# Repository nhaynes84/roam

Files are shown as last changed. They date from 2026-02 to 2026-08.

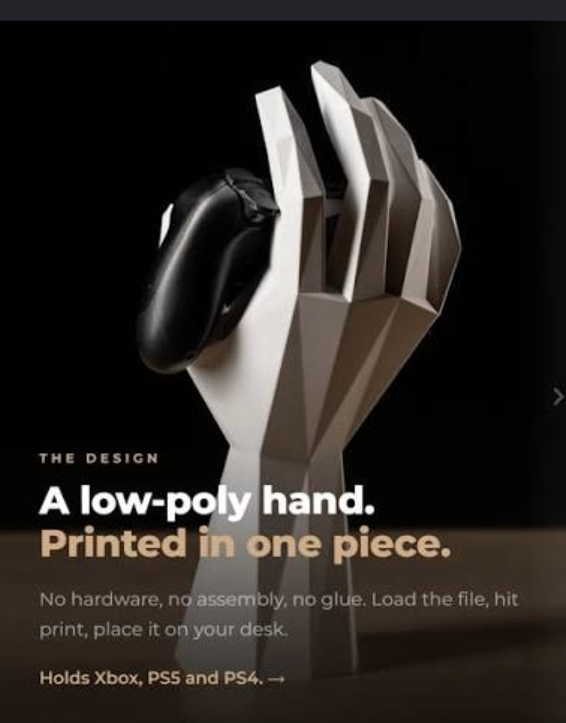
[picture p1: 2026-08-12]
roam-touch/cad/ref/lowpoly-3-printed-hand.png

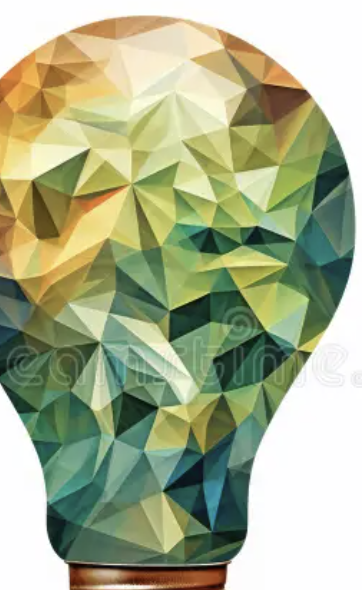
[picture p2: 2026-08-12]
roam-touch/cad/ref/lowpoly-1-bulb.png

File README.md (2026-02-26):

# Roam

Wrist-mounted tactile controller for hands-free AI interaction. Four buttons, OLED display, haptic feedback — strapped to your forearm, operated by the opposite hand.

**Hardware**: Raspberry Pi Pico 2 W, 1.3" OLED (SH1106), 4x tactile buttons, vibration motor, LED, 502535 LiPo battery.

**Firmware**: MicroPython running on the Pico 2 W.

**Housing**: 3D-printed case designed in OpenSCAD — ergonomic half-moon dome shape.

## Project Structure

```
roam/
├── firmware/          # MicroPython source (flashed to Pico)
│   ├── main.py        # Entry point
│   ├── buttons.py     # Button input + debounce
│   ├── display.py     # OLED rendering
│   ├── haptics.py     # Vibration motor control
│   └── config.py      # Pin assignments, settings
├── housing/           # OpenSCAD parametric case design
│   ├── common.scad    # Shared dimensions
│   ├── roam_case.scad # Top shell (dome)
│   ├── roam_lid.scad  # Bottom lid
│   └── render.sh      # STL render script
├── hardware/          # Wiring docs
│   ├── schematic.md   # Full wiring diagram
│   └── pinout.md      # GPIO allocation table
├── tests/             # Test scripts
├── Makefile           # Flash/reset/repl shortcuts
└── CLAUDE.md          # Claude Code project instructions
```

## Prerequisites

- **MicroPython**: Install the Pico 2 W MicroPython UF2 firmware
  - Download from [micropython.org](https://micropython.org/download/RPI_PICO2_W/)
  - Hold BOOTSEL, plug USB, drag UF2 to the mounted drive
- **mpremote**: `pip install mpremote`
- **OpenSCAD** (optional, for housing edits): `brew install openscad`

## Flash Firmware

```bash
# Copy all firmware files to Pico
make flash

# Or manually:
mpremote cp -r firmware/ :

# Reset the board
make reset
```

## Development

```bash
# Open REPL
make repl

# Flash + reset in one step
make deploy

# Render housing STLs
make render
```

## Wiring

See [hardware/schematic.md](hardware/schematic.md) for full wiring diagram and [hardware/pinout.md](hardware/pinout.md) for GPIO allocation.

Key connections:
- **I2C0** (GP4/GP5) → OLED display
- **GP10-13** → 4 tactile buttons (active low, internal pull-ups)
- **GP15** → Vibration motor via NPN transistor
- **GP16** → Status LED via 100Ω resistor
- **VSYS** ← TP4056 battery charger output

## 3D Printing

The housing is designed for FDM printing:
- **Case (dome)**: Print upside-down, 0.2mm layers, 3-wall, 20% infill
- **Lid**: Print flat-side down, 0.2mm layers
- **TPU pads**: Print the pad zones from roam_lid in TPU for forearm comfort

Render STLs:
```bash
cd housing
chmod +x render.sh
./render.sh          # full quality
./render.sh --fast   # quick preview
```

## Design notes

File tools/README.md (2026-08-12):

# Roam Tools — pushing a message to the wrist

The user wears ROAM Touch so he does not have to sit at the computer. These are
the tools that put something on it.

⚠️ **BLE is retired (2026-08-11).** `roam-send` (Swift/CoreBluetooth) and the
127-byte chunking are history — see git log if you ever need them. ROAM Touch is
a phone on the tailnet, reached over the network from anywhere.

## The one rule

```
agent / hook / script          the hub                     the bridge          the phone
   roam-msg  ──POST /notify──▶  decides: push or not  ──WS──▶  roam-push  ──adb──▶  📱
```

**`roam-msg` is the only thing you call. It never touches the device.**

The hub owns the notification policy — *reply where the last message came from*:
a prompt typed in tmux means he is at the keyboard, so its outcome (and every
status line about it) stays quiet; a message sent from ROAM means the answer
belongs on ROAM. That rule lives in exactly one place, `hub/hub.py`
(`_coverage_for`), and everything that wants the wrist obeys it by going through
the hub.

It was not always so. `roam-msg` used to shell straight to `adb`, so the policy
governed outcomes and nothing else and the phone rang all day while he sat two
feet from the screen it was about. Owner: *"what's the point of a 'hub' if all
traffic doesn't go through it..."*

## `roam-msg` — the client

```bash
~/Projects/roam/tools/roam-msg "Build complete. 0 errors."
~/Projects/roam/tools/roam-msg --pane 3 "needs your input"
```

* Attributes the message to `$TMUX_PANE` automatically, which is what lets the
  hub apply "he is typing in that pane". `--pane N` overrides it. With no pane
  at all (launchd, cron, ssh) it claims nothing and the hub files it on the
  `@host` channel, where nothing covers it, so it pushes.
* Prints what the hub decided — `%3 — no push (covered by tmux-input)` — so a
  silent send is never indistinguishable from a broken one.
* Lands in the ledger either way. `memsearch "…" --source ledger` finds it later.
* **If the hub process is not running the message goes into the ledger**, not to
  the device and not to a file. Everything here is one box, so an unreachable
  hub is a stopped process — and a stopped hub is a deaf bridge, so nothing
  could deliver anyway; an adb push at that moment would be the only thing
  still arriving on his wrist, reading as a healthy pipeline while every real
  outcome is stalled. The row lands in `hub.sqlite` flagged `pending`
  (`meta.offline: true`), and the hub adopts and pushes it on its next poll. So
  the message arrives late rather than never, from one store of record.
  Bounded: past `MAX_PENDING` (200) waiting messages it is dropped and says so.
* Env: `ROAM_HUB`, `ROAM_HUB_TOKEN_FILE`, `ROAM_HUB_TIMEOUT`.

## `roam-notify` — fire and forget

`roam-msg` backgrounded with output discarded. For hooks that must not block or
print.

## `roam-push` — ⚠️ the device transport, not for you

The only program that speaks to the phone (`adb ... cmd notification post`). It
holds no policy: told to post, it posts. **Only the bridge
(`com.talos.roam-bridge`) runs it.** Calling it by hand bypasses every rule
above and rings his phone while he is reading the pane it is about — which is
the exact bug the split exists to fix.

It makes a **sound**, and cannot be silenced from here: `cmd notification post`
hardcodes channel `shellcmd` at `IMPORTANCE_DEFAULT`, and Android 10 (SDK 29, on
the device) has no `cmd notification` subcommand for importance. The fix is for
Nexus to post these itself on an `IMPORTANCE_LOW` channel — it already runs a
foreground service with one and already holds the hub socket — after which the
adb path retires entirely. Failing that, one long-press → *Silent* on a ROAM
notification locks the channel down for good.

## Tests

`roam-msg` is a hub client, so its tests live with the hub:

```bash
cd ~/Projects/roam/roam-touch/hub && .venv/bin/python -m pytest -q
```

`tests/test_roam_msg.py` asserts the architecture, not just the behaviour: the
client cannot reach the device, does not second-guess the hub, and the bridge
does not shell out to the client (which would notify itself in a loop).

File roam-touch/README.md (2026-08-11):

# ROAM Touch — a forearm terminal for the AI stack

Spec locked 2026-08-11. **Nothing built.**

> ⚠️ **This supersedes the 2026-08-10 revision of this file**, which specified an
> ESP32-3248S035C ("CYD") desk console. None of that survives — not the board, the form factor,
> the power model, or the audio plan. See [Why the CYD died](#why-the-cyd-died).

★ **This absorbs the wrist Roam.** They are no longer complementary devices. One arm-mounted unit
does target selection, push-to-talk, and display.

## THE THESIS

> **"A functional arm-strapped computer, voice-controlled predominantly, that frees me from
> sitting at a computer. NOT a phone strapped to my arm."** — owner, 2026-08-11

Voice is the input. The screen reads output and confirms input — you never *drive* from it. This is
not an aesthetic project; function first. Read this before proposing any UI.

## WHAT IT IS

A forearm bracer with a flip-up AMOLED panel, running Linux, that acts as a control
surface for every Claude session on every box you own — at home over WiFi, or anywhere over
Tailscale.

Think Slack, for AI tools, on your arm. **N devices × N targets; each target is one channel with
one call/response thread.** For V1, a channel is a tmux pane running Claude.

The interaction loop:

1. Pick the target channel on the touchscreen.
2. Push to talk. Whisper (already running on talos) transcribes it.
3. Panel shows **"send «transcript» to «channel»?"** → Send / Redo / Cancel.
   One confirmation covers both the words *and* the routing, so a good command can't land in the
   wrong session.
4. **Receipt** comes back immediately — it got there.
5. **Outcome** arrives whenever it's done, into that channel's thread, to read or hear.

## WHY LINUX, NOT AN MCU

★ **An ESP32 cannot run Tailscale.** That single fact drove the entire redesign.

Every earlier version of this document contorted itself around that limitation — BLE tethering to
a phone that *could* reach the tailnet, two transport paths, a protocol written twice. Moving to
Linux deletes all of it: the device is just a tailnet node, and "local" and "remote" become the
same code path with no phone in the loop.

It also hands back, for free: a native UI instead of LVGL partial buffers on 520 KB of SRAM,
working audio through ALSA, and a real application platform.

## LAYOUT

| where | contains |
|---|---|
| **Panel** (moves) | CM4 + 3.92" AMOLED 1080×1240, **married** so DSI never crosses the hinge · aluminium backplate · memory-LCD status strip on the outer face |
| **Base** (fixed) | BBQ20KBD keyboard, 5000 mAh cell stacked beneath it |
| **Band** | ESP32-C6 companion. The strap is a partial cuff, not a full wrap. |
| **Across the hinge** | power + keyboard I2C/USB **only** — nothing fast, nothing fragile |

Lid position is sensed by a **magnet in the panel and a hall sensor in the base**, so *zero*
conductors cross the hinge for sensing, and there's no switch to wear out.

## COMPUTE — Raspberry Pi CM4 (2 GB, eMMC, external antenna)

- ⚠️ **Pi Zero 2 W has no DSI at all** (CSI only). It cannot take this panel natively.
- **Radxa Zero 3W** is tempting — 65×30 mm, WiFi 6 — but RK3566 mainline support lags Raspberry
  Pi's by a wide margin, which means writing the panel driver inside a vendor BSP kernel.
- **CM4 wins on display stack**, which is the scarce resource here. Not CPU.
- **eMMC, not SD** — boot speed is load-bearing (see power states) and SD cards corrupt under the
  abrupt power cuts the companion performs.
- **External antenna** — a body absorbs 2.4 GHz. Mount it on the outer face, away from the arm.

## ⚠️⚠️ HARD GATE: NO PANEL WITHOUT A DATASHEET

The AMOLED is not a Pi-supported display. Its timings and init sequence get written by hand from
the manufacturer's documentation.

**No datasheet → DSI is impossible.** The fallback is an HDMI→MIPI driver board, which works
precisely because it contains a controller that already knows the panel. Plenty of sellers ship
these modules with nothing but a wiring photo. **Never buy on specs alone.**

## POWER — three states

| state | on | draw | wake |
|---|---|---|---|
| open / active | Linux + AMOLED | 1–2 W | — |
| closed, **warm** (recent use) | Linux idling, screen off | ~300 mA | instant |
| closed, **cold** (>30 min idle) | companion only, Linux **power-gated** | ~110 µA | boot |

At 5000 mAh: hours active, 2–3 days of instant-on standby, months truly stowed. The warm→cold timer
means you never eat a boot mid-use, only when returning hours later.

### ⚠️ Do not chase suspend-to-RAM

ARM Linux suspend is a swamp. PinePhone Pro draws **1250 mW in s2idle**; most postmarketOS mainline
devices lack runtime power management entirely; where it exists it fails intermittently (suspend
breaking on certain kernels, or when the charger is connected).

The one platform that does it well — PinePhone, ~100 h idle — gets there via **crust**, firmware
running on a *separate co-processor* whose only job is babysitting power. The mobile-Linux world
independently invented our companion architecture.

**So: power-gate instead.** Boot time is tractable engineering; suspend is an open-ended bug hunt.

## COMPANION — ESP32-C6

Owns the WebSocket to the hub, the hall sensor, the haptic motor, the status strip, and the CM4's
power rail.

- **C6 specifically, for WiFi 6 TWT**: ~110 µA while associated, versus 2–5 mA on legacy DTIM.
  ⚠️ TWT requires a WiFi 6 AP *and* is optional in 802.11ax — verify per router. "WiFi 6" on the
  box is not sufficient.
- ⚠️ **nRF52840 / XIAO is disqualified: no WiFi.** It could only reach the hub via the phone,
  reinstating the dependency Linux just removed. Its excellent idle draw is real and irrelevant.
- ★ **Don't poll while closed.** An idle WebSocket with DTIM-aligned keepalives costs less than
  repeated wake/handshake/teardown, *and* delivers instantly.
- Message lands while stowed → status strip shows it, haptic buzzes → flip open and it's already
  there. Boot latency hides behind reading you'd be doing anyway.

## HUB AND CHANNELS

The hub is **talos** — always-on, on the tailnet. Channels have history: an outcome may land
minutes after the command while you're looking at something else. **The hub holds state; the panel
is only a view.** The ESP32 could never hold this itself, and doesn't have to.

Per device: discover with `tmux list-panes -a -F`, route with `send-keys -t %3`, read back with
`capture-pane`. Every box runs the same small agent and advertises its panes.

- ⚠️ **Key channels on tmux pane IDs (`%3`), never `session:window.pane` indices.** Indices
  renumber when panes close, so channels would silently re-point at the wrong pane — the worst
  possible failure for a device whose entire job is "send this to exactly that."
- ★ **The receipt and outcome signals already exist.** The "Sent" and "Ready" hooks described in
  `../CLAUDE.md` fire on prompt-submit and response-finish. They need to POST to the hub tagged
  with `$TMUX_PANE` instead of pushing straight to BLE.

## SOFTWARE SPLIT

STT and the hub link are **system services**, so one global PTT gives every application voice input.

★ **The channel client is app #1, and V1 ships only it.** "Run network diag", "ssh to argus" are
things you *say to a channel*, not separate apps you open — a launcher would be phone thinking.
More apps when they earn it: **Home Assistant is the obvious second**, and it closes the loop on
the original "00s smart-home controller" idea. It also reuses the same Whisper/Piper services the
HA satellites already share. **Lean, not closed** — it's Linux, so don't design against other uses;
just don't build for needs that don't exist yet.

Useful test for anything proposed later: if it fits *pick target → speak → confirm → read result*,
it belongs. If it needs you poking at the screen, it's the phone-on-your-arm thing.

- **Native toolkit, not Chromium.** A browser at 1080×1240 is exactly what would force CM5-class
  compute and a thermal problem. A native UI runs comfortably on far less.
- ⚠️ Keep a minimal text-entry path. **You cannot voice-type a password** — you'd say it out loud
  and Whisper would mangle it anyway. That is what the keyboard is for, not general typing.

Voice services already live on talos under launchd:

| leg | service | endpoint |
|---|---|---|
| speech → text | Wyoming faster-whisper `small-int8` | `talos.local:10300` |
| text → speech | Wyoming Piper `en_US-lessac-medium` | `talos.local:10200` |

## THERMAL — the plastic does not conduct, the metal does

PLA/PETG is ~0.13–0.25 W/m·K. Aluminium is ~167. Through-thickness conduction through a 2 mm wall is
fine; ★ **lateral spreading is what dies.** Heat from a ~15 mm chip punches straight through in a
hot spot and 95% of the panel contributes nothing. A metal spreader on the hot path is not optional.

- ★ **Thermals match the duty cycle.** Panel **open** = CM4 working = both faces in free air, the
  best-ventilated surface on the device. Panel **closed** = CM4 power-gated = no heat to dump.
  Compute belongs in the panel; the battery — the heavy part — stays in the base.
- ⚠️ Don't sit the CM4 behind the emissive area. OLEDs age faster hot. Offset it toward the hinge.
- Fans are unnecessary for a bursty 1–2 W load. If one is ever added, **seal it inside** and trigger
  on temperature — on a body-worn device **sweat ingress is the real killer, not heat.** Never open
  a vent to the outside.

## MATERIALS — per function, not one choice

| part | material | why |
|---|---|---|
| hinge, structure | **PA-CF** | stiff, HDT >100 °C. ⚠️ hygroscopic — keep off skin and sweat |
| skin contact, cosmetic shell | **PETG / PCTG** | no moisture uptake, adequate UV. PCTG buys *toughness*, **not** heat — same ~85 °C Tg |
| panel backplate, hot path | **aluminium** ★ LOCKED | ~167 W/m·K at 2.7 g/cm³ — better conductor *and* 1/3 the weight of brass |

⚠️ **Never PLA.** Glass transition 55–60 °C; it will deform behind the board and in a hot car.

### Backplate sourcing — aluminium, 1 mm

**SendCutSend** takes DXF/DWG/EPS/AI/STEP with instant pricing and no minimums, and offers laser
engraving as an add-on. 2–4 day lead, free US shipping.

A 100×70×1 mm plate is **~19 g in aluminium**. The plate hangs off the hinge, so its mass is
cantilevered, not carried.

⚠️ **Brass was considered and rejected (2026-08-11).** It was an *aesthetic* pick presented as a
thermal one — thermally fine at ~120 W/m·K, but 3× the density (~60 g for the same plate) for zero
functional gain, on a device with no aesthetic brief. Noted so it doesn't get re-proposed.

Reference, if a copper alloy is ever revisited: **CO2 lasers cannot cut brass or copper** — too
reflective at 10.6 µm, and the reflection can damage the tube. Those need a fiber laser (1.06 µm)
or waterjet. Aluminium is unaffected.

## WHY THE CYD DIED

The 2026-08-10 concept was an ESP32-3248S035C desk console. Every constraint that shaped it turned
out to be soft, except one:

- **"The board is what I own."** It's a wall/desk board: no PMU, no charger, no fuel gauge, no
  battery connector, 5 V input, 101×55 mm of rigid bare-backed PCB. Wrong for worn-and-battery.
- **"480×320 is the screen size available."** That was a catalog limit, not a physical one. Phone
  AMOLED panels and HDMI→MIPI driver boards exist; the ESP32 dev-board ceiling was irrelevant.
- **"307 KB framebuffer against 520 KB SRAM."** An artifact of using an MCU at all.
- **"Echo is the hard problem."** It was the hard problem *for an always-listening single-mic
  panel*. Push-to-talk plus a hinged, stowable device makes it mostly moot.
- **⚠️ "An ESP32 cannot run Tailscale."** This one was real, and it is the reason for every change
  above.

## OPEN

- Bracer internal volume (drives final battery and board fit)
- Exact ESP32 placement on the band
- Where the status strip sits, which determines whether SPI crosses the hinge
- Which SSID talos lives on — TWT needs the WiFi 6 network, and moving talos there also unthrottles
  its 6E radio (it currently negotiates 11ac). Note it would need a fresh DHCP reservation.

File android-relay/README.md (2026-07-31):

# Roam Android Relay

Native Android relay for the Roam phone-owned mode.

Flow:

```
Roam/XIAO BLE -> Android foreground service -> TCP over Wi-Fi -> Mac receiver
```

The app scans for `Roam`/`Roam2`, connects to service `FF00`, subscribes to:

- `FF02` action/status notifications
- `FF03` audio notifications

It writes `FF04` control commands back to Roam. For the first vertical slice, pressing the Roam Android dictation action toggles mic streaming by sending `start audio` / `stop audio`.

The Mac receiver listens on TCP port `8765` by default:

```bash
node scripts/roam-relay-receiver.mjs
```

For the current tmux assistant workflow, run the durable receiver from the repo:

```bash
scripts/start-roam-relay-tmux.sh 8765
```

This starts a `roam-relay` tmux session, transcribes Roam PTT audio with local
`mlx_whisper`, and injects transcripts into the configured tmux target with
`ROAM_RELAY_INJECT_MODE=tmux-submit`. The default `ROAM_TMUX_TARGET` is `0:0`;
set it explicitly when the assistant lives in another tmux window.

Status feedback goes back to Roam through the same socket. The receiver sends
frame type `3` text to Android; Android chunks it into `FF01` writes for the
wrist display. In `tmux-submit` mode the message is already submitted when Roam
shows `Sent`. In draft mode (`ROAM_RELAY_INJECT_MODE=tmux`) Roam shows `Ready`;
press Middle short/action `10` to submit after that.

Long receiver feedback is split into numbered one-screen pages before it is
broadcast. The receiver sends the final page first and page `1/N` last, so
Roam's newest-message view starts at the beginning and the older/down scroll
button moves through the rest of the reply.

The relay service source also waits 300 ms after each `FF01` text write before
draining the next GATT operation. This protects the current firmware path where
text writes are consumed by the main loop instead of acknowledged at the
application layer.

Manual updates can be pushed through the relay without taking over BLE:

```bash
scripts/roam-relay-notify.mjs "Build complete"
```

For today's work Mac, set the Android app host to this Mac's LAN IP. On the
2026-07-30 workbench that was `192.168.86.63`.

When the Mac mini becomes the always-on business proxy, install the receiver
there and point the Android app at the Mac mini's reserved LAN IP:

```bash
scripts/install-roam-relay-launchd.sh
```

That installs `~/Library/LaunchAgents/com.roam.relay-receiver.plist`, keeps the
receiver alive, and writes logs to `~/Library/Logs/Roam/relay.out.log` and
`~/Library/Logs/Roam/relay.err.log`. The rolling WAV capture is
`~/Library/Logs/Roam/roam-relay-latest.wav`.

Per-session WAVs are under `~/Library/Logs/Roam/sessions/`. Transcript and
injection audit records are appended to `~/Library/Logs/Roam/transcripts.jsonl`.

To capture decoded relay audio for inspection:

```bash
node scripts/roam-relay-receiver.mjs --wav /tmp/roam-relay.wav
```

The receiver frame format is `[type:1][length:2 big-endian][payload]`; type `1`
is event JSON and type `2` is the binary `FF03` audio packet.

The current debug APK is built at:

```bash
android-relay/app/build/outputs/apk/debug/app-debug.apk
```

For bench testing over ADB on current Android builds, start through the visible
Activity path. This avoids foreground-service launch denial while the phone is
locked or dreaming:

```bash
adb shell input keyevent KEYCODE_WAKEUP
adb shell wm dismiss-keyguard
adb shell am start -S -W --user 0 -n io.roam.relay/.MainActivity --es host 192.168.86.63 --ei port 8765 --ez autoStart true
```

The protected broadcast receiver exists for controlled starts when Android
allows them:

```bash
adb shell am broadcast -n io.roam.relay/.RelayControlReceiver -a io.roam.relay.START --es host 192.168.86.63 --ei port 8765
```

Stop it with:

```bash
adb shell am broadcast -n io.roam.relay/.RelayControlReceiver -a io.roam.relay.STOP
```

Build notes:

- Open `android-relay/` in Android Studio.
- The local machine currently has Android SDK/ADB but no `gradle` CLI in PATH.
- Android 12+ requires Bluetooth runtime permissions.
- Android 13+ requires notification permission for the foreground-service notification.
- Android 14+ requires `foregroundServiceType="connectedDevice"` plus the matching permission.

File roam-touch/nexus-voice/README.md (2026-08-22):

# Nexus Voice

Speak to the ROAM Touch channels through Home Assistant. Wake word, then
*"Nexus, add the OPV result to the espresso notes"* — it finds the right
channel, sends it, and speaks the answer back on the device you asked from.

## Why HA is in the middle

The hub binds to the **tailnet address only** (`100.67.237.109:8787`); the LAN
gets connection refused. An ESP32 cannot run Tailscale — the fact that killed
the MCU version of ROAM Touch. So a satellite can never reach the hub directly.

`argus` is the only box on both networks. HA is therefore not a convenience
here, it is the bridge, and the integration lives *inside* it — which also
means it calls `tts.speak` through the service registry and needs no
long-lived access token.

## The loop

```
ESP32-S3 / Sonos ──wake word──▶ HA (argus)
                                  │  Whisper @ talos:10300
                                  ▼
                          local intents first  ──▶ lights, scenes  (<1s)
                                  │ "Nexus, …"
                                  ▼
                          nexus_voice agent ──▶ hub /send ──▶ tmux pane
                                  │
                          "Sent to Gaggia Build."   ◀── spoken immediately
                                  ⋮
                          outcome event ──▶ tts.speak ──▶ same device
```

**Nothing here waits for Claude.** Assist is synchronous and wants an answer in
about a second; a Claude turn takes minutes. The agent acknowledges, and the
answer arrives later as an announcement. That is the hub's own shape — receipt
now, outcome later.

## How a channel is chosen

Three layers, cheapest and most certain first:

1. **String** — exact label, then subset of content words. Free and certain.
2. **Embedding** — `nomic-embed-text` on talos, over the channel's *label plus
   recent history*.
3. **Neither** — spawn a new channel.

Two candidates within `AMBIGUITY_DELTA` produce a question rather than a guess.
Misfiling a note corrupts two threads; one extra second of conversation is
cheaper.

### ⚠️ What the measurements actually said (2026-08-21)

Embedding the **label alone does not work**. "the espresso notes" scored 0.365
against "Gaggia Build", while an unrelated "jeep brake booster" scored 0.504
against the same channel. Short proper nouns carry almost no signal.

Embedding **label + history** fixed the ranking but not the scale — the useful
signal is the **margin between #1 and #2**, not the absolute score:

| utterance | #1 | #2 | margin | correct |
|---|---|---|---|---|
| the espresso notes | 0.508 | 0.435 | 0.073 | ✓ Gaggia Build |
| wrist display font | 0.431 | 0.367 | 0.064 | ✓ Roam Touch |
| the augment board | 0.425 | 0.375 | 0.050 | ✓ Augment |
| jeep brake booster | 0.422 | 0.418 | **0.004** | ✓ spawn |

When nothing fits, the scores go **flat**. That is the only reliable "none of
these" signal available. ⚠️ **n=5** — the threshold fits the measurements, it
is not validated by them. Re-run `tools/probe_routing.py` against real traffic
before trusting it further.

`cwd` is kept but is **not load-bearing**: every live channel on the hub reports
`/Users/talos`, because panes spawn in `$HOME` unless someone passes `cwd`. It
breaks ties and decides nothing.

## Laws this obeys

* **Nothing ever speaks on its own.** Audio fires only for an answer he asked
  for by voice, on the device he asked from. Auto-speak was built into the
  Channels app once and killed within the hour.
* **Speak the `summary`, never the `body`.** Capped at 280 chars, markdown
  stripped — and short enough for a satellite with no echo cancellation, which
  cannot hear you interrupt it.
* **Reply where the last message came from.** A satellite is one more place
  that rule applies to; HA hands us `satellite_id` so it needs no identity
  scheme of its own.

## Layout

| file | what |
|---|---|
| `matcher.py` | which channel — pure, no HA, no network |
| `phrasing.py` | trigger stripping, channel naming — pure |
| `runtime.py` | channel index, embedding cache, hub WS, delivery map |
| `hub.py` · `embeddings.py` | clients |
| `conversation.py` · `__init__.py` · `config_flow.py` | HA glue, decides nothing |

Tests: `.venv/bin/python -m pytest tests/ -q` (53). The HA-facing modules are
verified by importing them against real HA on argus, since HA is not installed
on talos.

## Deployed

`/home/homeassistant/.homeassistant/custom_components/nexus_voice` on **argus**.
Restart HA after changing it: `sudo systemctl restart home-assistant@homeassistant`.

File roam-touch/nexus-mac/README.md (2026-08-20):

# Nexus for macOS

Native SwiftUI client for the ROAM Touch hub (`../hub`, contract in `../hub/API.md`).
Same hub, same channels, same rules as the Android Nexus — this is the desk view.

- Build: `swift build` (Command Line Tools are enough; no Xcode required)
- Test: `swift test`
- Run (dev): `swift run`
- App bundle: `tools/bundle.sh` → `dist/Nexus.app` (ad-hoc signed)

Config resolution order:
1. `ROAM_HUB_URL` / `ROAM_HUB_TOKEN` environment variables
2. `~/.config/roam-nexus/config.json` — `{"base_url": "http://talos:8787", "token": "…"}`
3. On talos itself: `../hub/hub-token.txt` with the default base URL

House rules carried over from the Android client (see `hub/API.md` and the
roam-touch-channels memory before changing behaviour):
- Summary first, body on demand. Never re-derive summaries client-side.
- Nothing speaks or notifies on its own. Coverage/push is the hub+bridge's job.
- Presence covers ONLY the channel on screen. `covers_all` from a client with a
  screen once silenced the wearer's arm for a day.
- Interrupts go through `POST /channels/{pane}/interrupt`, never control bytes
  through `/send`.

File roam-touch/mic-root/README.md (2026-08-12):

# mic-root — temporary-root test for the ROAM Touch built-in microphone

The built-in mic returns pure digital silence and the HAL logs
`start_input_stream: pcm_prepare returned -1` on every configuration. A Bluetooth headset mic
works, which proves AudioFlinger, the HAL framework, tinyalsa and the app are fine — and proves
**nothing** about the codec driver, the ADSP audio firmware or the ACDB calibration, because SCO
bypasses all three. Those three live in the vendor partition that the 8.0 → 10 flash replaced, so
"we broke it in software" and "the hardware is dead" are both still live.

`tinycap` is on the device but `shell` is not in group `audio` (1005), so there is no root-free way
to reach ALSA. This directory is the root-free-of-consequences way to get there.

## Files

| file | what it is |
|---|---|
| `PROCEDURE.md` | the numbered checklist for the owner, plus the recovery path |
| `prepare-boot-image.sh` | host-side: builds the Magisk-patched boot image (already run) |
| `TESTmicroot.sh` | on-device, as root: the capture ladder |
| `TESTmicroot-hal.sh` | on-device, as root: the kernel log under a HAL capture attempt |

The patched image is **not** in git (34 MB binary). It is staged at
`~/pixel/TESTmagisk-boot-sailfish-QP1A.191005.007.A3.img` on both `nicks-macbook-pro` and talos,
sha256 `234c1186c2e05a3c0bbe75b35e5361593b0a340d84d4ec5d0f115f4ed4105c43`.
It is for `fastboot boot` only. Rebuild it with `prepare-boot-image.sh`.

## Verified before anyone touched the phone

- Stock `boot.img` taken from the staged factory image for the exact running build
  (`QP1A.191005.007.A3`), sha256 `b020dba9…b445`.
- Patched on-device with Magisk v30.7's own `boot_patch.sh`, with the flags the Magisk app would
  have computed for this device: `KEEPVERITY=true KEEPFORCEENCRYPT=true PATCHVBMETAFLAG=true
  RECOVERYMODE=false LEGACYSAR=true`.
- `LEGACYSAR=true` is load-bearing. sailfish is a legacy system-as-root A/B device: the boot image
  carries the *recovery* ramdisk and the bootloader passes `skip_initramfs` on a normal boot, so
  the ramdisk is skipped. magiskboot hex-patches the kernel `skip_initramfs` → `want_initramfs`
  so the flag no longer matches and magiskinit (now `/init` in that ramdisk) runs and performs the
  system-as-root mount itself. Confirmed in the patch log:
  `Patch @ 0x017853F6 [736B69705F696E697472616D667300] -> [77616E745F696E697472616D667300]`.
- Re-verified on the finished image: ramdisk `cpio test` → 1 (Magisk-patched), `init` is 200 KB
  (magiskinit), kernel contains `want_initramfs` ×1 and `skip_initramfs` ×0.

## The route the test drives

sailfish's mics are **digital MEMS mics on the WCD9335 (Tasha) DMIC ports**, not analog inputs.
From `/vendor/etc/mixer_paths.xml`, `handset-mic` = `dmic1` + `DEC7 Volume 88`, i.e.

```
MultiMedia1 Mixer SLIM_0_TX = 1      front-end -> SLIMBUS_0_TX backend
AIF1_CAP Mixer SLIM TX7     = 1      codec TX port 7 into the SLIMbus capture stream
SLIM_0_TX Channels          = One
SLIM TX7 MUX                = DEC7
ADC MUX7                    = DMIC
DMIC MUX7                   = DMIC0  bottom mic
IIR0 INP0 MUX               = DEC7
DEC7 Volume                 = 88
```

The other two physical mics ride different decimators and different TX ports: back mic =
`dmic3` (DMIC2 / DEC6 / TX6), top mic = `dmic6` (DMIC5 / DEC5 / TX5). Testing all three separates
"one dead mic" from "the whole capture chain is down".

## Reading the result — what it does and does not prove

| observed | supports | still does NOT prove |
|---|---|---|
| Rung A already fails (front-end alone, no backend) | the ADSP audio session cannot start at all — a firmware/DSP-level fault, not a microphone | which side put the ADSP in that state |
| A/B pass, C onward fail | the fault is on the SLIMbus link to the WCD9335 or in the codec's own bring-up | codec silicon vs codec firmware/driver — both sit behind that boundary |
| A–C pass, D/E/F all fail to **prepare** | the codec is reachable but the DMIC capture chain will not start | that the mics themselves are dead. A cracked mic joint cannot make `pcm_prepare` fail |
| D/E/F **prepare and deliver samples** | the kernel driver, the codec and the ADSP can all bring the capture path up — the failure is above them, in the HAL / ACDB / vendor config, i.e. plausibly ours | that a specific config file is the culprit; that has to be found separately |
| samples arrive but are all-zero on all three mics | the digital chain runs and no acoustic energy reaches it | dead elements vs a DMIC clock that is never driven vs calibration zeroing the decimator |
| samples arrive at a real noise floor (≈ −60 dBFS) and rise on speech | that mic works below the HAL, full stop | nothing further is needed for that mic |

**The honest framing:** a `pcm_prepare` failure is a *session-start* failure. A cracked solder
joint on a mic, or a dead MEMS element, does not make a session fail to start — it makes a session
start cleanly and deliver silence. So this test is a strong discriminator between
"session cannot start" (driver / ADSP firmware / codec bring-up) and "session starts, no sound"
(the mic itself, its clock, or calibration). It is **not** a silicon test. If every rung fails
identically, that points hard away from a single cracked joint and toward the vendor stack, but
the only thing that would settle "we broke it" outright is reflashing the original 8.0 image and
testing the mic first — which costs the whole current setup.

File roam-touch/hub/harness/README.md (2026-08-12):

# Harness tools (copies)

`~/.local/bin/` is not a git repository, so these are **copies** of the owner's live
harness tools as extended for the ledger/session sources. The live files are the ones
that run; these exist so the change is reviewable and recoverable.

* `memindex` — added the `ledger` and `sessions` record sources (chunked by
  `../ledger_index.py`), FTS5 (`chunks_fts_v2`) population and backfill, and a
  `record_files` mtime/size guard so unchanged transcripts are never reparsed.
* `memsearch` — added `--exact` (FTS5 literal match) and the two new sources.

Originals before the change: `~/.local/bin/backups/*.2026-08-11.bak`.

If you edit the live tools, re-copy them here.

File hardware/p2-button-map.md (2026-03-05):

# Roam P2 — Button Command Map

## Button Layout

```
            ┌──────────────── elbow side ────────────────┐
            │                                            │
            │   [Index]  [Middle]  [Ring]  [Pinky]       │  ◄── top face
            │     D0       D1       D2      D3           │
            │                                            │
  USB-C ◄───│                              [Scroll Fwd]  │
  Switch ◄──│                               D8           │  ◄── right side
            │                              [Scroll Back] │
            │                               D9           │
            │                                            │
            └──────────────── wrist side ────────────────┘
```

## Command Map

| Button | Pin | Short Press | Long Press | Double Tap |
|---|-----|---|---|---|
| Index  | D0  | Dictation (macOS 0x00CF) | Tmux pane (Ctrl+B, o) | Scroll Fwd* |
| Middle | D1  | Cycle Mode (Shift+Tab) | BLE Switch (disconnect + re-advertise) | Scroll Back* |
| Ring | D2  | Approve (y + Enter) | Always (Tab + Enter) | Enter |
| Pinky  | D3  | Escape | Kill (Ctrl+C) | — |
| Scroll Fwd | D8 | Next message | Next message | — |
| Scroll Back | D9 | Prev message | Prev message | — |

*Index/Middle double-tap scroll is a fallback for P1 testing (no dedicated scroll buttons).
On P2, use the dedicated D8/D9 thumb buttons instead.

## Action Details

### Index — D0
| Gesture | Action | HID Output | Use Case |
|---|---|---|---|
| Short | Dictation | Consumer key 0x00CF | Start/stop macOS dictation |
| Long | Tmux Pane | Ctrl+B then 'o' | Switch tmux pane |

### Middle — D1
| Gesture | Action | HID Output | Use Case |
|---|---|---|---|
| Short | Cycle Mode | Shift+Tab | Cycle through UI modes |
| Long | BLE Switch | (internal) | Disconnect current host, re-advertise for next |

### Ring — D2
| Gesture | Action | HID Output | Use Case |
|---|---|---|---|
| Short | Approve | 'y' then Enter | Accept Claude Code prompt |
| Long | Always | Tab then Enter | Select "Always allow" option |
| Double | Enter | Enter | Confirm without 'y' prefix |

### Pinky — D3
| Gesture | Action | HID Output | Use Case |
|---|---|---|---|
| Short | Escape | Escape | Cancel / dismiss |
| Long | Kill | Ctrl+C | Kill running process |

### Scroll — D8 / D9
| Button | Action | HID Output | Use Case |
|---|---|---|---|
| D8 (Fwd) | Scroll Fwd | (local) | View newer BLE text message |
| D9 (Back) | Scroll Back | (local) | View older BLE text message |

Scroll buttons are local-only — they navigate the on-screen message ring buffer,
no BLE HID output. Short haptic buzz (40ms) on scroll.

## Timing

| Parameter | Value | Notes |
|---|---|---|
| Debounce | 50ms | Ignore presses shorter than this |
| Long press | 600ms | Fires while still held |
| Double tap window | 300ms | Max gap between taps |
| Action fade | 3000ms | Action name on screen duration |
| Screen dim | 10s | Dim after inactivity |
| Screen off | 30s | Power off after inactivity |

## Haptic Feedback

| Event | Motor pulse | Pattern |
|---|---|---|
| Button action (HID) | 80ms | Single buzz |
| Scroll | 40ms | Short buzz |
| BLE text received | 60-80-60ms | Double buzz |

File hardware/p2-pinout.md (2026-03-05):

# Roam P2 — XIAO nRF52840 Sense GPIO Allocation

## Pin Assignment Table

| Pin  | nRF GPIO | Function | Direction | Notes |
|---|---|---|---|---|
| D0 | P0.02 | Button 1 | Input | Index (Dictation) — internal pull-up |
| D1 | P0.03 | Button 2 | Input | Middle (Mode) — internal pull-up |
| D2 | P0.28 | Button 3 | Input | Ring (Yes) — internal pull-up |
| D3 | P0.29 | Button 4 | Input | Pinky (No) — internal pull-up |
| D4 | P0.04 | I2C SDA | Bidir | OLED display (TWIM1) |
| D5 | P0.05 | I2C SCL | Bidir | OLED display (TWIM1) |
| D6 | P1.11 | Motor PWM | Output | NPN base via 1kΩ |
| D7 | P1.12 | Status LED | Output | Via 100Ω resistor |
| D8 | P1.13 | Scroll Fwd | Input | Thumb button — internal pull-up|
| D9 | P1.14 | Scroll Back | Input | Thumb button — internal pull-up|
| D10  | P1.15 | (Available) | — | Reserved for future use |
| VBAT | — | Battery ADC | Input | Built-in, nRF52 internal ADC |

## Board Layout

```
              ┌───USB-C───┐
        D0  ──┤  [RST]    ├── 5V (VUSB)
        D1  ──┤           ├── GND
        D2  ──┤           ├── 3V3
        D3  ──┤           ├── D10
        D4  ──┤  (SDA)    ├── D9
        D5  ──┤  (SCL)    ├── D8
        D6  ──┤           ├── D7
              ├───────────┤
              │  BAT(JST) │
              └───────────┘

  [RST] = tiny tactile switch next to USB-C (top side)
  Double-click RST to enter UF2 bootloader
```

## I2C Configuration

| Bus | Peripheral | Pins | Speed  | Devices |
|---|---|---|---|---|
| TWIM1 | NRF_TWIM1 | D4, D5 | 100kHz | OLED display |

**CRITICAL: Must use TWIM1, not TWIM0.** The Bluefruit softdevice claims TWIM0
and its shared IRQ (`SPIM0_SPIS0_TWIM0_TWIS0_SPI0_TWI0`). Using TWIM0 with
Bluefruit causes I2C data writes to timeout. The firmware uses direct TWIM1
register access (not the Wire library) with proper timeouts.

**Do NOT use the Seeed BSP Wire library** — it has infinite spin loops
(`while(!EVENTS_STOPPED)`) with no timeout. A stuck I2C bus will lock the MCU.

## Display Options

### Option A: SH1106 1.3" 128×64 (Build 2A — current)

The same small screen used on P1. Proven reliable on I2C.

- **VCC from battery through switch** — charge pump works at LiPo voltages (3.7–4.2V)
- **No reset pin** on the 4-pin module (`PIN_DISPLAY_RST = U8X8_PIN_NONE`)
- **Column offset of 2** — SH1106 has 132-column RAM for a 128-column display

**Wiring (4-pin module):**

| OLED Pin | Connect to | Notes |
|---|---|---|
| GND | GND | |
| VCC | Switched BAT+ | Through power switch |
| SCL | D5 | |
| SDA | D4 | |

**U8g2 constructor:**
```cpp
#define DISPLAY_TYPE U8G2_SH1106_128X64_NONAME_F_HW_I2C
```

### Option B: SSD1309 2.42" 128×64 (Build 2B — pending)

Larger screen, 3.3V native (works on battery). Ships in SPI mode — needs
resistor mod for I2C. **Not yet proven working on I2C.**

- **3.3V compatible** — works on battery power
- **Requires resistor modification** for I2C mode (see below)
- **Reset pin**: connect RES to a GPIO or tie to 3V3
- **No column offset** (unlike SH1106)

**I2C resistor mod (back of module, under ribbon cable):**
Locate pads R9, R10, R11, R12 (may be hidden under the flex cable):
- Bridge R9 (3-pad selector — bridge middle pad to R9 side, not R8 side)
- Bridge R10, R11, R12
- Remove any existing bridges on R1–R4 (visible side)

The BS[2:1:0] pins set the interface: `010` = I2C mode.

**Wiring (7-pin header, I2C mode):**

| OLED Pin | Connect to | Notes |
|---|---|---|
| GND | GND | |
| VCC | 3V3 | 3.3V native |
| SCL | D5 | |
| SDA | D4 | |
| RES | D10 (or 3V3)  | Reset — tie high or use GPIO |
| DC | GND | I2C address select: GND = 0x3C |
| CS | GND | Not used in I2C, tie low |

**U8g2 constructor:**
```cpp
#define DISPLAY_TYPE U8G2_SSD1309_128X64_NONAME0_F_HW_I2C
```

**Status**: Commands (control byte 0x00) work but data writes (control byte 0x40)
timeout — the resistor mod may not have fully switched from SPI to I2C mode.
Needs a pre-configured I2C module or verified mod procedure.

## Battery

- Built-in JST SH 1.0mm connector — plug in LiPo, no external charger needed
- Charging via USB-C (onboard charging circuit)
- Battery voltage readable via `PIN_VBAT` (nRF52 internal ADC)
- No GP25 / CYW43 complications like P1

## Built-in Sensors (XIAO nRF52840 Sense)

- **IMU**: LSM6DS3 (6-axis accel + gyro) — future: wake on wrist supination
- **Mic**: PDM microphone — available if needed

## Hardware Gotchas

- **TWIM0 conflicts with Bluefruit**: The BLE softdevice uses the same peripheral
  group. I2C display MUST use TWIM1 with direct register access. See `display.cpp`.
- **Wire library has no timeouts**: Seeed BSP's `Wire_nRF52.cpp` spins forever
  waiting for TWIM events. A stuck bus = bricked firmware. Use raw TWIM registers.
- **SH1106 works on LiPo voltage**: Charge pump runs fine at 3.7–4.2V through switch.
- **LED_BUILTIN is active LOW**: `LOW` = on, `HIGH` = off. Red LED on P0.26.
- **Reset button**: Tiny switch next to USB-C. Double-click for UF2 bootloader
  (shows as "XIAO-SENSE" USB drive on Mac).
- **No USB serial without firmware**: If firmware doesn't call `Bluefruit.begin()`
  or `Serial.begin()`, USB CDC won't enumerate. Double-click reset to recover.
- **Port flapping**: Serial port alternates between `/dev/cu.usbmodem101` and
  `/dev/cu.usbmodem1101` between flashes. Always check `arduino-cli board list`.

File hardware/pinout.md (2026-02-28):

# Roam — Pico 2 W GPIO Allocation

## Pin Assignment Table

| GPIO | Pin # | Function | Direction | Notes |
|---|---|---|---|---|
| GP4  | 6 | I2C0 SDA | Bidir | OLED display, 4.7kΩ pull-up |
| GP5  | 7 | I2C0 SCL | Bidir | OLED display, 4.7kΩ pull-up |
| GP10 | 14 | Button 1 | Input | Dictation — internal pull-up |
| GP11 | 15 | Button 2 | Input | Mode — internal pull-up |
| GP12 | 16 | Button 3 | Input | Yes — internal pull-up |
| GP13 | 17 | Button 4 | Input | No — internal pull-up |
| GP15 | 20 | Vibration PWM  | Output | NPN base via 1kΩ resistor |
| GP16 | 21 | Status LED | Output | Via 220Ω resistor |
| VSYS | 39 | Power input | Power | From TP4056 via slide switch |
| GND  | 38 | Ground | Power | Common ground |
| 3V3  | 36 | 3.3V output | Power | From onboard regulator |

## Board Silkscreen Labels (Pimoroni Pico Plus 2 W)

USB port at top. Labels printed on PCB next to castellated pads.

```
  Left edge (top to bottom):       Right edge (top to bottom):
   0                                VB
   1                                VS
   -  (GND)                         -  (GND)
   2                                3E
   3                                +  (3V3)
   4  ◄ SDA                         VA
   5  ◄ SCL                         28
   -  (GND)                         -  (GND)
   6                                27
   7                                26
   8                                RU
   9                                22
   -  (GND)                         -  (GND)
  10  ◄ Btn Index (Dictation)       21
  11  ◄ Btn Middle (Mode)           20
  12  ◄ Btn Ring (Yes)              19
  13  ◄ Btn Pinky (No)              18
   -  (GND) ◄ shared button GND     -  (GND)
  14                                17
  15  ◄ Motor PWM                   16 ◄ LED PWM
```

**Button wiring: 5 solder joints on the left edge, bottom cluster.**
Pads 10, 11, 12, 13 each get a wire to one side of a switch.
The `-` (GND) pad between 13 and 14 is shared ground for all four switches.

## Available GPIOs (Reserved / Unused)

| GPIO | Status | Notes |
|---|---|---|
| GP0 | Available  | UART0 TX — future expansion |
| GP1 | Available  | UART0 RX — future expansion |
| GP2 | Available  | SPI0 SCK — future expansion |
| GP3 | Available  | SPI0 TX — future expansion |
| GP6-9  | Available  | General purpose |
| GP14 | Available  | Adjacent to motor pin |
| GP17-22| Available  | General purpose |
| GP23 | Reserved | Wireless SPI CS (internal) |
| GP24 | Reserved | Wireless SPI IRQ (internal) |
| GP25 | Reserved | Wireless SPI CS (internal) |
| GP26-28| Available  | ADC capable — battery monitoring?  |
| GP29 | Reserved | ADC for VSYS/3 voltage divider |

## Bus Configuration

| Bus | Pins | Speed | Devices |
|---|---|---|---|
| I2C0  | GP4, GP5 | 400kHz  | SH1106 1.3" OLED |

## ADC Notes

- **GP26 (ADC0)**: Could be used for battery voltage monitoring via voltage divider
- **GP29 (ADC3)**: Connected internally to VSYS/3 — reads system voltage

## Hardware Gotchas

- **GP25**: Do NOT use as GPIO — shared with CYW43 wireless SPI. Setting it as OUTPUT and toggling it kills BLE completely. Battery ADC reads work without GP25 coordination.
- **BLE re-pairing**: After every firmware flash, must "Forget This Device" on macOS Bluetooth and re-pair fresh. Stale bonding keys cause silent connection failure (shows "paired" but won't connect).
- **Motor voltage**: Coin motors rated 3V don't spin at 3.3V through a 2N2222 — need VBUS (5V) from the + pad. Flyback diode essential.
- **LED type**: Use plain single-color LEDs only. "Fast flashing RGB" LEDs have a built-in IC that cycles colors regardless of GPIO state — they can't be controlled.
- **OLED VCC must be 5V**: The SH1106 OLED needs 5V on VCC (+ pad / VBUS). At 3.3V the I2C bus works (device detected at 0x3C, commands ACK) but the OLED panel won't light up — the internal charge pump needs higher voltage. I2C data lines (SDA/SCL) stay at 3.3V logic which is fine.
- **OLED + BLE I2C**: U8g2 HW_I2C works alongside btstack BLE when the screen is on 5V. U8g2 SW_I2C (bit-bang) is broken on RP2350 — don't use it. At 3.3V, HW_I2C hangs because the unresponsive screen causes Wire to block indefinitely.
- **I2C bus recovery after flash**: Entering BOOTSEL mode can leave the OLED's I2C state machine stuck (MCU resets but screen stays powered). If I2C scan fails after flashing, power-cycle the screen (unplug/replug the harness).

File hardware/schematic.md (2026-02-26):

# Roam — Wiring Schematic

## Power Circuit

```
                  ┌──────────┐
  LiPo 3.7V ──── │ TP4056   │ ──── Slide Switch ──── VSYS (Pico)
  (502535)   ──── │ Charger  │                         GND  (Pico)
                  └────┬─────┘
                       │
                   USB-C IN
                 (charge only)
```

- **Battery**: 502535 LiPo, 3.7V 400mAh
- **TP4056**: Micro/USB-C charging module with DW01 protection
- **Slide switch**: MSK-12C02 style, between TP4056 OUT+ and Pico VSYS. Side-mounted in housing with red/green indicator recesses visible through the shell
- **Pico VSYS**: Accepts 1.8–5.5V, has onboard 3.3V regulator

## I2C Bus — OLED Display

```
  Pico GP4 (SDA) ────┬──── OLED SDA
                      ├──── 4.7kΩ ──── 3V3
  Pico GP5 (SCL) ────┬──── OLED SCL
                      ├──── 4.7kΩ ──── 3V3
  3V3 ─────────────────── OLED VCC
  GND ─────────────────── OLED GND
```

- I2C0 on GP4/GP5 (default I2C0 pins)
- 4.7kΩ pull-ups to 3V3 (some OLED modules include onboard pull-ups — check before adding)
- Bus speed: 400kHz

## Buttons (Active Low)

```
  GP10 ──── Button 1 (Dictation) ──── GND
  GP11 ──── Button 2 (Mode)      ──── GND
  GP12 ──── Button 3 (Yes)       ──── GND
  GP13 ──── Button 4 (No)        ──── GND
```

- Internal pull-ups enabled in firmware (`Pin.PULL_UP`)
- Active LOW: pressed = GND, released = 3V3
- Software debounce: 50ms
- Layout (left hand reaching to right forearm):
  - Top row (elbow end): Dictation (index), Mode (middle)
  - Bottom row (wrist end): Yes (ring), No (pinky)

## Vibration Motor (PWM via NPN)

```
  3V3 ──── Vibration Motor (+) ──┬── Motor (-) ──── NPN Collector
                                 │
                           1N4148 Diode
                           (flyback, cathode to 3V3)
                                 │
                                 └── NPN Collector
                                     NPN Base ──── 1kΩ ──── GP15
                                     NPN Emitter ──── GND
```

- **NPN transistor**: 2N2222 or equivalent
- **1kΩ base resistor**: limits current from GPIO
- **1N4148 flyback diode**: across motor terminals, cathode to 3V3 side
- PWM on GP15 for variable intensity

## Status LED

```
  GP16 ──── 100Ω ──── LED (+) ──── LED (-) ──── GND
```

- Standard 3mm LED (green or white)
- 100Ω resistor for ~10mA at 3.3V
- PWM capable for breathing/pulsing effects

## Full Connection Summary

```
                    ┌─────────────────────────┐
                    │      Pico 2 W            │
                    │                          │
          USB-C ◄───│ USB                      │
                    │                          │
     OLED SDA  ◄───│ GP4  (I2C0 SDA)         │
     OLED SCL  ◄───│ GP5  (I2C0 SCL)         │
                    │                          │
     Button 1  ◄───│ GP10                     │
     Button 2  ◄───│ GP11                     │
     Button 3  ◄───│ GP12                     │
     Button 4  ◄───│ GP13                     │
                    │                          │
     Motor NPN ◄───│ GP15 (PWM)              │
     LED       ◄───│ GP16 (PWM)              │
                    │                          │
     TP4056 OUT ───│ VSYS                     │
     GND ──────────│ GND                      │
     3V3 OUT ◄─────│ 3V3                      │
                    └─────────────────────────┘
```

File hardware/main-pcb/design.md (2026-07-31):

# Roam Main Board — Design Spec

Custom PCB replacing the XIAO nRF52840 Sense and all hand-wired connections.
Integrates BLE+Wi-Fi module, charger, regulator, IMU, and motor driver on one board.
JST plug-in connectors for every peripheral — zero solder assembly.

## Why

P2 prototype uses 12+ hand-soldered wires between XIAO and peripherals. Fragile,
tedious, unreproducible. This board consolidates everything into a single PCB with
keyed connectors. Plug in battery, buttons, motor, LED, display, switch — done.
Path to a sellable product.

**ESP32-C6 upgrade** (from nRF52840): Adds Wi-Fi 6 as an opt-in fallback alongside
BLE 5.0. Wi-Fi disabled by default for power savings — enable via BLE command or
button combo for OTA updates, HTTP push notifications, or future features.

## Board Dimensions

- **Width**: 45mm (X)
- **Height**: 35mm (Y)
- **Thickness**: 1.6mm (standard 2-layer)
- **Mounting**: 4× M2 holes at corners (39mm × 29mm spacing, 3mm inset from edges)
- **Target fit**: alongside 502535 LiPo battery in Roam housing

## Connectors

| Ref | Type | Pins | Pitch | Connects To |
|-----|---|---|---|---|
| J1 | USB-C receptacle | 16 | — | Host (charge + program) |
| J2 | JST-SH 1.0mm | 5 | 1.0mm | Finger buttons (4 sig + GND) |
| J3 | JST-SH 1.0mm | 3 | 1.0mm | Scroll buttons (2 sig + GND) |
| J4 | JST-SH 1.0mm | 2 | 1.0mm | Motor (leads only, driver on-board) |
| J6 | JST-SH 1.0mm | 4 | 1.0mm | Display (VCC, GND, SDA, SCL) |
| J7 | JST-SH 1.0mm | 3 | 1.0mm | Power switch (off-board MSK-12C02) |
| J8 | JST-PH 2.0mm | 2 | 2.0mm | LiPo battery (industry standard) |
| J9 | 1×4 pin header | 4 | 2.54mm | UART debug (hand-solder) |

All JST-SH connectors are horizontal/right-angle SMD (SM0xB-SRSS-TB series).
J8 uses JST-PH (S2B-PH-K-S) — the standard LiPo battery connector.
J9 is a through-hole 2.54mm header for UART debug during firmware bring-up.

**Status LED (D3)** is mounted directly on the PCB (0603 SMD). Housing needs a
light pipe, window, or edge-positioned LED to be visible from outside.

### Connector Pin Assignments

**J1 — USB-C** (USB 2.0, ESP32-C6 full-speed via built-in USB Serial/JTAG):
```
A1/B1/A12/B12: GND (shield)
A4/B4/A9/B9:   VBUS (5V)
A5:             CC1 → R8 (5.1K) → GND
B5:             CC2 → R9 (5.1K) → GND
A6:             D+ → U4 (ESD) → ESP32-C6 GPIO13
A7:             D- → U4 (ESD) → ESP32-C6 GPIO12
```

**J2 — Finger Buttons** (active low, internal pull-ups):
```
Pin 1: Index   → GPIO0
Pin 2: Middle  → GPIO1
Pin 3: Ring    → GPIO2
Pin 4: Pinky   → GPIO4
Pin 5: GND
```

**J3 — Scroll Buttons** (active low, internal pull-ups):
```
Pin 1: Scroll Fwd  → GPIO5
Pin 2: Scroll Back  → GPIO14
Pin 3: GND
```

**J4 — Motor**:
```
Pin 1: Motor+  → 3V3_SYS (from on-board MOSFET drain)
Pin 2: Motor-  → GND (switched by MOSFET)
```
Note: Connector carries switched current. Motor+ goes to Q1 drain via
on-board trace, Motor- is direct GND. Max ~120mA for coin motor.

**J6 — Display** (I2C, compatible with SH1106/SSD1309 modules):
```
Pin 1: VCC  → 3V3_SYS
Pin 2: GND
Pin 3: SDA  → I2C bus (GPIO6)
Pin 4: SCL  → I2C bus (GPIO7)
```

**J7 — Power Switch** (off-board MSK-12C02 SPDT):
```
Pin 1: VBAT      → from battery/charger node
Pin 2: VBAT_SW   → switched battery, returns to LDO input
Pin 3: NC        → switch OFF position (not connected on PCB)
```
Wire: Pin 1 → switch common (center), Pin 2 → switch ON throw,
Pin 3 → switch OFF throw. Switch breaks the power path between
battery and LDO — device fully off when switch is in OFF position.

**J8 — LiPo Battery** (JST-PH 2.0mm, standard polarity):
```
Pin 1: BAT+  → VBAT node
Pin 2: BAT-  → GND
```

**J9 — UART Debug** (2.54mm, hand-solder):
```
Pin 1: 3V3   → 3V3_SYS (logic analyzer reference)
Pin 2: TX    → GPIO16 (UART0 TX)
Pin 3: RX    → GPIO17 (UART0 RX)
Pin 4: GND
```

## Schematic — Signal Path

### Power — Charging (USB → Battery)

```
USB VBUS (5V) ──┬── C9 (10uF) ── GND          ← VBUS bulk cap
                │
                ├── U4 pin 5 (VBUS)             ← ESD reference
                │
                └── U2 (MCP73831T) VDD (pin 4)
                    │
                    ├── C1 (4.7uF) ── GND       ← input bypass
                    │
                    ├── STAT (pin 1) ── D2 (LED cathode)
                    │                   D2 anode ── R2 (1K) ── VBUS
                    │
                    ├── PROG (pin 5) ── R1 (2K) ── GND
                    │                   ↑ sets charge current: 1000V/2K = 500mA
                    │
                    ├── VSS (pin 2) ── GND
                    │
                    └── VBAT (pin 3) ──┬── C2 (4.7uF) ── GND    ← output bypass
                                       │
                                       └── VBAT node ──┬── J8 pin 1 (battery+)
                                                       └── J7 pin 1 (to switch)
```

MCP73831T-2ACI/OT: 4.20V regulation, ±0.75% accuracy.
STAT is open-drain: LOW = charging, HIGH-Z = done. D2 lights during charge.
R1 = 2kΩ programs 500mA charge current (IREG = 1000/RPROG).

**Charge path is independent of the power switch** — battery charges via USB
whether the device is on or off. Normal usage: plug in USB, device runs from
battery while simultaneously charging (same as any phone or Adafruit Feather).
Switch OFF + USB plugged in: battery charges, MCU stays off.

### Power — System Rail (Battery → 3.3V)

```
VBAT node ── J7 pin 1 ──→ [off-board switch] ──→ J7 pin 2 ── VBAT_SW
                                                                 │
                                                    U3 (AP2112K-3.3) VIN (pin 1)
                                                                 │
                                                    ├── C3 (1uF) ── GND      ← input bypass
                                                    ├── EN (pin 3) ── VIN     ← always enabled
                                                    ├── GND (pin 2) ── GND
                                                    ├── BP (pin 4) ── NC
                                                    │
                                                    └── VOUT (pin 5) ── 3V3_SYS
                                                                          │
                                                         C4 (1uF) ──┤── GND    ← output bypass
                                                                     │
                                                         ┌───────────┼──────────────────────┐
                                                         │           │                      │
                                                    U1 3V3      U5 VDD/VDDIO          System loads
                                                  (ESP32-C6)  (LSM6DS3TR-C)     (I2C pull-ups,
                                                                                  display via J6,
                                                                                  motor via Q1,
                                                                                  LED via R3)
```

AP2112K-3.3: 600mA max output, 250mV dropout at full load.
LiPo range 3.0–4.2V → 3.3V out (dropout OK above ~3.55V).
EN tied to VIN — regulator active whenever switch is ON.

### Full Power Tree

```
USB 5V ──→ MCP73831T ──→ LiPo battery (charging path, always connected)

LiPo VBAT ──→ Power switch (off-board, J7) ──→ AP2112K LDO ──→ 3V3_SYS
                                                                   │
                                     ┌─────────────────────────────┤
                                     │           │           │     │
                                  ESP32-C6   LSM6DS3TR-C   R4/R5  J6 VCC
                                (BLE+WiFi+    (IMU)       (I2C)  (Display)
                                  USB)
                                     │
                              ┌──────┼──────┐
                              │      │      │
                           Motor   LED    R6/R7
                          (via Q1) (via R3) (VBAT divider)
```

Battery voltage divider on VBAT_SW (after switch):

```
VBAT_SW ── R6 (1M) ──┬── R7 (1M) ── GND
                      │
                      └── GPIO3 (ADC1_CH3, ESP32-C6)
```

Divider ratio: 0.5 → 4.2V battery reads as 2.1V (within ESP32-C6 ADC range).
Software: `voltage = adc_reading * 2 * 3.3 / 4096` (12-bit ADC, ~3.3V ref with attenuation).

### USB (Data Path)

```
J1 (USB-C) ──── D+ (A6) ──── U4 pin 3 (I/O2) ── U4 pin 4 (I/O2) ──── ESP32-C6 GPIO13
             ── D- (A7) ──── U4 pin 1 (I/O1) ── U4 pin 6 (I/O1) ──── ESP32-C6 GPIO12
             ── VBUS ─────── U4 pin 5 (VBUS)

CC1 (A5) ── R8 (5.1K) ── GND      ← identifies as USB sink/UFP
CC2 (B5) ── R9 (5.1K) ── GND
```

USBLC6-2SC6 pinout (SOT-23-6):
```
Pin 1: I/O1    ← USB D- from connector
Pin 2: GND
Pin 3: I/O2    ← USB D+ from connector
Pin 4: I/O2    → USB D+ to ESP32-C6 GPIO13
Pin 5: VBUS    ← reference voltage
Pin 6: I/O1    → USB D- to ESP32-C6 GPIO12
```

ESP32-C6 has built-in USB Serial/JTAG controller on GPIO12/13. No external
USB-to-serial chip needed. Provides serial console + JTAG debug over one cable.
No VBUS sense trace to module needed — ESP32-C6 detects USB internally.

### Wireless Module (ESP32-C6-MINI-1-N4)

Pre-certified ESP32-C6 module (FCC/CE). RISC-V single-core @ 160MHz.
BLE 5.0 + Wi-Fi 6 (802.11ax, 2.4GHz). 4MB flash, 320KB SRAM.
Internal: 40MHz crystal, antenna, RF matching, flash.
External requirements: 3V3 bypass, EN circuit, GPIO8 strapping pull-up.

```
3V3_SYS ──┬── ESP32-C6-MINI-1 3V3 pin ──┬── C5 (100nF) ── GND    ← close bypass
           │                              └── C6 (10uF) ── GND     ← bulk bypass
           │
           ├── R10 (10K) ──┬── EN pin ──── SW1 ── GND
           │                └── C10 (1uF) ── GND           ← RC delay (τ=10ms)
           │
           └── R11 (10K) ── GPIO8                          ← strapping pull-up

ESP32-C6 GPIO12 ── U4 pin 6 (protected USB D-)
ESP32-C6 GPIO13 ── U4 pin 4 (protected USB D+)
ESP32-C6 GPIO9  ────────────── SW2 ── GND                 (BOOT button)
ESP32-C6 GPIO16 ── J9 pin 2 (UART TX)
ESP32-C6 GPIO17 ── J9 pin 3 (UART RX)
```

**EN pin**: Chip enable, active HIGH. R10 (10K) pull-up + C10 (1uF) RC delay
provides clean power-on reset sequencing and noise rejection. SW1 pulls EN LOW
to reset the chip.

**GPIO8 strapping**: Must be HIGH when GPIO9 is LOW (download mode). R11 (10K)
pull-up ensures valid boot mode entry. After boot, GPIO8 is used for LED output —
the pull-up is negligible against the LED load current. At boot (before firmware
configures GPIO8 as output), the pin is floating input — 10K pull-up drives only
~0.13mA through LED, essentially invisible.

**GPIO9 (BOOT)**: Internal pull-up. HIGH = normal SPI flash boot. Hold SW2
(GPIO9 LOW) + press SW1 (EN LOW → HIGH) = enter download mode for flashing.
Same user gesture as the old DFU entry (hold BOOT + press RESET).

GPIO connections:

| ESP32-C6 GPIO | Function | Route To |
|---|---|---|
| GPIO0 | Button Index | J2 pin 1 |
| GPIO1 | Button Middle | J2 pin 2 |
| GPIO2 | Button Ring | J2 pin 3 |
| GPIO3 | Battery ADC | R6/R7 divider midpoint |
| GPIO4 | Button Pinky | J2 pin 4 |
| GPIO5 | Scroll Forward | J3 pin 1 |
| GPIO6 | I2C SDA | R5 pull-up + J6 pin 3 + U5 SDA |
| GPIO7 | I2C SCL | R4 pull-up + J6 pin 4 + U5 SCL |
| GPIO8 | LED drive | R3 (100Ω) → J5 pin 1 |
| GPIO9 | BOOT button | SW2 → GND |
| GPIO12 | USB D- | U4 → J1 (USB-C) |
| GPIO13 | USB D+ | U4 → J1 (USB-C) |
| GPIO14 | Scroll Back | J3 pin 2 |
| GPIO15 | Motor gate | Q1 gate |
| GPIO16 | UART TX | J9 pin 2 |
| GPIO17 | UART RX | J9 pin 3 |

**Strapping pin notes**: GPIO4 (MTMS) and GPIO5 (MTDI) are SDIO strapping pins —
irrelevant since we have no SDIO. Internal pull-ups ensure safe boot state.
GPIO8 has external 10K pull-up (R11). GPIO15 is JTAG source select — irrelevant
since we use USB JTAG.

**Pad assignments**: Reference the Espressif ESP32-C6-MINI-1 datasheet v1.4 or
later for physical pad positions. Verify GPIO numbers match module pin numbers
before PCB layout.

### IMU (LSM6DS3TR-C, LGA-14)

Same chip as XIAO nRF52840 Sense. On ESP32-C6, uses standard Wire library
(no TWIM1 workaround needed — no softdevice conflict).

```
3V3_SYS ──┬── U5 VDD (pin 9) ──── C7 (100nF) ── GND
           └── U5 VDDIO (pin 5) ── C8 (100nF) ── GND

U5 pin connections:
  1:  SDO/SA0 ── GND               ← I2C address = 0x6A
  2:  SDX     ── NC                 ← aux SPI (unused)
  3:  SCX     ── NC                 ← aux SPI (unused)
  4:  INT1    ── NC (or route to spare GPIO for wake-on-motion later)
  5:  VDDIO   ── 3V3_SYS + C8
  6:  GND     ── GND
  7:  GND     ── GND
  8:  GND     ── GND (also center pad)
  9:  VDD     ── 3V3_SYS + C7
  10: NC      ── GND
  11: CS      ── 3V3_SYS           ← forces I2C mode (disable SPI)
  12: SCL     ── I2C SCL bus (GPIO7)
  13: SDA     ── I2C SDA bus (GPIO6)
  14: INT2    ── NC
```

I2C address 0x6A (SA0 = GND). Same as XIAO Sense default.
CS tied to VDD to disable SPI and enable I2C.

### I2C Bus

Shared bus: ESP32-C6 (GPIO6/GPIO7) ↔ LSM6DS3TR-C (U5) ↔ Display (J6).

```
3V3_SYS ── R4 (4.7K) ──┬── SCL ── ESP32-C6 GPIO7
                        ├── U5 pin 12 (SCL)
                        └── J6 pin 4 (display SCL)

3V3_SYS ── R5 (4.7K) ──┬── SDA ── ESP32-C6 GPIO6
                        ├── U5 pin 13 (SDA)
                        └── J6 pin 3 (display SDA)
```

ESP32-C6 uses standard Wire library — no TWIM1 workaround needed. The nRF52840's
softdevice I2C conflict does not exist on ESP32-C6. GPIO6/GPIO7 map to the
LP_I2C (low-power I2C) peripheral for optimal power efficiency.

If the display module has its own I2C pull-ups, the parallel resistance
(4.7K ∥ 4.7K = 2.35K) is still safe for 100kHz I2C at 3.3V.

### Motor Driver

```
3V3_SYS ──┬──────────────── J4 pin 1 (Motor +)
           │                      │
      ┌──┤◄├──┐            J4 pin 2 (Motor -)
      │  SS14  │                  │
      │  (D1)  │                  │  Drain
      └────────┘            ┌─────┘
                            │
GPIO15 ───────────── Gate ──┤ Q1 (2N7002)
                            │
                            └── Source ── GND
```

2N7002 N-MOSFET: VGS(th) typ 1.5V, fully enhanced at 3.3V.
No gate resistor needed — gate capacitance ~50pF, slow switching OK.
SS14 flyback diode: cathode toward 3V3_SYS, protects MOSFET from
inductive kick when motor turns off.

Motor current: ~80–100mA typical, ~120mA stall.
2N7002 rated 300mA continuous — comfortable margin.

### Status LED (On-Board, Addressable RGB)

```
GPIO8 ── D3 DIN (SK6812-MINI-E)
3V3_SYS ── D3 VDD
GND ── D3 GND
D3 DOUT ── NC
```

D3 is an SK6812-MINI-E (3.2×2.8mm) addressable RGB LED mounted directly on
the PCB. Single data pin — any color selectable in firmware via NeoPixel or
FastLED library. Eliminates the external LED cable and J5 connector.

Position D3 near the board edge so light is visible through a housing window
or light pipe. Add C11 (100nF) bypass cap close to D3 VDD pin.

Current draw: ~1mA idle (data line quiescent), up to ~20mA at full white.
Run at low brightness for status indicator — typically 3–5mA.

R3 (100Ω series resistor) is no longer needed — SK6812 has built-in constant
current drivers. GPIO8 connects directly to D3 DIN.

Note: GPIO8 has R11 (10K) pull-up for boot strapping. At boot (pin floating),
pull-up provides a weak HIGH on DIN — SK6812 ignores invalid data and stays
off until firmware sends a valid NeoPixel frame.

### Buttons (External, via J2 and J3)

All buttons are simple switches to GND. ESP32-C6 internal pull-ups
enabled in firmware (INPUT_PULLUP) — no external pull-up resistors needed.

```
J2 pin 1 (Index)   ── GPIO0     ┐
J2 pin 2 (Middle)  ── GPIO1     │  Buttons switch
J2 pin 3 (Ring)    ── GPIO2     │  signal to GND
J2 pin 4 (Pinky)   ── GPIO4     │  via J2/J3 GND pin
J2 pin 5           ── GND       ┘

J3 pin 1 (Scroll Fwd)  ── GPIO5   ┐
J3 pin 2 (Scroll Back)  ── GPIO14  │
J3 pin 3                ── GND     ┘
```

### BOOT and Reset Buttons (On-Board)

```
              R10 (10K)
3V3_SYS ────────┬──── EN (ESP32-C6) ──── SW1 ── GND
                │
                └── C10 (1uF) ── GND    ← RC delay (τ=10ms)

              R11 (10K)
3V3_SYS ────────── GPIO8               ← strapping pull-up

GPIO9 (internal pull-up) ────────────── SW2 ── GND
```

SW1 = Reset. Press to reset MCU (pulls EN LOW). RC delay (R10+C10) prevents
noise from causing spurious resets.

SW2 = BOOT. Hold SW2 (GPIO9 LOW) + press SW1 to enter download mode.
GPIO8 must be HIGH during download — guaranteed by R11 pull-up.

Both switches are SMD tactile (3×6×2.5mm), low-profile for housing fit.

## GPIO Mapping (Complete)

| ESP32-C6 GPIO | Function | Direction | Connector | Notes |
|---|---|---|---|---|
| GPIO0 | Button Index | Input | J2 pin 1 | Internal pull-up |
| GPIO1 | Button Middle | Input | J2 pin 2 | Internal pull-up |
| GPIO2 | Button Ring | Input | J2 pin 3 | Internal pull-up |
| GPIO3 | Battery ADC | Input | On-board divider | ADC1_CH3, 1M+1M divider |
| GPIO4 | Button Pinky | Input | J2 pin 4 | Internal pull-up, MTMS strapping (safe) |
| GPIO5 | Scroll Forward | Input | J3 pin 1 | Internal pull-up, MTDI strapping (safe) |
| GPIO6 | I2C SDA | Bidir | J6 + U5 | 4.7K ext. pull-up, LP_I2C_SDA |
| GPIO7 | I2C SCL | Bidir | J6 + U5 | 4.7K ext. pull-up, LP_I2C_SCL |
| GPIO8 | LED data | Output | On-board D3 (SK6812) | Strapping pin — R11 (10K) pull-up required |
| GPIO9 | BOOT button | Input | On-board SW2 | Internal pull-up, LOW = download mode |
| GPIO12 | USB D- | Bidir | J1 via U4 | Dedicated USB Serial/JTAG |
| GPIO13 | USB D+ | Bidir | J1 via U4 | Dedicated USB Serial/JTAG |
| GPIO14 | Scroll Back | Input | J3 pin 2 | Internal pull-up |
| GPIO15 | Motor gate | Output | On-board Q1 | JTAG strapping (irrelevant) |
| GPIO16 | UART TX | Output | J9 pin 2 | Debug console |
| GPIO17 | UART RX | Input | J9 pin 3 | Debug console |
| EN | Chip Enable | Input | SW1 + R10 + C10 | Active HIGH, RC reset |

**Firmware impact**: Requires new Arduino core (`arduino-esp32` v3.x) and BLE
stack (NimBLE instead of Bluefruit). I2C uses standard Wire library — no TWIM1
workaround needed. Pin definitions in a new `config.h` using ESP32-C6 GPIO
numbers. FQBN: `esp32:esp32:esp32c6`.

## Power Budget

| Load | Typical | Peak | Notes |
|---|---|---|---|
| ESP32-C6 (BLE active) | 20mA | 130mA | Advertising + connected |
| ESP32-C6 (CPU active) | 12mA | 15mA | RISC-V @ 160MHz |
| ESP32-C6 (Wi-Fi TX) | 60mA | 350mA | OFF by default, opt-in only |
| LSM6DS3TR-C | 0.9mA | 0.9mA | Normal mode, accel+gyro |
| Display (SH1106) | 15mA | 20mA | Typical OLED draw |
| I2C pull-ups | 0.7mA | 0.7mA | 3.3V / 4.7K × 2 |
| Motor (coin vibration) | 80mA | 120mA | Intermittent, <500ms bursts |
| LED (status) | 0mA | 13mA | Intermittent |
| Battery divider | 0.002mA | 0.002mA | 3.3V / 2M |
| **BLE mode (no motor/LED)** | **~49mA** | **~167mA** | |
| **BLE mode (all active)** | **~129mA** | **~300mA** | |
| **Wi-Fi mode (all active)** | **~189mA** | **~520mA** | Unlikely simultaneous peak |

**AP2112K headroom**: 600mA max — BLE peak 300mA (50% of capacity), Wi-Fi peak
520mA (87%) is tight but within spec. Wi-Fi TX + motor stall simultaneously is
extremely brief and unlikely. Internal current limiting and thermal shutdown
protect the LDO gracefully.

**Battery life estimate** (1250mAh LiPo, BLE mode):
- Idle BLE + display: ~49mA → ~25 hours
- Active use (BLE + display + occasional motor): ~65mA → ~19 hours
- Wi-Fi active: ~130mA → ~9 hours (opt-in scenarios only)

**Tradeoff vs nRF52840**: ~2x higher idle current in BLE mode. The 1250mAh
battery provides adequate multi-day runtime. Wi-Fi capability is the payoff.

## PCB Layout Notes

- **2-layer board**, components on top, GND pour on both layers
- **Antenna keep-out zone**: ESP32-C6-MINI-1 antenna is at the **top edge** of
  the module (opposite the GPIO pads). NO copper (traces, pours, planes) within
  15mm of the antenna area per Espressif guidelines. Position module so antenna
  protrudes past the baseboard edge for maximum range.
- **USB-C connector** at one board edge (short side), accessible through housing
- **JST connectors** along remaining edges — J8 (battery) near charger IC,
  J6 (display) and J2/J3 (buttons) on the edge facing the housing exterior
- **MCP73831 + bypass caps** close to USB-C and J8 (short thermal/current loops)
- **AP2112K + bypass caps** close to power switch return (J7)
- **ESP32-C6-MINI-1** near center, antenna end at board edge
- **LSM6DS3TR-C** near ESP32-C6 (short I2C traces), away from motor vibration
  if possible (doesn't affect accel readings significantly)
- **Q1 (MOSFET) + D1 (Schottky)** close together, near J4
- **Bypass caps** within 3mm of their IC power pins
- **GND pour** on bottom layer — continuous, unbroken under ICs
- **Via stitching** around ESP32-C6 ground pads for solid RF ground reference
- **Trace widths**: 0.25mm (10mil) for signals, 0.5mm (20mil) for power,
  0.3mm for USB differential pair (90Ω impedance not critical at full-speed
  12Mbps, but match lengths within 2mm)

## Key Design Decisions

| # | Decision | Choice | Rationale |
|---|---|---|---|
| 1 | Wireless module | ESP32-C6-MINI-1-N4 | FCC/CE pre-certified, BLE 5.0 + Wi-Fi 6, $2.83 on LCSC |
| 2 | Charger | MCP73831T-2ACI/OT | Proven (Adafruit Feather), single-cell, programmable current, SOT-23-5 |
| 3 | LDO | AP2112K-3.3 | 600mA (vs XC6206's 200mA), handles motor + radio peaks, low dropout |
| 4 | Motor driver | 2N7002 MOSFET | Voltage-driven (no base resistor), fully enhanced at 3.3V, SMT SOT-23 |
| 5 | IMU on-board | LSM6DS3TR-C | Same as XIAO Sense — proven I2C device, no extra cable needed |
| 6 | Switch off-board | JST-SH 3-pin (J7) | Must mount in housing wall for user access, cable allows flexible placement |
| 7 | Display connector | I2C JST-SH 4-pin (J6) | Works with SH1106 module now, custom OLED carrier PCB later |
| 8 | Battery connector | JST-PH 2.0mm (J8) | Industry standard — compatible with all hobby LiPo packs |
| 9 | USB ESD | USBLC6-2SC6 | Industry standard USB2.0 protection, low capacitance (3.5pF) |
| 10 | 2-layer PCB | Yes | Sufficient complexity for ~40 components, $2/board at JLCPCB |
| 11 | Charge path bypasses switch | Yes | MCP73831 wired directly to VBUS/VBAT — charges while off |
| 12 | Wi-Fi opt-in | Software-gated | Wi-Fi disabled by default for power savings. Enable via BLE command or button combo. |

## Manufacturing

- **Fab + assembly**: JLCPCB (jlcpcb.com)
- **Layers**: 2
- **Min trace/space**: 6mil/6mil (0.15mm)
- **Min via**: 0.3mm drill, 0.6mm pad
- **Surface finish**: HASL (cheapest) or ENIG (if fine-pitch pads needed)
- **BOM**: see `bom.csv` — all parts from LCSC except J9 (hand-solder)
- **Assembly**: top-side SMT only
- **Hand-solder**: J9 (UART header, 2.54mm through-hole)
- **ESP32-C6-MINI-1-N4**: LCSC C5736265 (check availability — may be extended
  library with one-time setup fee). Alternatively source from DigiKey/Mouser
  and provide as consignment.
- **Stencil**: order with boards for paste application

## Verification Checklist

Before ordering:

- [ ] Cross-check ESP32-C6-MINI-1-N4 pad assignments against Espressif datasheet v1.4
- [ ] Verify GPIO8 has 10K pull-up (R11) to 3V3
- [ ] Verify EN pin has 10K pull-up (R10) + 1uF cap (C10) + SW1 to GND
- [ ] Verify GPIO9 connects to SW2 (BOOT button) to GND
- [ ] Verify all LCSC part numbers are in stock on JLCPCB parts library
- [ ] Confirm antenna keep-out zone matches module datasheet antenna position
- [ ] Run DRC in EasyEDA (6mil min, 0.3mm via)
- [ ] Check USB-C footprint matches C165948 (TYPE-C-31-M-12) datasheet
- [ ] Verify power budget: BLE peak 300mA < 600mA AP2112K max
- [ ] Verify Wi-Fi peak 520mA < 600mA (marginal but within spec)
- [ ] Confirm I2C address: LSM6DS3TR-C at 0x6A (SA0=GND)
- [ ] Measure board outline fits housing (45×35mm target)
- [ ] Verify UART header (J9) pin order: 3V3/TX/RX/GND
- [ ] Export BOM + CPL files from EasyEDA for JLCPCB assembly

## Design Tool

Use **EasyEDA** (easyeda.com) — free, web-based, integrates directly with
JLCPCB parts library. Import BOM part numbers, place components, route traces,
export Gerber + BOM + CPL in one click.

Workflow:
1. Create new project, set board outline to 45×35mm
2. Import each LCSC part number → auto-loads footprint + 3D model
3. Place components per layout notes above
4. Route power traces first (0.5mm), then signals (0.25mm)
5. Add GND pour on both layers
6. Run DRC, fix violations
7. Generate Gerber + BOM + CPL → upload to JLCPCB

## Firmware Migration Notes

Moving from nRF52840 (Adafruit Bluefruit) to ESP32-C6 requires a firmware rewrite:

- **BLE stack**: Bluefruit → NimBLE. Use `ESP32-NimBLE-Keyboard` library for HID.
  Consumer control reports (dictation, recents) require manual HID descriptor setup.
- **I2C**: Standard `Wire.begin(GPIO6, GPIO7)` — no TWIM1 workaround needed.
  The nRF52840 softdevice I2C conflict does not exist on ESP32-C6.
- **IMU**: Same LSM6DS3TR-C at 0x6A. Use Wire library directly instead of raw
  TWIM1 register access. Bus conditioning errata workaround not needed on ESP32.
- **Display**: Same U8g2 library, standard HW_I2C constructor. No custom byte callback.
- **Wi-Fi**: Available via `WiFi.h` in arduino-esp32 v3.x. Disabled by default.
  Potential uses: OTA firmware updates, HTTP push notifications, MQTT.
- **ADC**: 12-bit (vs nRF52840's 10-bit). Update battery voltage formula.
- **USB**: Built-in USB Serial/JTAG. Serial.begin() works over USB automatically.
- **Arduino FQBN**: `esp32:esp32:esp32c6`
- **Bond management**: NimBLE stores bonds in NVS (flash). Survives power cycles
  (unlike P2 RAM-only MAC learning). Bond removal via NVS API.

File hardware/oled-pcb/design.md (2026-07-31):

# Roam OLED Carrier PCB — Design Spec

Custom carrier board for 2.42" 128x64 SSD1309 OLED panel.
I2C interface, 4-pin plug-and-play connection to XIAO nRF52840.

## Why

Every cheap 2.42" I2C OLED module (HiLetgo, YELUFT, etc.) uses the same broken
PCB design: missing reset pull-up, questionable BS pin configuration, mystery
D1/D2 pads. Two modules tested — neither responds to I2C. Custom PCB controls
the full signal chain from FPC connector to header pin.

## Board Dimensions

- **Width**: 70mm (X)
- **Height**: 48mm (Y)
- **Thickness**: 1.6mm (standard 2-layer)
- **Mounting holes**: 4x M2, 64mm x 42mm spacing (3mm inset from edges)
- **OLED visible area**: 55mm x 29mm, centered, 7mm inset from edges

## Interface

4-pin 2.54mm header (P1): GND, VCC (3.3-5V), SCL, SDA

- **VCC input range**: 3.3V - 5.5V (XC6206 LDO regulates to 3.3V)
- **I2C address**: 0x3C (SA0 tied LOW) — change R_SA0 for 0x3D
- **I2C pull-ups**: 4.7K to VCC3.3 (on-board)

## Schematic — Signal Path

### Power

```
VCC (header) ──┬── XC6206 (U1) ──── VCC3.3 (logic, 3.3V)
               │
               └── SX1308 (U2) ──── VPP (OLED drive, ~12V)
```

### OLED Panel (24-pin FPC, J1)

```
Pin  Signal    Connection
───  ────────  ──────────────────────────────
1    NC(GND)   GND
2    VLSS      GND
3    VSS       GND
4    NC        GND
5    VDD       VCC3.3
6    BS1       VCC3.3          ← FORCES I2C MODE
7    BS2       GND             ← FORCES I2C MODE
8    CS#       GND             (always selected)
9    RES#      RESET net       (R4 pull-up + C8/D2 RC reset)
10   D/C#      GND             (SA0=0 → addr 0x3C)
11   R/W#      GND             (I2C mode: tie low)
12   E/RD#     GND             (I2C mode: tie low)
13   D0        SCL             (I2C clock)
14   D1        SDA             (I2C data)
15   D2        GND             (unused in I2C)
16   D3        GND
17   D4        GND
18   D5        GND
19   D6        GND
20   D7        GND
21   IREF      R1 (910K) → GND
22   VCOMH     C6 (100nF) → GND
23   VCC       VPP (from boost)
24   NC(GND)   GND
```

### Reset Circuit

```
VCC3.3 ── R4 (10K) ──┬── RES# (pin 9)
                      │
              C8 ─────┤
              (100nF)  │
              │        D2 (1N4148WT, cathode toward C8)
              GND      │
                       C8 node
```

Power-on sequence:
1. VCC applied → C8 discharged → RES# pulled LOW through D2/C8
2. C8 charges through R4 (τ = 10K × 100nF = 1ms)
3. RES# rises to VCC3.3 → chip exits reset
4. Power off → D2 discharges C8 rapidly → ready for next boot

### Boost Converter (SX1308)

```
VCC ── L1 (4.7uH) ── SW (U2 pin 1)
                      │
                      D1 (SS14) ── VPP
                                    │
                                    C2 (4.7uF/25V)
                                    │
                                    GND

U2 pin connections:
  1: SW    ← L1/D1 junction
  2: GND
  3: FB    ← R6/R1 divider (200K/910K → ~12V out)
  4: EN    ← R5 (10K) to VCC (always on)
  5: IN    ← VCC
  6: NC
```

### I2C

```
VCC3.3 ── R2 (4.7K) ── SCL ── P1 pin 3
VCC3.3 ── R3 (4.7K) ── SDA ── P1 pin 4
```

## PCB Layout Notes

- **2-layer board**, components on top, GND pour on bottom
- FPC connector at top edge (OLED panel folds over or extends upward)
- 4-pin header at bottom edge
- Keep boost converter (U2, L1, D1, C7) away from I2C traces
- GND pour under SSD1309 FPC area for noise shielding
- All bypass caps close to their IC pins
- Mounting holes match housing: 64mm x 42mm, M2

## Key Design Decisions

1. **BS1=VCC3.3, BS2=GND**: Forces I2C mode regardless of panel default
2. **D/C#=GND**: Sets I2C address to 0x3C (most common)
3. **CS#=GND**: Always selected (required for I2C)
4. **External boost**: SSD1309 needs external VCC unlike SSD1306
5. **Reset circuit WITH D2**: Ensures clean POR on every power cycle

## OLED Panel Sourcing

The bare 2.42" OLED panel uses a 24-pin 0.5mm FPC ribbon cable.
You can either:
- **Desolder** the panel from existing HiLetgo modules (FPC + glass)
- **Buy bare panels** from AliExpress: search "2.42 inch OLED panel 24pin"

Verify the FPC is bottom-contact (contacts face the PCB) before ordering
the connector. If top-contact, use LCSC C262292 instead.

## Manufacturing

- **Fab + assembly**: JLCPCB (jlcpcb.com)
- **Layers**: 2
- **Min trace/space**: 6mil/6mil
- **BOM**: see bom.csv (all parts from LCSC basic/preferred library)
- **Assembly**: top-side SMT only
- **Header P1**: hand-solder (through-hole)

## Design Tool

Use **EasyEDA** (easyeda.com) — free, web-based, integrates directly with
JLCPCB parts library. Import BOM part numbers, place components, route traces,
export Gerber + BOM + CPL in one click.

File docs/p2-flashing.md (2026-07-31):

# Roam P2 Flashing

Roam P2 uses a Seeed XIAO nRF52840 Sense inside a sealed case. Do not ask Nick to double-tap reset; the reset button is not accessible in the current enclosure.

## Preferred Sealed-Case Flow

Use:

```bash
make p2-flash-sealed
```

This target:

1. Compiles the firmware with build intermediates in `/tmp/roam-p2-build`.
2. Exports the DFU package into `/tmp/roam-p2-out`.
3. Uses `adafruit-nrfutil --touch 1200` against the app serial port.
4. Ignores the expected failure after the app port disappears.
5. Waits for the Seeed bootloader PID `0x0045`.
6. Uploads the generated DFU zip to the bootloader port without touching again.

The normal app PID is `0x8045`. During the successful 2026-07-30 flash, the port name stayed `/dev/cu.usbmodem2101`, but the USB product ID changed from `0x8045` to `0x0045` while in bootloader mode.

## Manual Recovery

If `make p2-flash-sealed` fails after the touch step, check the current USB state:

```bash
arduino-cli board list --format json
ioreg -p IOUSB -l -w0 | awk '/XIAO|idProduct|idVendor|USB Product Name|USB Vendor Name/ {print}' | tail -n 20
```

If the board is already at PID `0x0045`, upload directly without another touch:

```bash
~/Library/Arduino15/packages/Seeeduino/hardware/nrf52/1.1.12/tools/adafruit-nrfutil/macos/adafruit-nrfutil --verbose dfu serial \
  -pkg /tmp/roam-p2-out/p2.ino.zip \
  -p /dev/cu.usbmodem2101 \
  -b 115200 \
  --singlebank
```

If the board is at PID `0x8045`, it is running the app firmware, not the bootloader.

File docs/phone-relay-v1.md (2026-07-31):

# Roam Phone Relay v1

Goal: keep Roam on the tiny XIAO nRF52840 Sense and make the phone the long-range relay. Roam connects to Android over BLE; Android relays control events and audio to the Mac over Wi-Fi.

## Topology

```
Roam/XIAO -> BLE GATT -> Android relay -> Wi-Fi/TCP -> Mac receiver -> assistant input
```

Roam should not dual-connect to Mac and Android for this mode. Android owns the BLE connection. Mac receives everything from Android over the LAN.

Current deployment shape:

- Now: Android relay points at the work Mac receiver.
- Later: Android relay points at the Mac mini, which becomes the always-on business proxy.
- BOX-3/Warble-style hardware remains a possible room/base-station client, but it should speak to the same Mac mini receiver instead of replacing the wrist path.

## BLE Service

Use the existing custom service so old Mac text push remains compatible.

| UUID | Direction | Purpose |
|---|---|---|
| `FF00` | service | Roam text/control/audio relay service |
| `FF01` | central -> Roam | Display text push, existing behavior |
| `FF02` | Roam -> central notify | Button/action/status event packets |
| `FF03` | Roam -> central notify | Audio packets |
| `FF04` | central -> Roam | Relay control packets |

Mac-to-Roam display updates in phone-relay mode must go through Android. Do not
use direct Mac BLE while Android owns Roam. The Mac receiver sends socket frame
type `3` text payloads to Android; Android chunks those into `FF01` writes.
`FF01` is limited to 128 bytes on the firmware side, so Android uses 120-byte
UTF-8 chunks.

The useful OLED display budget is smaller than the BLE budget. Receiver
feedback splits longer responses into numbered one-screen pages and sends them
last-page-first so Roam's newest-message view lands on page `1/N`. The
scroll-back/older button then walks through `2/N`, `3/N`, etc. If a response is
too long for the configured page cap, the final page says `Ask continue for
more.` instead of pointing Nick back to the laptop.

Do not blast page frames. The 2026-07-30 live test showed skipped pages
because Roam firmware had a single incoming text slot and message haptics can
hold the main loop for about 200 ms. The Mac receiver now spaces feedback
frames by 350 ms, Android settles 300 ms after `FF01` writes, and P2 firmware
queues 16 incoming text writes.

Mac socket broadcast is not the same thing as wrist display delivery. A
closeout notification was missed during a reconnect/status window after the P2
flash. The receiver now caches recent manual notices from
`scripts/roam-relay-notify.mjs` and replays them once after a non-local Android
client reconnects or Roam sends a ready/status event within the replay window.

## Event Packets (`FF02`)

Fixed 8-byte little-endian packet:

| Byte | Field |
|---:|---|
| 0 | version, currently `1` |
| 1 | event type |
| 2 | action id, or `0` |
| 3 | profile id |
| 4-7 | `millis()` timestamp, uint32 little-endian |

Event types:

| Value | Meaning |
|---:|---|
| `1` | action fired |
| `2` | push-to-talk start |
| `3` | push-to-talk stop |
| `4` | relay status |

## Control Packets (`FF04`)

Minimum 2-byte packet:

| Byte | Field |
|---:|---|
| 0 | version, currently `1` |
| 1 | command |

Commands:

| Value | Meaning |
|---:|---|
| `1` | start audio stream |
| `2` | stop audio stream |
| `3` | ping/status request |

## Audio Packets (`FF03`)

Packet format is stream-friendly, sequence-numbered, and carries enough ADPCM state for the receiver to recover after a dropped packet:

| Byte | Field |
|---:|---|
| 0 | version, currently `1` |
| 1 | codec id |
| 2-3 | sequence, uint16 little-endian |
| 4-7 | `millis()` timestamp, uint32 little-endian |
| 8-9 | ADPCM predictor, int16 little-endian; `0` for stateless codecs |
| 10 | ADPCM step index; `0` for stateless codecs |
| 11 | flags, currently `0` |
| 12..N | audio payload |

Codec ids:

| Value | Codec |
|---:|---|
| `0` | reserved |
| `1` | PCM16 mono, 16 kHz, little-endian |
| `2` | IMA ADPCM mono, 16 kHz |

The current firmware uses IMA ADPCM at 16 kHz mono to keep BLE throughput practical. PCM remains defined for bench diagnostics.

## Android Relay

Android app requirements:

- Use `CompanionDeviceManager` association for Roam.
- Maintain the BLE connection from a foreground service with `connectedDevice` type.
- Subscribe to `FF02` and `FF03`; write display/status/control to `FF01`/`FF04`.
- Relay to Mac with a persistent TCP socket.
- Show a persistent notification while active so Android does not silently stop the relay.
- Bench ADB starts need a visible activity on current Android builds; a background broadcast can be denied from starting the foreground service while the phone is locked/dreaming.
- If Android discovers `FF00` but audio is absent, check for `FF03` in the discovered GATT table. A stale 2026-07-30 firmware exposed `FF01`, `FF02`, and `FF04`, but not `FF03`; reflashing with current P2 firmware fixed that live.
- Live 2026-07-30 verification: Android subscribed `FF02` and `FF03`, relayed multiple PTT sessions over Wi-Fi to the Mac receiver, and the WAV capture grew from real Roam audio frames.

## Mac Receiver

Mac receiver requirements:

- Listen on a LAN TCP socket.
- Accept JSON event frames and binary audio frames from Android.
- Log packet loss from audio sequence numbers. Sequence tracking resets on each PTT start event because firmware starts each audio session at sequence `0`.
- Optionally write decoded 16 kHz mono PCM as a WAV capture.
- Keep the WAV header current while running so `roam-relay-latest.wav` remains inspectable without stopping the daemon.
- Transcribe PTT sessions with local `mlx_whisper` and inject the transcript into the active assistant workflow.
- For interactive/tmux use, start the receiver in a durable tmux session with `scripts/start-roam-relay-tmux.sh 8765`. It defaults to `ROAM_RELAY_INJECT_MODE=tmux-submit` and `ROAM_TMUX_TARGET=0:0`; override `ROAM_TMUX_TARGET` when the assistant lives in another tmux session/window.
- `tmux-submit` mode auto-submits after STT injection. The wrist status sequence is `Listening` -> `Transcribing` -> `Sent`. When `Sent` appears, the message has already been submitted.
- `tmux` mode drafts but does not submit. The wrist status sequence is `Listening` -> `Transcribing` -> `Ready`; after `Ready`, press Middle short/action `10` to submit.
- Manual agent/process updates can be pushed without taking BLE away from Android using `scripts/roam-relay-notify.mjs "message"`.
- Long manual updates are paged by the Mac receiver before broadcast. The
  receiver currently uses about 58 display characters per page and up to 8
  pages, with a 350 ms gap between downstream frames.
- For always-on launchd use on a Mac, install with `scripts/install-roam-relay-launchd.sh`. GUI paste/submit modes use AppleScript and may need macOS Accessibility approval; tmux modes do not need AppleScript.
- LaunchAgent logs are `~/Library/Logs/Roam/relay.out.log` and `~/Library/Logs/Roam/relay.err.log`; its rolling WAV capture is `~/Library/Logs/Roam/roam-relay-latest.wav`.
- Per-session WAVs are written to `~/Library/Logs/Roam/sessions/`; transcripts and injection audit are in `~/Library/Logs/Roam/transcripts.jsonl`.

Current phone-relay button command mapping:

| Roam action | Button gesture | Mac receiver behavior |
|---:|---|---|
| `2` | Index short | Toggle PTT audio; receiver transcribes on stop and injects with the configured mode |
| `3` | Index long | tmux next pane, using native `tmux select-pane` when available |
| `4` | Pinky short | Shift+Tab / cycle mode |
| `6` | Middle long | `y` then Enter |
| `7` | Middle double | Tab then Enter |
| `8` | Ring short | Escape |
| `9` | Ring long | Ctrl+C |
| `10` | Middle short | Enter |

Receiver behavior for local-only display actions:

- Actions `13`-`17` are local to Roam display/control and are ignored by the Mac command dispatcher.
- This matters for scroll buttons: if the receiver pushes feedback for action `15`/`16`, the new feedback message resets the OLED to newest and makes scrolling appear broken.

Live 2026-07-30 verification:

- Roam -> Android -> Mac PTT produced correct transcription and `tmux-submit` injection for "Are you down with OPP?"
- Roam action `10` arrived over Android -> Wi-Fi and dispatched as tmux Enter.
- Roam action `3` arrived over Android -> Wi-Fi and dispatched through the tmux backend; Nick confirmed the pane switch worked visibly.
- Paged reply broadcast was verified with a live receiver capture: a long test
  message emitted pages `6/6` through `1/6` in socket order, leaving `1/6` as
  the current OLED page and older/down scroll available for the rest.
- Follow-up skipped-page test reproduced missing pages on the wrist when frames
  were sent too quickly. After adding receiver pacing, a seven-page capture
  emitted every page `7/7` through `1/7` at about 350 ms intervals. Nick then
  confirmed the paced multi-page wrist message was coherent and readable, with
  every page visible page-by-page. A longer follow-up dictated from Roam also
  relayed and submitted cleanly, confirming longer inbound voice messages work
  through the current audio/STT/tmux path.
- Android GATT pacing APK was installed with `adb install -r`, relaunched
  against `192.168.86.63:8765`, and reconnected to Roam. P2 queued-text
  firmware was flashed with `make p2-flash-sealed`; Roam rebooted as normal PID
  `0x8045`, sent a fresh status event, and Nick confirmed the post-flash page
  test was good.
- Follow-up notification test: Nick missed the final closeout message around a
  reconnect/status event. A short ping delivered successfully, then the receiver
  replay guard was added and the durable receiver was restarted. Nick confirmed
  the fresh post-restart notification arrived.
- Good PTT sessions may still show occasional one-frame BLE audio gaps. A short range/case-placement issue produced a poor 1.13s transcript; the stronger 2.96s test transcribed correctly.

## Hardware Notes

- The XIAO Sense onboard PDM mic must have an acoustic opening. If the case muffles it, move to a small offboard PDM/I2S MEMS mic near a sound port.
- This path prioritizes a slimmer wearable. ESP32-S3 stays useful as a bench fallback for direct Wi-Fi audio, not as the preferred wrist build.

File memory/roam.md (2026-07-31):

# Roam Memory

## P2 Flashing In Sealed Case

- Current Roam P2 is sealed; Nick can power-cycle it but cannot double-tap the XIAO reset button.
- Do not ask Nick to be physically on the reset button. Use the software DFU workaround.
- Normal app USB PID: `0x8045`. Bootloader USB PID: `0x0045`.
- Working sequence verified 2026-07-30:
  1. Build P2 firmware.
  2. Run `adafruit-nrfutil ... --touch 1200` against the app port.
  3. That command may fail because the app port disappears; this is expected.
  4. Wait for the Seeed bootloader PID `0x0045`.
  5. Upload the same DFU zip to the bootloader port without another touch.
- Repo command: `make p2-flash-sealed`.

See [docs/p2-flashing.md](../docs/p2-flashing.md).

## Android Phone Relay

- Android owns the BLE connection in relay mode; do not use Mac `tools/roam-msg` while testing the phone relay because it can take the Roam BLE connection.
- Roam will not advertise while connected to the Mac. Free it first with the on-device BLE switch or by disconnecting/forgetting `Roam2` on the Mac.
- 2026-07-30 live test: Android app connected to Roam and the Mac receiver logged relay events from the phone (`192.168.86.23` -> `192.168.86.63:8765`).
- 2026-07-30 audio fix: stale firmware exposed `FF01`, `FF02`, and `FF04` under `FF00`, but not `FF03`. Current firmware exposes/subscribes `FF03`, drains XIAO PDM audio through an interrupt-fed ring buffer, sends 232-byte ADPCM payloads, and was flashed successfully with `make p2-flash-sealed`.
- 2026-07-30 live audio verification: two Roam PTT sessions relayed sustained audio to the Mac receiver through Android; examples reached seq `74` and seq `99`. Preserved playable capture: `~/Library/Logs/Roam/roam-relay-live-20260730-125233.wav` (6.09s, 16 kHz mono PCM). Current `roam-relay-latest.wav` starts fresh after receiver restart.
- Android may deny foreground-service starts from a background broadcast while locked. For ADB bench starts, wake/dismiss keyguard and launch `MainActivity` with `host`, `port`, and `autoStart` extras.
- 2026-07-30 durable dictation path: run `scripts/start-roam-relay-tmux.sh 8765`. It starts a `roam-relay` tmux session on the Mac, listens on `*:8765`, transcribes PTT with `/opt/homebrew/bin/mlx_whisper`, and injects with `ROAM_RELAY_INJECT_MODE=tmux-submit`.
- Default tmux target is `ROAM_TMUX_TARGET=0:0`. Override it if the active assistant is in a different tmux session/window. This tmux path avoids macOS Accessibility/TCC problems from AppleScript keystroke injection.
- 2026-07-30 end-to-end verification: Roam PTT -> Android -> Mac receiver -> STT -> tmux-submit produced the user message "Are you down with OPP?" and logged `injected=true` in `~/Library/Logs/Roam/transcripts.jsonl`.
- Phone-relay command proxy preserves old button controls over Android -> Wi-Fi -> Mac: Index long/action `3` does tmux next pane; Middle short/action `10` sends Enter; Middle long/action `6` sends `y` + Enter; Middle double/action `7` sends Tab + Enter; Ring short/action `8` sends Escape; Ring long/action `9` sends Ctrl+C; Pinky short/action `4` sends Shift+Tab.
- Nick confirmed the long-press pane switch worked visibly through the relay. Occasional one-frame BLE audio gaps remain visible in logs; short/weak captures can transcribe poorly, but the stronger live PTT test transcribed correctly.
- 2026-07-30 feedback/status direction: Mac receiver sends socket frame type `3` text back to Android; Android chunks messages into `FF01` writes for the Roam display. Do not use direct Mac BLE for updates while Android owns Roam.
- User-visible status semantics: `Listening` means audio capture started; `Transcribing` means STT is running; `Sent` means `tmux-submit` injected and submitted the message; `Ready` means draft-only `tmux` mode injected text and Nick should press Middle short/action `10` to submit.
- Manual updates should use `scripts/roam-relay-notify.mjs "message"`; it connects to the Mac receiver and broadcasts a frame type `3` update to the connected Android relay.
- Later 2026-07-30 live status update: Pixel was reattached over ADB, updated Android APK installed successfully, relay app restarted against `192.168.86.63:8765`, Android reconnected to Roam, and `scripts/roam-relay-notify.mjs "Display test: Sent means submitted"` produced a BLE `Characteristic write status=0` after GATT was ready.
- 2026-07-30 scroll/readability fix: useful OLED response budget is smaller than the 128-byte `FF01` BLE limit, so Mac receiver splits long wrist feedback into numbered one-screen pages and sends them last-page-first; Roam lands on `1/N`, then older/down scroll moves through `2/N`, `3/N`, etc. If content exceeds the page cap, final page says `Ask continue for more.` Receiver also ignores local display actions `13`-`17` so scroll actions `15`/`16` do not generate new feedback messages that reset the display to newest and make scrolling appear broken. Skipped pages were later traced to burst delivery overwriting the firmware's single incoming text slot while haptics held the main loop. Live receiver now spaces feedback frames by 350 ms; timestamped capture emitted all pages `7/7` through `1/7` at ~350 ms intervals, and Nick confirmed the paced multi-page wrist message was coherent/readable page-by-page. A longer follow-up dictated from Roam also relayed and submitted cleanly. Android APK with 300 ms GATT text-write settling was installed/relaunched, and P2 firmware with a 16-entry incoming text queue was flashed with `make p2-flash-sealed`; Roam rebooted, emitted a fresh status event, and Nick confirmed the post-flash page test was good.
- 2026-07-30 notification reliability follow-up: Nick did not receive the final closeout notification even though the receiver logged the local relay text. Logs showed a Roam status/ready event soon after the closeout, so the likely failure was a reconnect/status window between Mac socket send and wrist display consumption. A short `PING DISPLAY` arrived and Nick said "Copy, got it." Receiver now caches recent manual notices from loopback `roam-relay-notify` clients and replays them once on Android reconnect or Roam ready/status within 120s. Restarted durable receiver with replay guard; Nick confirmed the fresh post-restart notification arrived ("Got it").
- 2026-07-30 power-cycle follow-up: if Roam is powered off/on and the display stays on the BLE connection screen, the likely failure is Android holding a stale `BluetoothGatt` and refusing to scan because `gatt != null`. Android relay now has a 15s status poll and 45s stale-link reset that closes/refreshes GATT and resumes scanning. P2 firmware also has a 1s advertising watchdog while disconnected.
- 2026-07-31 Roam P2 reconnect/battery rollout: flashed P2 with `make p2-flash-sealed` after Roam enumerated as `/dev/cu.usbmodem2101`; upload succeeded with `Device programmed.` Post-flash serial showed firmware alive, brief Android BLE connect/disconnect, and battery diagnostic `raw=1576 adc=1.385V voltage=4.10V pct=90%` while plugged in. Treat the "half charged" report as stale/settling UI unless future logs show low calculated voltage. Android stale-GATT APK was built but not installed yet because no ADB device was attached and `adb connect 192.168.86.23:5555` was refused.
- 2026-07-31 Roam Android reconnect APK rollout: Pixel 10 Pro XL attached by USB. Installed rebuilt `android-relay/app/build/outputs/apk/debug/app-debug.apk`, granted Bluetooth scan/connect + notifications, added `io.roam.relay` to device-idle whitelist, and relaunched `MainActivity` against `192.168.86.63:8765`. Mac receiver logged a fresh phone socket client. Android logs showed the foreground service scanning, but no live `Roam2` advertisement during the watch window. Added source fallback to match bonded Roam addresses and try direct bonded connect, then rebuilt/reinstalled; fallback did not fire because Android currently lists `Roam2` in historical "Other devices" cache, not normal bonded devices. Mac Bluetooth also showed `Roam2` as not connected. Remaining validation requires Roam powered on/advertising near the Pixel.
- 2026-07-31 corrected Wi-Fi validation: Pixel must be on the same LAN as the Mac relay. Failure case was Pixel on the `BluSunWifi7`/`192.168.68.x` side while Mac relay was `192.168.86.63`; TCP to `192.168.86.63:8765` timed out even though BLE to Roam worked. After switching Pixel to the `192.168.86.x` Wi-Fi, rebuilt/reinstalled the Android relay with single-flight BLE connect guards, relaunched against `192.168.86.63:8765`, and verified: one phone socket client from `192.168.86.23`, one `Roam2` BLE connection, `Roam relay service ready`, status events reached the Mac, and `scripts/roam-relay-notify.mjs` split/sent a two-page wrist display message with Android `Characteristic write status=0`. The Android guard prevents duplicate scan callbacks from opening multiple simultaneous GATT sessions before `stopScan()` lands.
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

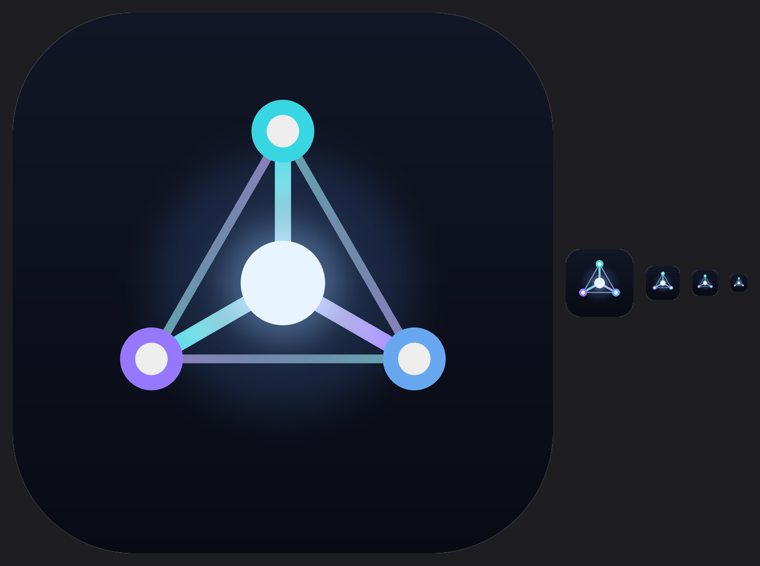
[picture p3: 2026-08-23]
roam-touch/hub/images/b69c221f0cfe5fe65ca30eb29e12abb00c9a91f1535b6e74bc48e6cab31fa80d.png

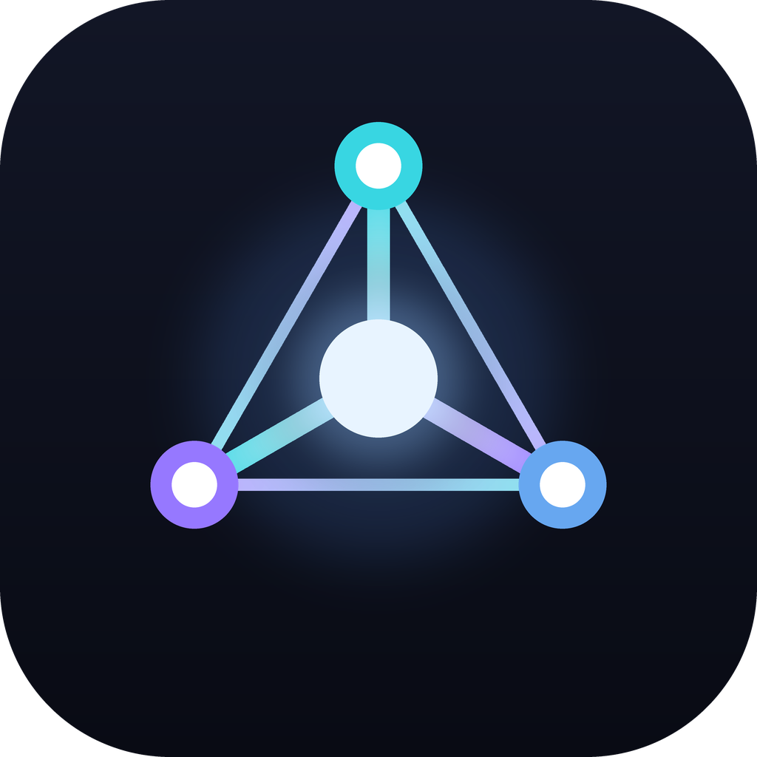
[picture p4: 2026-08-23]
roam-touch/hub/images/608961d560e622841f4d5b67dfc24d2d66cf46864601acc5cdafe4e3514641c8.png

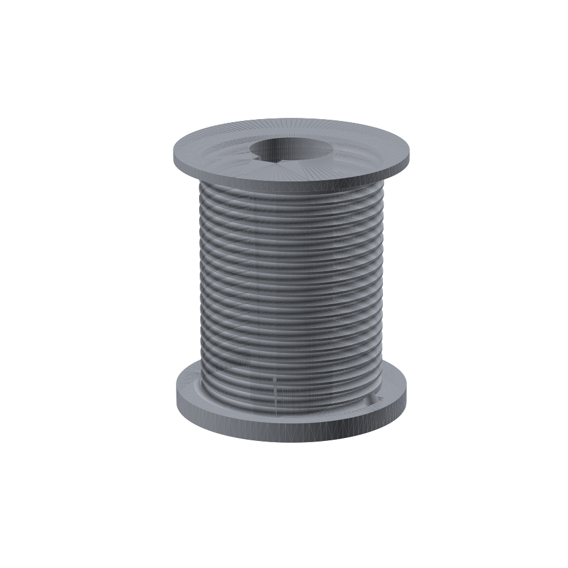
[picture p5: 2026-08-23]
roam-touch/hub/images/e142857cfbbdda9024b3573fdf0ff36276b8d9f7f9c34fd8e3a7938c39e9a5b7.png

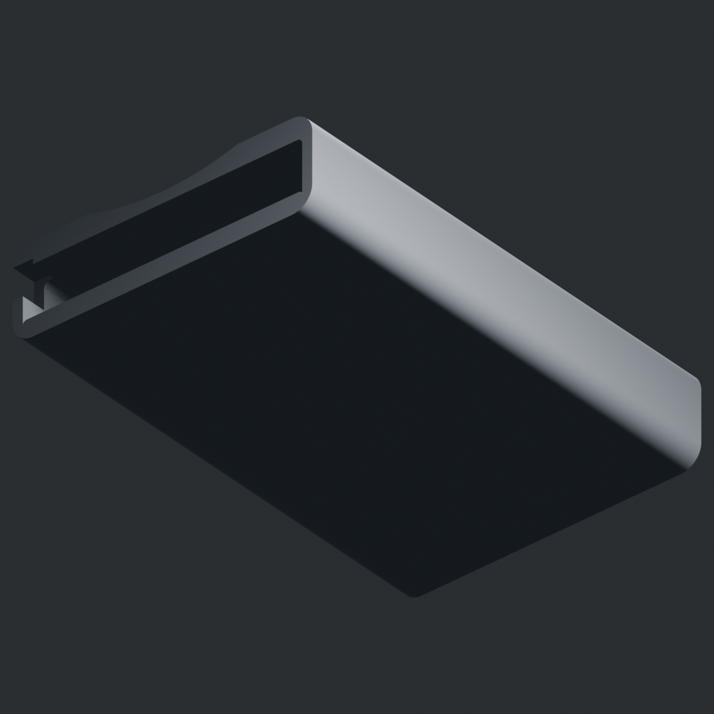
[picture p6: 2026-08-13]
roam-touch/cad/out/view_pack_saddle.png

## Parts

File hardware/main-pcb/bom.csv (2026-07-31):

Ref | Value | Package | LCSC | Description | Qty
U1 | ESP32-C6-MINI-1-N4 | SMD Module | C5736265 | Pre-certified ESP32-C6 BLE+WiFi module (Espressif) | 1
U2 | MCP73831T-2ACI/OT | SOT-23-5 | C424093 | 500mA single-cell LiPo charger 4.2V (Microchip) | 1
U3 | AP2112K-3.3TRG1 | SOT-23-5 | C51118 | 600mA 3.3V LDO regulator (Diodes Inc) | 1
U4 | USBLC6-2SC6 | SOT-23-6 | C7519 | Dual-line USB ESD protection (ST) | 1
U5 | LSM6DS3TR-C | LGA-14 | C967633 | 6-axis IMU accel+gyro I2C 0x6A (ST) | 1
J1 | TYPE-C-31-M-12 | USB-C 16P | C165948 | USB-C receptacle mid-mount (HRO) | 1
J2 | SM05B-SRSS-TB | JST-SH 5P | C136657 | Finger buttons connector (4 sig + GND) | 1
J3 | SM03B-SRSS-TB | JST-SH 3P | C160403 | Scroll buttons connector (2 sig + GND) | 1
J4 | SM02B-SRSS-TB | JST-SH 2P | C160402 | Motor connector | 1
D3 | SK6812-MINI-E | 3228 | C5149201 | Addressable RGB LED (on-board status) | 1
C11 | 100nF | 0402 | C14663 | D3 (SK6812) VDD bypass | 1
J6 | SM04B-SRSS-TB | JST-SH 4P | C160404 | Display I2C connector (VCC/GND/SDA/SCL) | 1
J7 | SM03B-SRSS-TB | JST-SH 3P | C160403 | Power switch connector (VBAT/VBAT_SW/NC) | 1
J8 | S2B-PH-K-S | JST-PH 2P | C131337 | LiPo battery connector (standard polarity) | 1
J9 | 1x4 2.54mm | Pin Header | — | UART debug header (hand-solder) | 1
Q1 | 2N7002 | SOT-23 | C8545 | N-channel MOSFET motor driver 300mA | 1
D1 | SS14 | SMA | C2480 | 1A 40V Schottky flyback diode | 1
D2 | Red LED | 0603 | C2286 | Charge status indicator | 1
SW1 | Tactile 3x6x2.5mm | SMD | C318884 | Reset button (EN to GND) | 1
SW2 | Tactile 3x6x2.5mm | SMD | C318884 | BOOT button (GPIO9 to GND) | 1
R1 | 2K | 0402 | C4109 | MCP73831 PROG (sets 500mA charge current) | 1
R2 | 1K | 0402 | C11702 | Charge LED current limit | 1
R4 | 4.7K | 0402 | C25900 | I2C SCL pull-up to 3V3 | 1
R5 | 4.7K | 0402 | C25900 | I2C SDA pull-up to 3V3 | 1
R6 | 1M | 0402 | C25585 | Battery voltage divider (high side) | 1
R7 | 1M | 0402 | C25585 | Battery voltage divider (low side) | 1
R8 | 5.1K | 0402 | C25905 | USB CC1 pull-down (UFP identification) | 1
R9 | 5.1K | 0402 | C25905 | USB CC2 pull-down (UFP identification) | 1
R10 | 10K | 0402 | C25744 | EN pin pull-up to 3V3 (reset circuit) | 1
R11 | 10K | 0402 | C25744 | GPIO8 strapping pull-up to 3V3 | 1
C1 | 4.7uF | 0805 | C1779 | MCP73831 VDD input bypass | 1
C2 | 4.7uF | 0805 | C1779 | MCP73831 VBAT output bypass | 1
C3 | 1uF | 0402 | C52923 | AP2112K VIN input bypass | 1
C4 | 1uF | 0402 | C52923 | AP2112K VOUT output bypass | 1
C5 | 100nF | 0402 | C14663 | ESP32-C6 VDD close bypass | 1
C6 | 10uF | 0805 | C15850 | ESP32-C6 VDD bulk bypass | 1
C7 | 100nF | 0402 | C14663 | LSM6DS3TR-C VDD bypass | 1
C8 | 100nF | 0402 | C14663 | LSM6DS3TR-C VDDIO bypass | 1
C9 | 10uF | 0805 | C15850 | USB VBUS bulk capacitor | 1
C10 | 1uF | 0402 | C52923 | EN pin RC delay capacitor | 1

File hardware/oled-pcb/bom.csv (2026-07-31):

Ref | Value | Package | LCSC | Description | Qty
U1 | XC6206P332MR-G | SOT-23-3 | C5446 | 3.3V 200mA LDO regulator | 1
U2 | SX1308 | SOT-23-6 | C78162 | 1.2MHz 2A boost converter | 1
D1 | SS14 | SMA | C2480 | 1A 40V Schottky diode (boost) | 1
D2 | 1N4148WT | SOD-523 | C83482 | Fast switching diode (reset discharge) | 1
J1 | FPC-24P | 0.5mm flip-lock | C262669 | 24-pin 0.5mm bottom-contact FPC connector | 1
P1 | Header-4P | 2.54mm | C124413 | 1x4 2.54mm straight male header | 1
R1 | 910K | 0402 | C25762 | Boost feedback (IREF) | 1
R2 | 4.7K | 0402 | C25900 | I2C pull-up (SCL) | 1
R3 | 4.7K | 0402 | C25900 | I2C pull-up (SDA) | 1
R4 | 10K | 0402 | C25744 | Reset pull-up to VCC3.3 | 1
R5 | 10K | 0402 | C25744 | Boost EN pull-up | 1
R6 | 200K | 0402 | C25789 | Boost feedback divider | 1
C1 | 100nF | 0402 | C14663 | LDO output bypass | 1
C2 | 4.7uF/25V | 0805 | C1779 | OLED VCC filter | 1
C3 | 4.7uF/25V | 0805 | C1779 | OLED VDD filter | 1
C4 | 100nF | 0402 | C14663 | SSD1309 VDD bypass | 1
C5 | 4.7uF/25V | 0805 | C1779 | LDO input | 1
C6 | 100nF | 0402 | C14663 | VCOMH filter | 1
C7 | 10uF/25V | 0805 | C15850 | Boost input | 1
C8 | 100nF | 0402 | C14663 | Reset RC delay | 1
L1 | 4.7uH | 0805/1210 | C76622 | Boost inductor (>2A sat) | 1

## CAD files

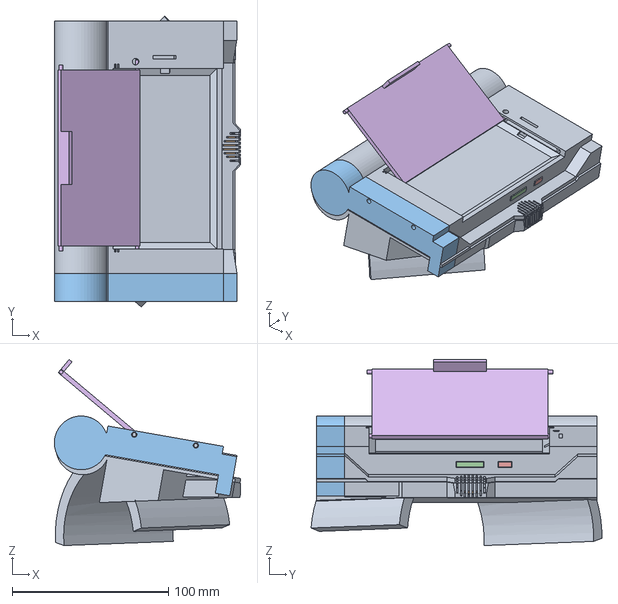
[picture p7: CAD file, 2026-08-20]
roam-touch/cad/out/roam_assembly.step
119.2 x 186.2 x 119.1 mm

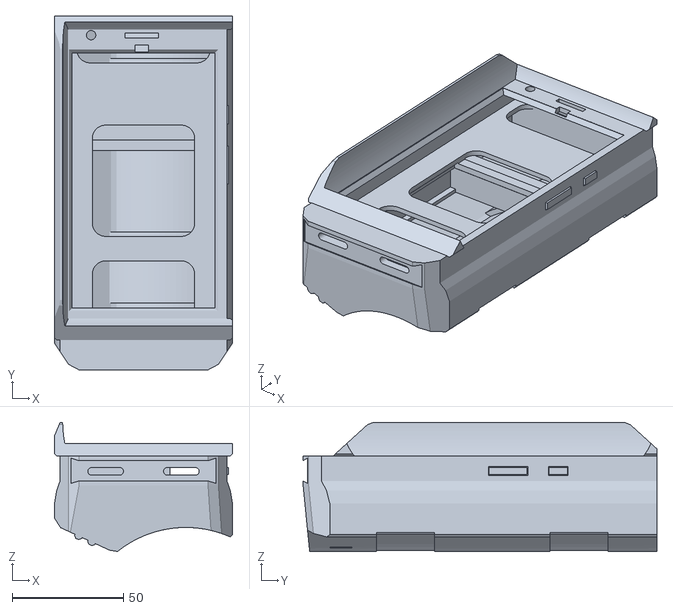
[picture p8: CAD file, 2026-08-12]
roam-touch/cad/out/assembly.stl
80.0 x 159.0 x 58.0

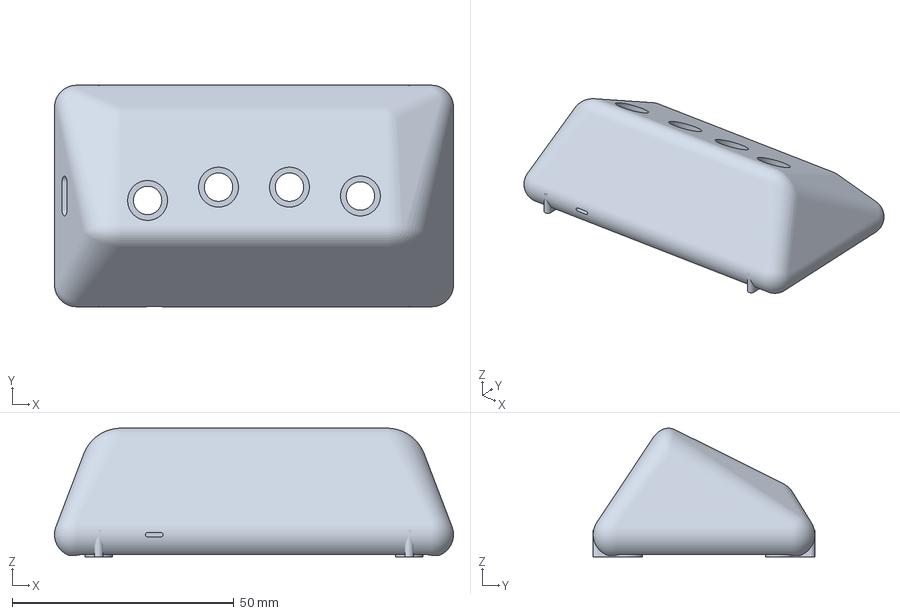
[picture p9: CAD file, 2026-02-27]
housing/roam_dome.3mf
90.0 x 50.0 x 29.0 mm

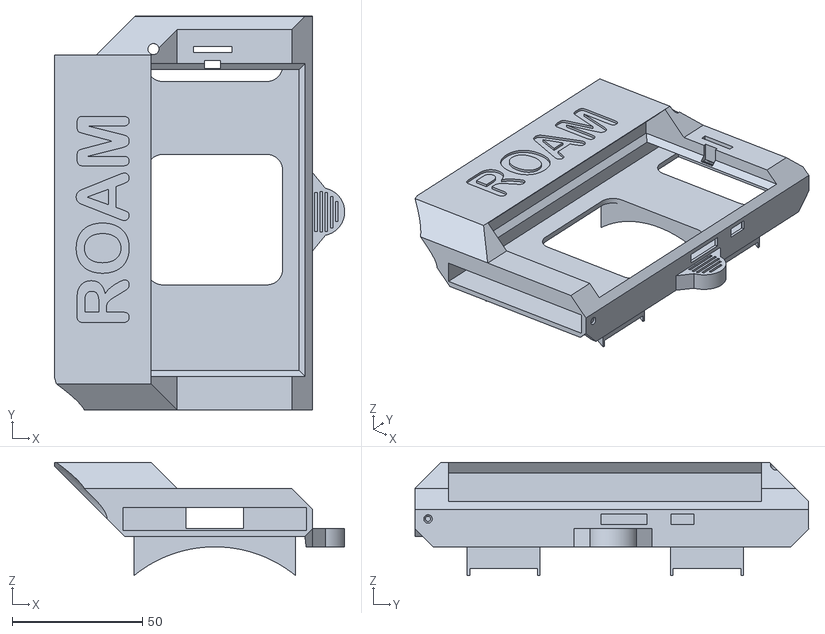
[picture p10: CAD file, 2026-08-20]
roam-touch/cad/out/RoamTouchConcept.stl
111.4 x 151.1 x 43.5

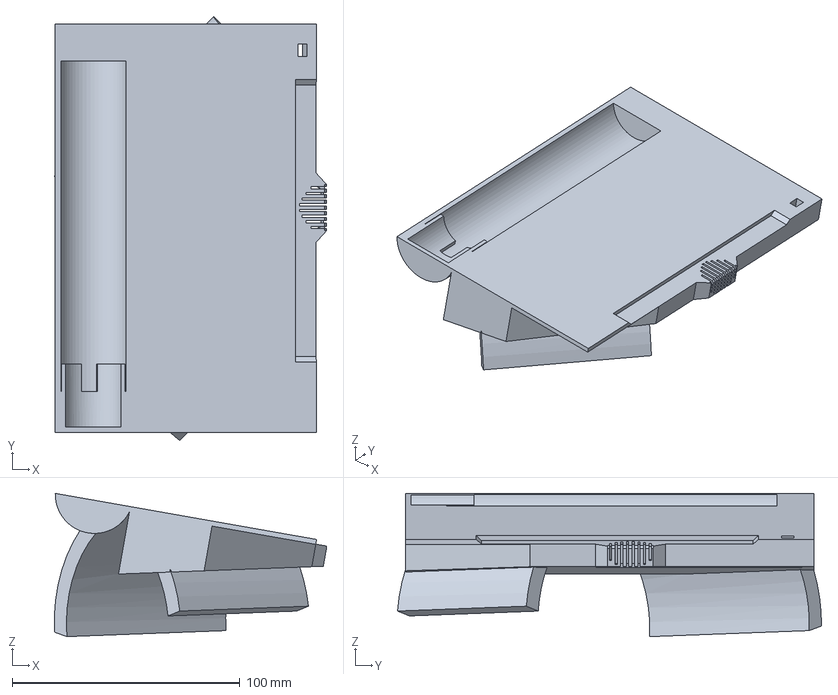
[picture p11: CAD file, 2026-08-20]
roam-touch/cad/ref/armband.step
119.6 x 186.2 x 62.9 mm

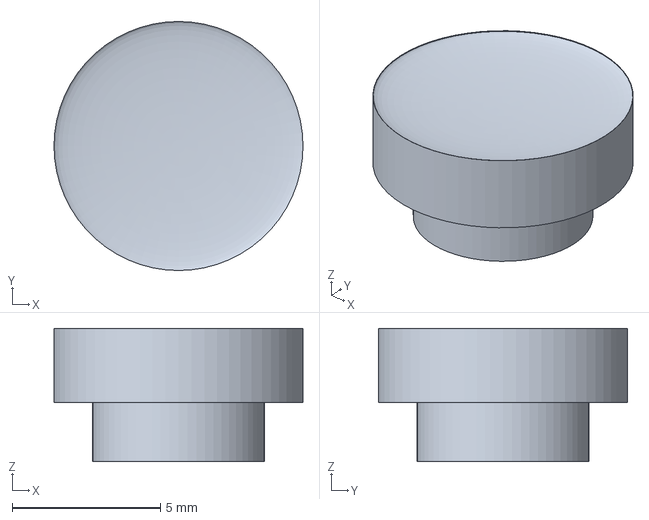
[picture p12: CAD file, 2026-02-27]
housing/roam_button_cap.3mf
8.40 x 8.40 x 4.50 mm

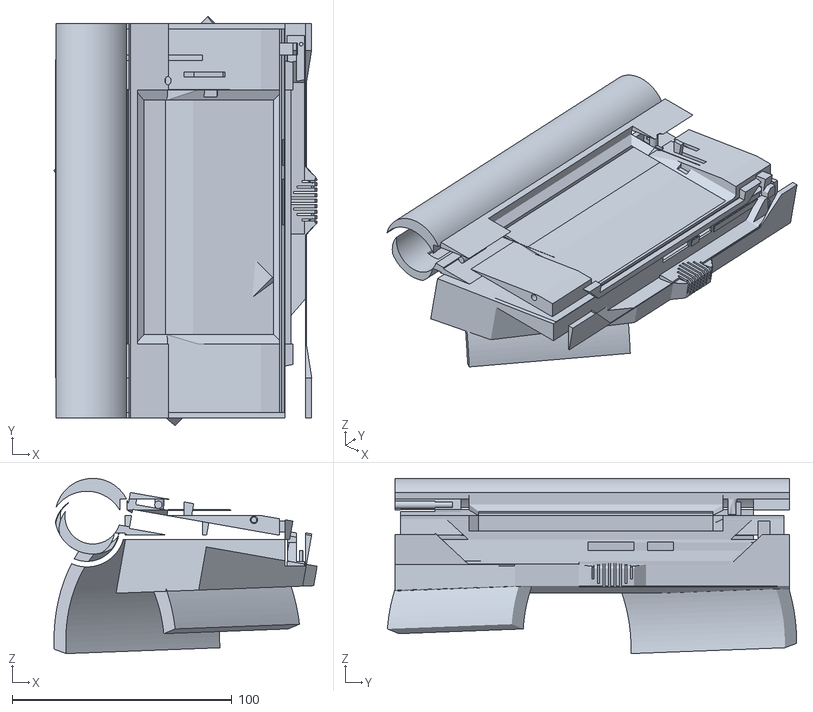
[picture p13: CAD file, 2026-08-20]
roam-touch/cad/out/armband.stl
119.7 x 186.2 x 79.7

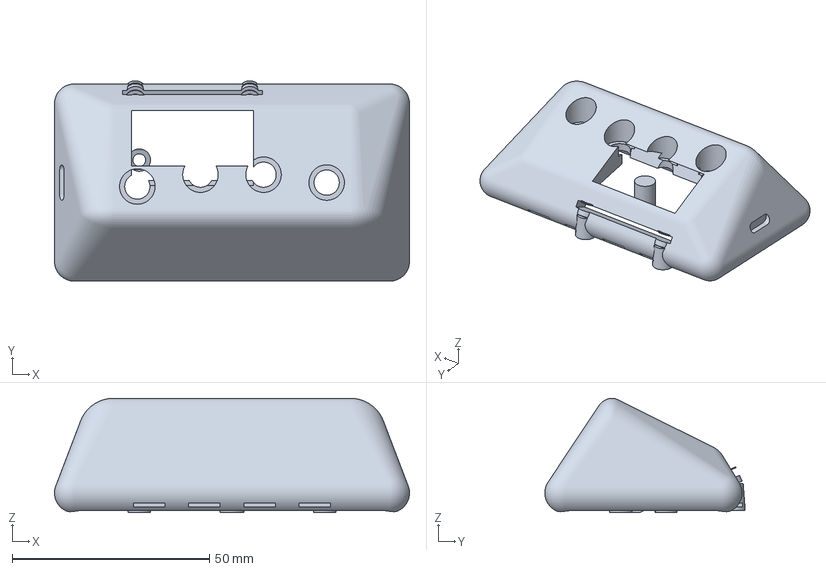
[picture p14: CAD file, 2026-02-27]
housing/roam_case.3mf
90.0 x 50.8 x 29.0 mm

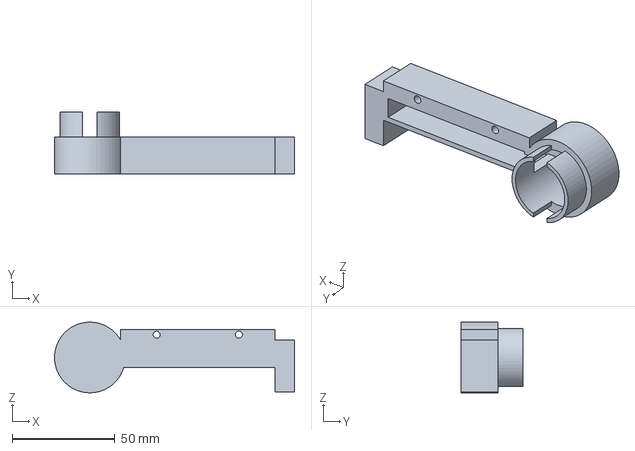
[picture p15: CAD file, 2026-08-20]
roam-touch/cad/out/roam_cap.step
116.7 x 30.0 x 34.4 mm

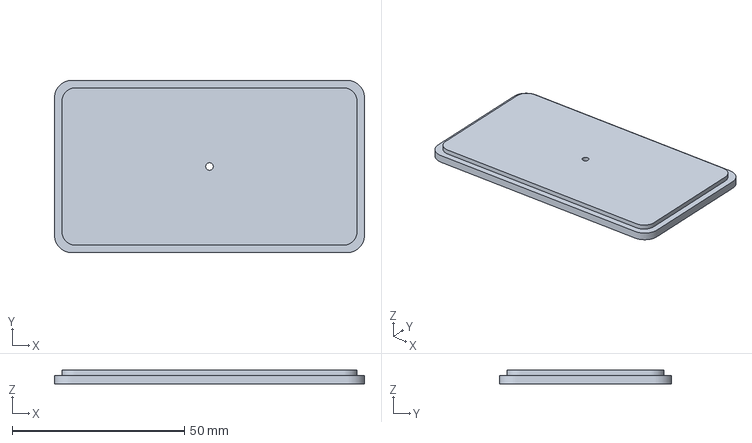
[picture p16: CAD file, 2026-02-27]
housing/roam_lid.3mf
90.0 x 50.0 x 3.99 mm

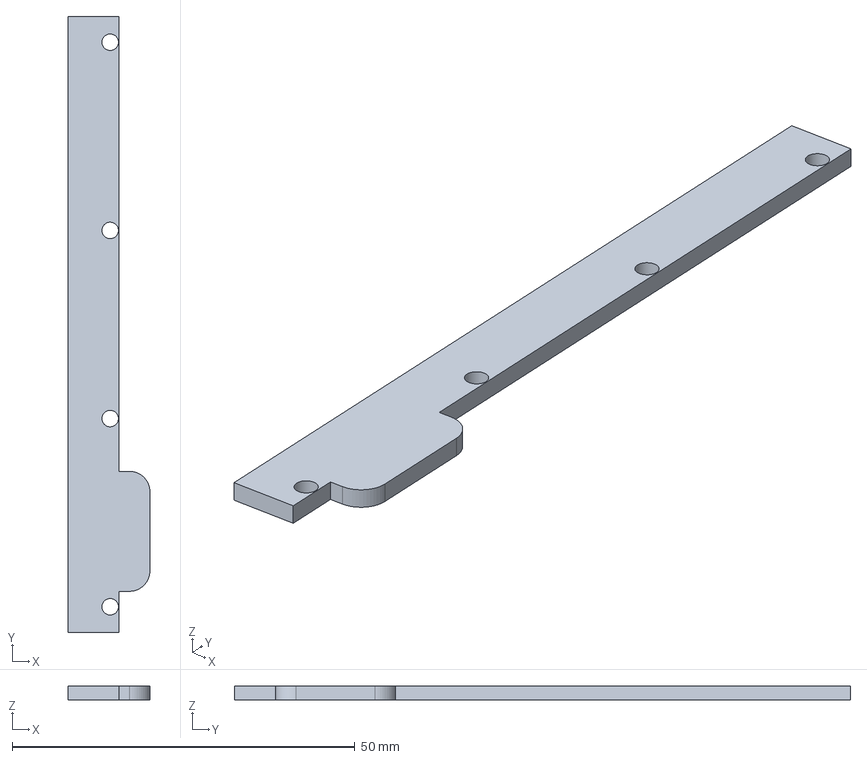
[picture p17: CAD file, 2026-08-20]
roam-touch/cad/out/roam_plate.step
11.9 x 89.8 x 2.00 mm

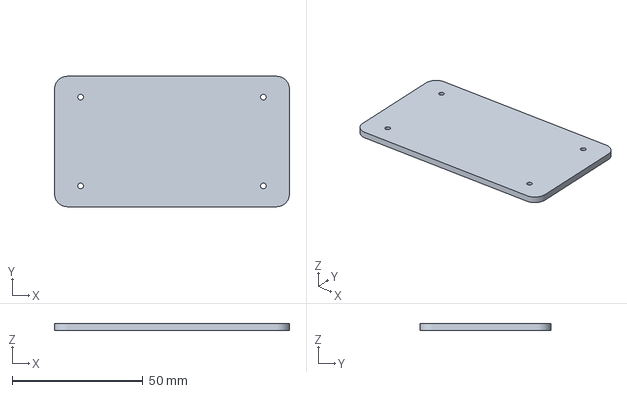
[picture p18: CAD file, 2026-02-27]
housing/roam_base.3mf
90.0 x 50.0 x 2.50 mm

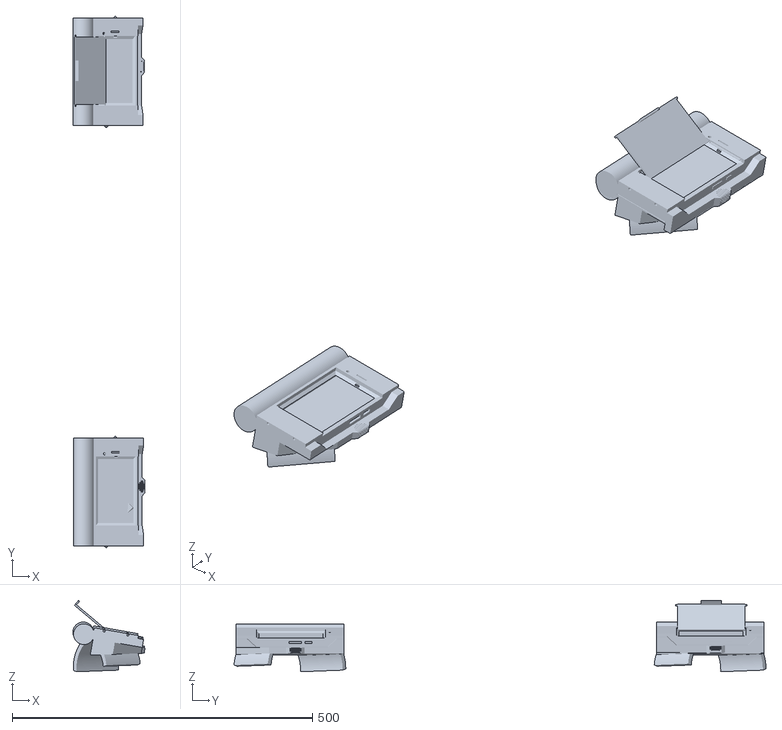
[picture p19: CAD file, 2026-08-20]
roam-touch/cad/out/latestclean.stl
120.2 x 886.2 x 119.1

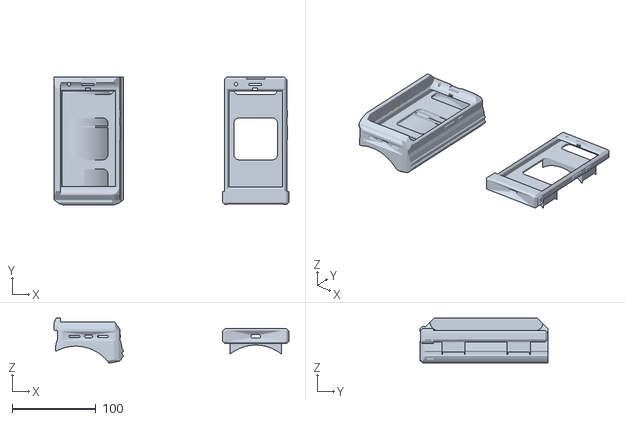
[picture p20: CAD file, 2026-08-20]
roam-touch/cad/out/RoamTouchHighGuardDemo.stl
281.4 x 153.0 x 53.8

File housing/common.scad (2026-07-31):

// common.scad — Shared parametric dimensions for Roam wrist-mount housing
// All dimensions in millimeters
//
// ORIENTATION (all files):
//   X+  = toward elbow
//   X-  = toward wrist (USB-C end)
//   Y+  = outer (away from body, button/dome-peak side)
//   Y-  = inner (body-facing, switch side)
//   Z+  = up from forearm surface (dome peak)
//   Z=0 = case rim / base plate top / print bed plane
//   Origin: center of case footprint at rim plane

// ── Manifold epsilon ──
EPS = 0.1;  // prevents coincident faces in difference()

// ── Ergonomic Measurements (caliper) ──
forearm_width     = 100;   // cross-section where band sits
finger_splay      = 105;   // comfortable relaxed splay, pinky-to-index outer edges
// Hand position: pronated (palm down), relaxed — no pinky/thumb squeeze

// ── Body ──
body_length   = 110;   // along forearm axis — finger_splay (105) + margins
body_width    = 100;   // across forearm — matches forearm_width
body_height   = 60;    // dome peak (top of grip cylinder, 2 * grip_r)
wall_thickness = 4.0;   // 4mm shells for structural integrity
corner_radius  = 5;

// ── Grip Cylinder ──
// Cylinder axis along X (forearm direction). Hand wraps around Y- side.
// Buttons on the near-vertical front face at Y ≈ grip_cy + grip_r.
// Battery stands inside the cylinder (34mm tall, 36mm inner diameter).
grip_r  = 30;               // grip radius — 60mm outer diameter
grip_cy = -grip_r;          // Y center: equator (vertical face) at Y=0
grip_cz = grip_r;           // Z center: tangent to Z=0, peak at Z=60

// ── Screen Shelf ──
// Flat area on Y+ side of grip for OLED visibility.
// Gentle slope from grip front, steep drop at outer edge.
shelf_z       = 20;    // shelf height (slightly below grip equator)
shelf_start_y = 3;     // where shelf begins (past grip equator)
shelf_end_y   = 42;    // where steep drop begins
shelf_drop_z  = 5;     // Z at outer edge before rim

// ── Base Plate ──
base_plate_thick = 4.0;   // 4mm — allows 2mm deep M2 head countersink + 2mm remaining

// ── Pimoroni Pico Plus 2 W ──
// Same footprint as standard Pico 2W (USB-C, RP2350, 8MB PSRAM, 16MB flash)
pico_length = 52.3;
pico_width  = 21.0;
pico_height = 3.7;
pico_hole_spacing_l = 47.0;  // mounting hole center-to-center lengthwise
pico_hole_spacing_w = 11.4;  // mounting hole center-to-center widthwise
pico_hole_dia       = 2.1;   // M2 through-hole

// ── Pico Layout ──
pico_x_offset = 0;
pico_y_offset = 0;              // centered (ridge side is too low)
pico_standoff_height = 3;       // standoff boss height on base plate

// ── LiPo SHIM for Pico ──
// Pimoroni PIM557 — sandwiches under Pico on headers.
// Handles LiPo charging via Pico USB-C, has built-in power button + LEDs.
// Replaces TP4056 and slide switch.
shim_width  = 21.0;   // same width as Pico
shim_length = 21.0;
shim_height = 7.0;    // including JST connector height
// Combined stack: SHIM (7mm) + Pico (3.7mm) = ~11mm
pico_stack_height = shim_height + pico_height;  // total height of SHIM+Pico

// ── OLED Small 1.3" (SH1106, Build 2A) — caliper-measured ──
oled_sm_board_w     = 33;
oled_sm_board_h     = 33;
oled_sm_vis_w       = 30;
oled_sm_vis_h       = 15;
oled_sm_vis_top     = 8;      // visible area starts 8mm from top edge
oled_sm_vis_side    = 3;      // visible area starts 3mm from side edges
oled_sm_hole_sp     = 29;     // 27mm nominal + 2mm wider for fit (both axes)

// ── OLED Large 2.42" (SSD1309, Build 2B) — caliper-measured ──
oled_lg_board_w     = 70;
oled_lg_board_h     = 48;
oled_lg_vis_w       = 55;
oled_lg_vis_h       = 29;
oled_lg_vis_top     = 7;      // visible area starts 7mm from top edge
oled_lg_vis_side    = 7;      // visible area starts 7mm from side edges (each side)
oled_lg_hole_sp_w   = 66;     // 64mm nominal + 2mm wider for fit
oled_lg_hole_sp_h   = 42;     // 48 - 3mm inset each side = 42mm c-c

// ── OLED shared mount ──
oled_board_thick    = 10;     // with wires routed underneath
oled_hole_dia       = 2.0;   // M2 through-hole
oled_head_dia       = 3.5;   // M2 button head countersink
oled_head_depth     = 2.0;   // countersink depth in 4mm backing plate

// ── Buttons ──
button_diameter = 6;
button_spacing  = 14;   // center-to-center (legacy, see positions below)
button_travel   = 1.5;
button_well_depth = 3;  // depth of recessed well
button_well_dia   = 9;  // well outer diameter (button + clearance)
// Actual button housing dimensions (measured from button)
button_outer_dia  = 8.5;    // hole on finger-facing (outer) wall
button_inner_dia  = 10.8;   // wider hole on inside wall (retains button)
button_wall_thick = 3.25;   // wall thickness the button is designed for

// ── Thumb Buttons (half-size, on elbow-side flat wall) ──
thumb_outer_dia = button_outer_dia / 2;
thumb_inner_dia = button_inner_dia / 2;
thumb_positions = [
    [-35, 15],   // Lower thumb — [Y_offset_from_center, Z_height]
    [-35, 25],   // Upper thumb
];
// Y=-35: 15mm from inner wall (Y=-50). Bore along -X into flat elbow wall.

// ── Button Layout (on grip face) ──
// Format: [X_along_forearm, Z_height_on_grip]
// Y position is computed from the cylinder surface at each Z.
// Wells bore horizontally (-Y) into the grip face.
// Z follows finger curl arc: outer fingers (index/pinky) higher,
// inner fingers (middle/ring) lower — natural "smile" curve.
button_positions = [
    [ 40, 52],   // Index  — 30mm from middle, +20mm Z
    [ 10, 32],   // Middle — baseline (on cylinder arc, above Z=30 transition)
    [-10, 32],   // Ring   — 20mm from middle, same Z
    [-30, 47],   // Pinky  — 20mm from ring, +15mm Z
];
// X gaps: 30mm (I→M), 20mm (M→R), 20mm (R→P)
// Z: middle/ring at 32 (above cylinder-to-shelf transition at Z=30)
// Index +20, pinky +15 above baseline. All on cylinder arc (Z=30..60).

// ── Switch Slot (MSK-12C02 slide switch, on wrist wall) ──
switch_slot_width  = 4.0;   // actuator slot (2mm travel + clearance)
switch_slot_height = 2.0;
switch_slot_radius = 0.5;
switch_y_offset    = 12;    // Y offset from center on wrist wall
switch_pedestal_height = 14;  // internal pedestal — aligns switch with wrist wall cutout

// ── USB-C ──
usbc_width  = 9.0;
usbc_height = 3.5;
usbc_radius = 1.5;   // corner rounding

// ── Mounting ──
// Velcro attachment to neoprene forearm band.
// Adhesive hook velcro on base bottom, loop velcro on neoprene band.
velcro_patch_length = 70;
velcro_patch_width  = 80;
velcro_recess_depth = 1.0;  // flush recess in base bottom

// ── Battery — caliper-measured ──
// Small: 25 x 39 x 6mm (502535)
// Large: 34 x 55 x 6mm
battery_length = 55;   // using large battery
battery_width  = 34;
battery_height = 6;
battery_clearance = 0.5;
battery_x_offset = 0;       // centered lengthwise
battery_y_offset = -body_width/2 + wall_thickness + battery_height/2 + battery_clearance;
// Standing on 6mm edge against inner wall: 55mm along X, 6mm in Y, 34mm tall in Z

// ── Fasteners (M2 button head) ──
m2_screw_dia    = 2.2;   // clearance hole
m2_insert_dia   = 3.2;   // heat-set insert hole
m2_insert_depth = 4.0;
m2_head_dia     = 3.8;   // button head is ~3.8mm dia
m2_head_depth   = 1.0;   // button head is ~1mm tall

// ── Screw Positions (shared between base and dome) ──
screw_positions = [
    [ body_length/2 - 10,  body_width/2 - 8],
    [-body_length/2 + 10,  body_width/2 - 8],
    [ body_length/2 - 10, -body_width/2 + 8],
    [-body_length/2 + 10, -body_width/2 + 8],
];

// ── Button Caps ──
button_cap_dia      = button_well_dia - 0.6;
button_cap_height   = button_well_depth - 0.5;
button_cap_stem_dia = button_diameter - 0.2;
button_cap_stem_h   = 2.0;
button_cap_dish     = 0.4;

// ── Ventilation ──
vent_slot_width  = 1.0;
vent_slot_length = 8.0;
vent_slot_spacing = 3.0;

// ── Named Wall Positions ──
// Use these instead of raw ±body_length/2 to prevent spatial errors.
// "wall" = outer surface of shell at that edge.
wall_wrist  = -body_length / 2;   // X- face (USB-C end)
wall_elbow  =  body_length / 2;   // X+ face
wall_outer  =  body_width  / 2;   // Y+ face (away from body, dome peak side)
wall_inner  = -body_width  / 2;   // Y- face (body-facing, switch side)
wall_top    =  body_height;       // Z+ (dome peak)
wall_bottom =  0;                 // Z=0 (rim plane / print bed)

// ── Derived ──
inner_length = body_length - 2 * wall_thickness;
inner_width  = body_width  - 2 * wall_thickness;
inner_height = body_height;  // open bottom, full height available

// ── Tolerances ──
print_tolerance = 0.2;  // FDM clearance
$fn = 60;               // global resolution

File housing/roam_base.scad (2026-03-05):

// roam_base.scad — Base plate for Roam wrist-mount controller
// Just the plate, screw holes, and velcro recess.
// All interior mounting (pedestals, standoffs, lip) left for manual design.
//
// ORIENTATION: see common.scad header
//   Plate lies flat at Z=0. Velcro recess faces down (Z-).
//   Screw countersinks on bottom face, through-holes match dome bosses.

include <common.scad>


// ════════════════════════════════════════════════════════════
// Modules
// ════════════════════════════════════════════════════════════

// Base plate — 2.5mm thick rounded rectangle (90x50mm)
module base_plate() {
    linear_extrude(height = base_plate_thick)
        offset(r = corner_radius)
            offset(delta = -corner_radius)
                square([body_length, body_width], center = true);
}

// Screw holes — 4 countersunk M2 through-holes from bottom
module screw_holes() {
    for (pos = screw_positions)
        translate([pos[0], pos[1], -0.1]) {
            cylinder(d = m2_screw_dia, h = base_plate_thick + 0.2);
            cylinder(d = m2_head_dia, h = m2_head_depth + 0.1);
        }
}

// Velcro recess — 70x38mm, 1mm deep on bottom face
module velcro_recess() {
    translate([0, 0, -0.1])
        linear_extrude(height = velcro_recess_depth + 0.1)
            offset(r = 2)
                offset(delta = -2)
                    square([velcro_patch_length, velcro_patch_width], center = true);
}


// ════════════════════════════════════════════════════════════
// Assembly
// ════════════════════════════════════════════════════════════

module roam_base() {
    difference() {
        base_plate();
        screw_holes();
        velcro_recess();
    }
}

roam_base();

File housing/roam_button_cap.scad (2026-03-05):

// roam_button_cap.scad — Printable button cap for Roam tactile switches
// Sits in the button well, contacts switch nub underneath
// Print 4x in PLA or TPU (TPU gives softer click feel)
//
// ORIENTATION: see common.scad header
//   Cap printed dish-up. Stem extends downward (Z-) to contact switch.
//   Dish concavity on top (Z+) for finger grip.

include <common.scad>

module button_cap() {
    difference() {
        union() {
            // Main cap body — cylinder that sits in the well
            cylinder(d = button_cap_dia, h = button_cap_height);

            // Stem — narrower cylinder that reaches down to the switch nub
            translate([0, 0, -button_cap_stem_h])
                cylinder(d = button_cap_stem_dia, h = button_cap_stem_h + 0.01);
        }

        // Concave dish on top for finger grip
        translate([0, 0, button_cap_height])
            scale([1, 1, button_cap_dish / (button_cap_dia / 2)])
                sphere(d = button_cap_dia);
    }
}

button_cap();

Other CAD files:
roam-touch/cad/out/roam_worn.step
roam-touch/cad/out/roam_cover_shut.stl
roam-touch/cad/out/roam_step3.step
roam-touch/cad/out/sample_band.stl
housing/roam_case.scad
housing/roam_base.stl
housing/roam_button_cap.stl
housing/roam_case.stl
housing/roam_dome.scad
housing/roam_dome.stl
housing/roam_lid.scad
housing/roam_lid.stl
housing/roam_screen_adapter.scad
roam-touch/cad/out/bracer.step
roam-touch/cad/out/bracer.stl
roam-touch/cad/out/bracer_endcap.step
roam-touch/cad/out/bracer_endcap.stl
roam-touch/cad/out/bracer_endcap_print.stl
roam-touch/cad/out/bracer_pack.step
roam-touch/cad/out/bracer_pack.stl
roam-touch/cad/out/bracer_pack_print.stl
roam-touch/cad/out/bracer_print.stl
roam-touch/cad/out/housing_slots.stl
roam-touch/cad/out/landscape.step
roam-touch/cad/out/landscape.stl
roam-touch/cad/out/landscape_print.stl
roam-touch/cad/out/roam_assembly.stl
roam-touch/cad/out/roam_cap.stl
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

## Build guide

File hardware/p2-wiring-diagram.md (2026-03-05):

# Roam P2 — Wiring Diagram (Build 2A: SH1106 Screen)

Complete point-to-point wiring for the Seeed XIAO nRF52840 Sense build.
Small screen (1.3" SH1106) + 502535 LiPo battery + slide switch.

## Board Pinout Reference

```
                      ┌───USB-C───┐
                D0  ──┤  [RST]    ├── 5V (VUSB)
                D1  ──┤           ├── GND
                D2  ──┤           ├── 3V3
                D3  ──┤           ├── D10
       SDA ◄── D4  ──┤           ├── D9 ──► Scroll Back
       SCL ◄── D5  ──┤           ├── D8 ──► Scroll Fwd
     Motor ◄── D6  ──┤           ├── D7 ──► LED
                      ├───────────┤
                      │  BAT(JST) │
                      └───────────┘
```

## Power Circuit

```
 ╔══════════════════════════════════════════════════════════════════════╗
 ║  POWER — Battery + switch on positive rail                         ║
 ║                                                                    ║
 ║                        MSK-12C02                                   ║
 ║                      ┌───┤├───┐                                    ║
 ║   LiPo BAT+ ────────┤ 1  2  3├                                    ║
 ║     (red)            └───┬────┘                                    ║
 ║                          │                                         ║
 ║                      SWITCHED +V ──┬── OLED VCC                    ║
 ║                                    ├── Motor (+)                   ║
 ║                                    └── (any 5V loads)              ║
 ║                                                                    ║
 ║   LiPo BAT- ──── GND rail ──┬── XIAO GND pad                     ║
 ║     (black)                  ├── OLED GND                          ║
 ║                              ├── Motor (-) via NPN                 ║
 ║                              ├── LED (-)                           ║
 ║                              └── All button commons                ║
 ║                                                                    ║
 ║   Switch wiring (3-pin SPDT, MSK-12C02):                          ║
 ║     Pin 1 (common/center) ── BAT+                                  ║
 ║     Pin 2 (one side)      ── SWITCHED +V                           ║
 ║     Pin 3 (other side)    ── (not connected)                       ║
 ║                                                                    ║
 ║   XIAO battery: connect via JST connector on underside,            ║
 ║   OR solder BAT+/BAT- pads directly. BAT- = GND (same net).       ║
 ║                                                                    ║
 ║   USB-C: charges battery when plugged in (onboard charger).        ║
 ║   VUSB pad: NOT wired — not needed for battery operation.          ║
 ╚══════════════════════════════════════════════════════════════════════╝
```

## OLED Display

```
 ╔══════════════════════════════════════════════════════════════════════╗
 ║  OLED DISPLAY — SH1106 128×64 1.3" I2C                            ║
 ║                                                                    ║
 ║       SWITCHED +V ───────────────────── VCC                        ║
 ║          D4 (SDA) ───────────────────── SDA                        ║
 ║          D5 (SCL) ───────────────────── SCL                        ║
 ║          GND ────────────────────────── GND                        ║
 ║                                                                    ║
 ║   VCC is battery voltage through the switch (~3.7–4.2V).           ║
 ║   SH1106 charge pump works at LiPo voltages — confirmed working.  ║
 ║                                                                    ║
 ║   Firmware uses TWIM1 (not Wire library, not TWIM0).               ║
 ║   TWIM0 conflicts with BLE softdevice — data writes hang.          ║
 ║   No external pull-ups needed — module has onboard pull-ups.       ║
 ║                                                                    ║
 ║   Pin order on module (verify yours): GND, VCC, SCL, SDA          ║
 ╚══════════════════════════════════════════════════════════════════════╝
```

## Buttons

```
 ╔══════════════════════════════════════════════════════════════════════╗
 ║  BUTTONS — Tactile switches, active low                            ║
 ║                                                                    ║
 ║   Internal pull-ups enabled in firmware (no external resistors)    ║
 ║                                                                    ║
 ║          D0 ───────┤ ○  ○ ├────── GND      Index  (Dictation)     ║
 ║          D1 ───────┤ ○  ○ ├────── GND      Middle (Mode)          ║
 ║          D2 ───────┤ ○  ○ ├────── GND      Ring   (Yes/Approve)   ║
 ║          D3 ───────┤ ○  ○ ├────── GND      Pinky  (No/Escape)    ║
 ║                                                                    ║
 ║          D8 ───────┤ ○  ○ ├────── GND      Scroll Forward (thumb) ║
 ║          D9 ───────┤ ○  ○ ├────── GND      Scroll Back (thumb)    ║
 ║                                                                    ║
 ║   Physical layout (top face, left hand on right forearm):          ║
 ║                                                                    ║
 ║        ┌──────── elbow side ────────┐                              ║
 ║        │                            │                              ║
 ║        │  [Index] [Middle] [Ring] [Pinky]   ◄── top face           ║
 ║        │                            │                              ║
 ║        │                 [Scrl Fwd] │   ◄── right side wall        ║
 ║        │                [Scrl Back] │                              ║
 ║        │                            │                              ║
 ║        └──────── wrist side ────────┘                              ║
 ║                                                                    ║
 ║   Button actions:                                                  ║
 ║     Index  = D0  short: Dictation    long: Tmux pane               ║
 ║     Middle = D1  short: Cycle mode   long: BLE switch              ║
 ║     Ring   = D2  short: y + Enter    long: Tab + Enter             ║
 ║                  double: Enter only                                ║
 ║     Pinky  = D3  short: Escape       long: Ctrl+C                 ║
 ║     Scroll Fwd  = D8  short/long: next message                    ║
 ║     Scroll Back = D9  short/long: prev message                    ║
 ╚══════════════════════════════════════════════════════════════════════╝
```

## Motor

```
 ╔══════════════════════════════════════════════════════════════════════╗
 ║  VIBRATION MOTOR — NPN transistor driver                           ║
 ║                                                                    ║
 ║   SWITCHED +V ──────┬──────────── Motor (+, red)                   ║
 ║                      │                │                            ║
 ║                 ┌──┤◄├──┐        Motor (-, blue)                   ║
 ║                 │ 1N4148 │            │                            ║
 ║                 │(flyback)│           │                            ║
 ║                 └────────┘     ┌──────┘                            ║
 ║                                │  C                                ║
 ║                              ┌─┴─┐                                 ║
 ║          D6 ──── 1kΩ ───── B│NPN │ 2N2222                         ║
 ║                              └─┬─┘                                 ║
 ║                                │  E                                ║
 ║                               GND                                  ║
 ║                                                                    ║
 ║   Motor powered from switched battery voltage (~3.7–4.2V).        ║
 ║   Flyback diode: cathode (band) toward positive rail.             ║
 ╚══════════════════════════════════════════════════════════════════════╝
```

## LED

```
 ╔══════════════════════════════════════════════════════════════════════╗
 ║  STATUS LED                                                        ║
 ║                                                                    ║
 ║          D7 ──── 100Ω ──── LED (+) ──── LED (-) ──── GND          ║
 ║                               ▲                                    ║
 ║                          5mm red                                   ║
 ║                        (diffused)                                  ║
 ║                                                                    ║
 ║   LED driven from 3.3V GPIO — no switched power needed.            ║
 ║   ~15mA at 3.3V with 100Ω.                                        ║
 ║                                                                    ║
 ║   NOTE: LED_BUILTIN (red, next to USB-C) is active LOW.           ║
 ║   Currently used for BLE status blink in firmware.                 ║
 ║   ROAM_LED_PIN (D7) initialized but not yet driven in loop.       ║
 ╚══════════════════════════════════════════════════════════════════════╝
```

## Battery Monitoring

```
 ╔══════════════════════════════════════════════════════════════════════╗
 ║  BATTERY MONITORING (firmware, no extra wiring)                    ║
 ║                                                                    ║
 ║   PIN_VBAT reads battery voltage via nRF52's internal ADC.         ║
 ║   No external voltage divider needed — built into the board.       ║
 ║                                                                    ║
 ║   LiPo discharge curve: 4.2V=100%, 3.7V=50%, 3.3V=10%, 3.0V=0%  ║
 ║   Sampled every 60 seconds, displayed in status bar.               ║
 ╚══════════════════════════════════════════════════════════════════════╝
```

## Bill of Materials

| Qty | Component | Value/Spec | Notes |
|-----|---|---|---|
| 1 | Seeed XIAO nRF52840 Sense | nRF52840 + BLE 5.0 | Main MCU + BLE |
| 1 | SH1106 OLED module | 128×64, 1.3", I2C | 4-pin (GND/VCC/SCL/SDA) |
| 4 | Tactile switch | 6×6mm | Main buttons (D0-D3) |
| 2 | Tactile switch | 6×6mm | Scroll buttons (D8-D9) |
| 1 | Vibration motor | 3V coin type | Powered from switched BAT+ |
| 1 | 2N2222 NPN transistor | or equivalent | Motor driver |
| 1 | 1N4148 diode | Signal diode | Flyback protection |
| 1 | LED | 5mm red diffused | Status indicator |
| 1 | LiPo battery | 3.7V 502535 (400mAh)  | JST SH 1.0mm connector |
| 1 | Slide switch | MSK-12C02 SPDT | Power on/off |
| 1 | Resistor | 100Ω | LED current limit |
| 1 | Resistor | 1kΩ | NPN base |

## Wire Color Convention (suggested)

| Color  | Signal |
|---|---|
| Red | BAT+ / +V |
| Black  | GND |
| Blue | SDA |
| Yellow | SCL |
| White  | Button wires |
| Green  | Motor / LED  |

## Flashing

The XIAO is enclosed in the housing — reset button is not accessible.
Use 1200-baud touch to enter DFU bootloader over USB:

```bash
python3 -c "import serial, time; s = serial.Serial('PORT', 1200); time.sleep(0.5); s.close()"
# Wait 3 seconds, then flash:
make p2-flash
```

Port name varies between flashes (`usbmodem101`, `usbmodem1101`, `usbmodem2101`).
Always check `arduino-cli board list` first.

## Hardware Gotchas

- **TWIM0 conflicts with Bluefruit**: BLE softdevice uses the same peripheral group.
  Display MUST use TWIM1 with direct register access. See `display.cpp`.
- **Wire library has no timeouts**: Seeed BSP spins forever on stuck I2C.
  Firmware uses raw TWIM1 registers with timeout loop.
- **SH1106 works on LiPo voltage**: Charge pump runs fine at 3.7–4.2V.
  Previous assumption that 5V was required was wrong.
- **LED_BUILTIN is active LOW**: `LOW` = on, `HIGH` = off.
- **Port flapping**: Serial port name changes between flashes. Always check
  `arduino-cli board list` before flashing.
- **Switch on positive rail**: MSK-12C02 between BAT+ and all loads (OLED, motor).
  XIAO itself always powered via JST — switch only controls peripherals.

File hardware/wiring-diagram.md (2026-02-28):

# Roam P1 — Wiring Diagram

Complete point-to-point wiring for the Pimoroni Pico Plus 2 W build.

## Board Pinout Reference

```
                        ┌───USB-C───┐
                  GP0  ─┤ 1      40 ├─ VBUS
                  GP1  ─┤ 2      39 ├─ VSYS ◄── TP4056 OUT+ (via switch)
                  GND  ─┤ 3      38 ├─ GND
                  GP2  ─┤ 4      37 ├─ 3V3_EN
                  GP3  ─┤ 5      36 ├─ 3V3 OUT
         SDA ◄── GP4  ─┤ 6      35 ├─ ADC_VREF
         SCL ◄── GP5  ─┤ 7      34 ├─ GP28 (ADC2)
                  GND  ─┤ 8      33 ├─ GND / AGND
                  GP6  ─┤ 9      32 ├─ GP27 (ADC1)
                  GP7  ─┤10      31 ├─ GP26 (ADC0)
                  GP8  ─┤11      30 ├─ RUN
                  GP9  ─┤12      29 ├─ GP22
                  GND  ─┤13      28 ├─ GND
  Btn Dictate ◄── GP10 ─┤14      27 ├─ GP21
     Btn Mode ◄── GP11 ─┤15      26 ├─ GP20
      Btn Yes ◄── GP12 ─┤16      25 ├─ GP19
       Btn No ◄── GP13 ─┤17      24 ├─ GP18
                  GND  ─┤18      23 ├─ GND
                  GP14 ─┤19      22 ├─ GP17
       Motor ◄── GP15 ─┤20      21 ├─ GP16 ──► LED
                        └──────────┘
```

## Circuit Diagram

```
 ╔══════════════════════════════════════════════════════════════════════╗
 ║  POWER                                                              ║
 ║                                                                     ║
 ║   LiPo 3.7V 400mAh          TP4056 Module         Slide Switch     ║
 ║   ┌──────────┐           ┌──────────────┐         ┌─────┐          ║
 ║   │  502535   │    B+ ───┤ BAT+    OUT+ ├─────────┤ ○ ○ ├──► VSYS  ║
 ║   │  + ─── ──│──────────┤ BAT-    OUT- ├──┐      └─────┘          ║
 ║   │  - ─── ──│──────────┤ GND          │  └────────────────► GND   ║
 ║   └──────────┘           └──────┬───────┘                           ║
 ║                                 │ USB-C                             ║
 ║                              (charge in)                            ║
 ╚══════════════════════════════════════════════════════════════════════╝

 ╔══════════════════════════════════════════════════════════════════════╗
 ║  OLED DISPLAY — SH1106 128×64 1.3"                                 ║
 ║                                                                     ║
 ║       VBUS (5V) ──────────────────────── VCC                        ║
 ║          GP4 (SDA) ─────────────────── SDA (or SDK/SCK label)       ║
 ║          GP5 (SCL) ─────────────────── SCL (or SCK label)           ║
 ║          GND ─────────────────────────── GND                        ║
 ║                                                                     ║
 ║   CRITICAL: VCC must be 5V (+ pad / VBUS), NOT 3.3V (3E pad).      ║
 ║   At 3.3V the I2C bus responds (device found at 0x3C) but the      ║
 ║   OLED panel doesn't light up — charge pump needs higher voltage.   ║
 ║   I2C data lines remain 3.3V logic via the Pico's GPIO.            ║
 ║                                                                     ║
 ║   Screen pin labels vary by brand: may say VOC/VCC, SCK/SCL.       ║
 ║   Pin order: GND, VCC, SCL, SDA (verify on your module).           ║
 ║   No external pull-ups needed — modules have onboard pull-ups.      ║
 ╚══════════════════════════════════════════════════════════════════════╝

 ╔══════════════════════════════════════════════════════════════════════╗
 ║  BUTTONS — Tactile switches, active low                             ║
 ║                                                                     ║
 ║   Internal pull-ups enabled in firmware (no external resistors)     ║
 ║                                                                     ║
 ║          GP10 ──────┤ ○  ○ ├────── GND      Index  (Dictation)     ║
 ║          GP11 ──────┤ ○  ○ ├────── GND      Middle (Mode)          ║
 ║          GP12 ──────┤ ○  ○ ├────── GND      Ring   (Yes/Approve)   ║
 ║          GP13 ──────┤ ○  ○ ├────── GND      Pinky  (No/Escape)    ║
 ║                                                                     ║
 ║   Physical layout (left hand on right forearm, buttons face up):    ║
 ║                                                                     ║
 ║        ┌─── elbow side ───┐                                         ║
 ║        │                  │                                         ║
 ║        │  [Index] [Middle]│     Index  = GP10 (short: dictation,    ║
 ║        │                  │                    long:  tmux pane)    ║
 ║        │  [Ring]  [Pinky] │     Middle = GP11 (short: cycle mode,   ║
 ║        │                  │                    long:  BLE switch)   ║
 ║        │                  │     Ring   = GP12 (short: y + Enter,    ║
 ║        └─── wrist side ──┘                    long:  Tab + Enter,  ║
 ║                                               double: Enter only)  ║
 ║                                  Pinky  = GP13 (short: Escape,      ║
 ║                                                 long:  Ctrl+C)     ║
 ╚══════════════════════════════════════════════════════════════════════╝

 ╔══════════════════════════════════════════════════════════════════════╗
 ║  VIBRATION MOTOR — NPN transistor driver                            ║
 ║                                                                     ║
 ║         VBUS (5V) ─────┬──────────── Motor (+, red)                 ║
 ║                        │                │                           ║
 ║                   ┌──┤◄├──┐        Motor (-, blue)                  ║
 ║                   │ 1N4148 │            │                           ║
 ║                   │(flyback)│           │                           ║
 ║                   └────────┘     ┌──────┘                           ║
 ║                                  │  C                               ║
 ║                                ┌─┴─┐                                ║
 ║          GP15 ──── 1kΩ ───── B│NPN │ 2N2222                        ║
 ║                                └─┬─┘                                ║
 ║                                  │  E                               ║
 ║                                 GND                                 ║
 ║                                                                     ║
 ║   Motor positive → + pad (VBUS/5V), NOT 3E (3.3V).                 ║
 ║   Coin motors rated 3V won't spin at 3.3V through transistor.      ║
 ║   Flyback diode: cathode (band) toward VBUS side.                  ║
 ╚══════════════════════════════════════════════════════════════════════╝

 ╔══════════════════════════════════════════════════════════════════════╗
 ║  STATUS LED                                                         ║
 ║                                                                     ║
 ║          GP16 ──── 220Ω ──── LED (+) ──── LED (-) ──── GND         ║
 ║                                 ▲                                   ║
 ║                            5mm red                                  ║
 ║                          (diffused)                                 ║
 ║                                                                     ║
 ║   ~7mA at 3.3V. Solid when BLE connected, blink when advertising.  ║
 ║   NOTE: Do NOT use "fast flashing RGB" LEDs — they have a          ║
 ║   built-in IC that cycles colors automatically. Use plain LEDs.     ║
 ╚══════════════════════════════════════════════════════════════════════╝

 ╔══════════════════════════════════════════════════════════════════════╗
 ║  BATTERY MONITORING (firmware, no extra wiring)                     ║
 ║                                                                     ║
 ║   GP29 (ADC3) reads VSYS/3 via onboard voltage divider.            ║
 ║   No external components needed — this is built into the Pico.      ║
 ║                                                                     ║
 ║   WARNING: Do NOT toggle GP25 — it's shared with CYW43 wireless    ║
 ║   SPI. Driving it as GPIO kills BLE. Battery reads work without     ║
 ║   GP25 coordination; slight ADC noise is acceptable.                ║
 ╚══════════════════════════════════════════════════════════════════════╝

## Bill of Materials

| Qty | Component                    | Value/Spec            | Notes                           |
|-----|------------------------------|-----------------------|---------------------------------|
| 1   | Pimoroni Pico Plus 2 W       | RP2350 + CYW43439     | Main MCU + BLE                  |
| 1   | SH1106 OLED module           | 128×64, 1.3", I2C     | 4-pin (VCC/GND/SCL/SDA)        |
| 4   | Tactile switch               | 6×6mm                 | Through-hole or panel mount     |
| 1   | Vibration motor              | 3V coin type          | Powered from VBUS (5V)          |
| 1   | 2N2222 NPN transistor        | or equivalent          | Motor driver                    |
| 1   | 1N4148 diode                 | Signal diode           | Flyback protection              |
| 1   | LED                          | 5mm red diffused       | Plain single-color, NOT RGB     |
| 1   | TP4056 module                | USB-C, DW01 protection| LiPo charger                    |
| 1   | LiPo battery                 | 502535, 3.7V 400mAh   |                                 |
| 1   | Slide switch                 | MSK-12C02 style        | Power on/off                    |
| 1   | Resistor                     | 220Ω (red-red-brown)  | LED current limit               |
| 1   | Resistor                     | 1kΩ                   | NPN base                        |
| 2   | Resistor (optional)          | 4.7kΩ                 | I2C pull-ups (if not on module) |

## Wire Color Convention (suggested)

| Color  | Signal     |
|--------|------------|
| Red    | 5V / VSYS  |
| Black  | GND        |
| Blue   | SDA        |
| Yellow | SCL        |
| White  | Button wires |
| Green  | Motor / LED |

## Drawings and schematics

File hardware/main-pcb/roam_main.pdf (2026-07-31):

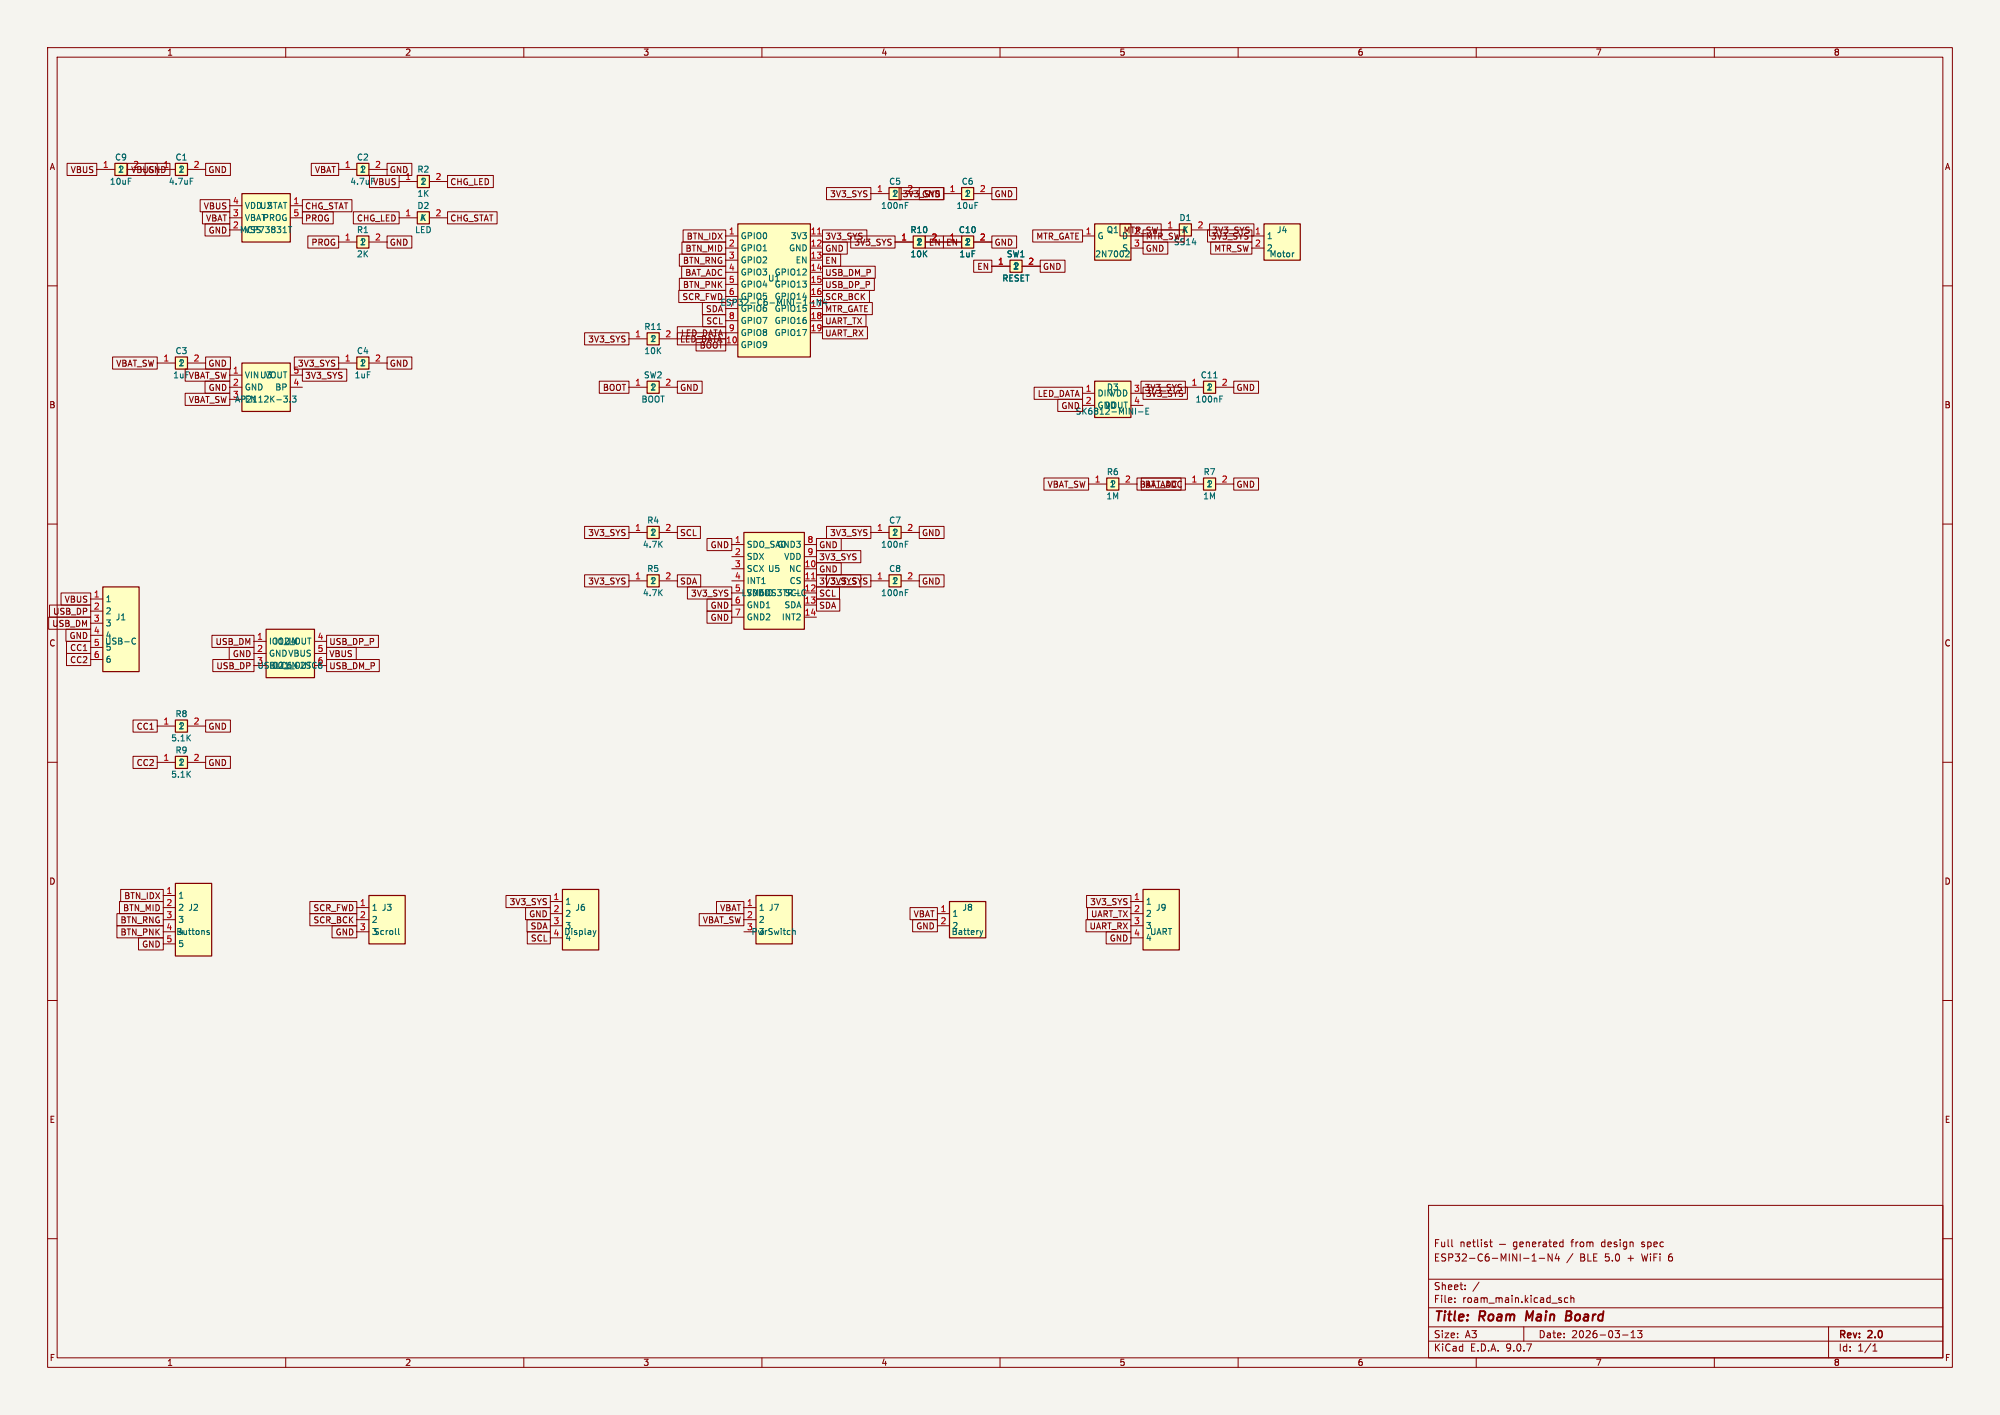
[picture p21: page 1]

Id: 1/1 Title: Roam Main Board

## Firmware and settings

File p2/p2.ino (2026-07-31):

// Roam P2 — Bluefruit BLE HID Firmware
// Seeed XIAO nRF52840 Sense (nRF52840 + BLE 5.0)
// Board: Seeeduino:nrf52:xiaonRF52840Sense

#include <bluefruit.h>
#include "config.h"
#include "buttons.h"
#include "actions.h"
#include "display.h"
#include "battery.h"
#include "ble_text.h"
#include "imu.h"
#include "audio_stream.h"

BLEHidAdafruit blehid;
BLEDis bledis;   // Device Information Service

static ButtonManager buttons;
static Button scrollFwd;
static Button scrollBack;
static Display display;
static Battery battery;

// Active profile. Phone-relay mode keeps Android as the only live BLE peer.
#if ROAM_PHONE_RELAY_MODE
volatile Profile activeProfile = PROFILE_ANDROID;
#else
volatile Profile activeProfile = PROFILE_MAC;
#endif

// Known device MAC (first 3 bytes = OUI). Set to 0 to match any.
// After pairing your Android phone, replace with its MAC.
// Format: {0xAA, 0xBB, 0xCC, 0xDD, 0xEE, 0xFF}
static uint8_t knownMacMAC[6]     = {0};  // Will be learned on first Mac connection
static uint8_t knownAndroidMAC[6] = {0};  // Will be learned on first Android connection
static bool macLearned = false;
static bool androidLearned = false;

// LED state — can be toggled by user, auto-off on sleep
static bool ledEnabled = true;
static uint32_t lastAdvertisingCheck = 0;

void bleSwitch() {
    // Remove bond for current peer so it can't auto-reconnect
    if (Bluefruit.connected()) {
        BLEConnection* conn = Bluefruit.Connection(Bluefruit.connHandle());
        conn->removeBondKey();
        Serial.println("BLE Switch: bond removed for current peer");
        Bluefruit.disconnect(Bluefruit.connHandle());
    }
    delay(200);
    Bluefruit.Advertising.start(0);
}

// --- BLE callbacks ---
void connect_callback(uint16_t conn_handle) {
    BLEConnection* conn = Bluefruit.Connection(conn_handle);
    uint8_t addr[6];
    ble_gap_addr_t peer = conn->getPeerAddr();
    memcpy(addr, peer.addr, 6);

    Serial.printf("BLE: CONNECTED [%02X:%02X:%02X:%02X:%02X:%02X]\n",
                  addr[5], addr[4], addr[3], addr[2], addr[1], addr[0]);

    // Phone-relay mode: Android owns BLE; Mac receives traffic through Android.
    Profile prev = activeProfile;
#if ROAM_PHONE_RELAY_MODE
    activeProfile = PROFILE_ANDROID;
    display.setBleConnected(true);
    display.setProfileName(PROFILE_NAMES[activeProfile]);
    if (activeProfile != prev) {
        display.showAction(PROFILE_NAMES[activeProfile]);
    }
    Serial.println("Profile: Android (phone relay mode)");
    return;
#else
    // Auto-detect profile by MAC.
    if (macLearned && memcmp(addr, knownMacMAC, 6) == 0) {
        activeProfile = PROFILE_MAC;
    } else if (androidLearned && memcmp(addr, knownAndroidMAC, 6) == 0) {
        activeProfile = PROFILE_ANDROID;
    } else if (!macLearned) {
        // First unknown device → assume Mac
        memcpy(knownMacMAC, addr, 6);
        macLearned = true;
        activeProfile = PROFILE_MAC;
        Serial.println("Learned Mac MAC");
    } else if (!androidLearned) {
        // Second unknown device → assume Android
        memcpy(knownAndroidMAC, addr, 6);
        androidLearned = true;
        activeProfile = PROFILE_ANDROID;
        Serial.println("Learned Android MAC");
    }

    display.setBleConnected(true);
    display.setProfileName(PROFILE_NAMES[activeProfile]);
    if (activeProfile != prev || !macLearned) {
        display.showAction(PROFILE_NAMES[activeProfile]);
    }
    Serial.printf("Profile: %s\n", PROFILE_NAMES[activeProfile]);
#endif
}

void disconnect_callback(uint16_t conn_handle, uint8_t reason) {
    (void)conn_handle;
    (void)reason;
    Serial.println("BLE: Disconnected, re-advertising");
    display.setBleConnected(false);
}

void setup() {
    Serial.begin(115200);
    delay(500);

    pinMode(LED_BUILTIN, OUTPUT);
    digitalWrite(LED_BUILTIN, HIGH);  // Off (active low)
    pinMode(ROAM_LED_PIN, OUTPUT);
    pinMode(PIN_MOTOR, OUTPUT);
    digitalWrite(PIN_MOTOR, LOW);

    Serial.println("=== Roam P2 boot ===");

    // --- BLE Init ---
    Bluefruit.configPrphBandwidth(BANDWIDTH_MAX);
    Bluefruit.begin();
    Bluefruit.setTxPower(4);
    Bluefruit.setName("Roam2");
    Bluefruit.Periph.setConnectCallback(connect_callback);
    Bluefruit.Periph.setDisconnectCallback(disconnect_callback);

    // Device Information Service
    bledis.setManufacturer("Roam");
    bledis.setModel("P2");
    bledis.begin();

    // HID Keyboard
    blehid.begin();
    Serial.println("BLE HID started");

    // Custom text service (must be after blehid.begin)
    bleText.begin();

    // --- Advertising ---
    Bluefruit.Advertising.addFlags(BLE_GAP_ADV_FLAGS_LE_ONLY_GENERAL_DISC_MODE);
    Bluefruit.Advertising.addTxPower();
    Bluefruit.Advertising.addAppearance(BLE_APPEARANCE_HID_KEYBOARD);
    Bluefruit.Advertising.addService(blehid);
    if (!bleText.addToAdvertising()) {
        Serial.println("ble_text: WARNING text service not added to advertising");
    }
    Bluefruit.ScanResponse.addName();
    Bluefruit.Advertising.restartOnDisconnect(true);
    Bluefruit.Advertising.setInterval(32, 244);  // in units of 0.625ms
    Bluefruit.Advertising.setFastTimeout(30);     // fast mode for 30 seconds
    Bluefruit.Advertising.start(0);               // advertise forever
    Serial.println("BLE advertising as 'Roam2' with HID + text service");

    // --- Peripherals ---
    display.begin();
    display.setBleConnected(false);
    display.setProfileName(PROFILE_NAMES[activeProfile]);
    imuBegin();  // After display — swaps TWIM1 pins temporarily, then restores
    battery.begin();
    audioStream.begin();
    buttons.begin();
    scrollFwd.begin(PIN_BTN_SCROLL_FWD, 0);
    scrollBack.begin(PIN_BTN_SCROLL_BACK, 0);
}

void loop() {
    static uint32_t lastStatus = 0;
    static uint32_t lastRender = 0;
    bool connected = Bluefruit.connected();

    if (!connected && (millis() - lastAdvertisingCheck) > 1000) {
        lastAdvertisingCheck = millis();
        if (!Bluefruit.Advertising.isRunning()) {
            Bluefruit.Advertising.start(0);
            Serial.println("BLE: Advertising watchdog restarted advertising");
        }
    }

    // LED: off when sleeping or disabled, solid when connected, blink when advertising
    static uint32_t lastBlink = 0;
    static bool ledState = false;
    uint32_t idleNow = millis() - display.lastActivityTime();
    bool sleeping = idleNow >= SCREEN_OFF_MS;

    if (!ledEnabled || sleeping) {
        digitalWrite(LED_BUILTIN, HIGH);       // Off (active low)
        digitalWrite(ROAM_LED_PIN, LOW);       // Off (active high)
    } else if (connected) {
        digitalWrite(LED_BUILTIN, LOW);        // Solid on (active low)
        digitalWrite(ROAM_LED_PIN, HIGH);      // Solid on (active high)
    } else {
        if (millis() - lastBlink > 500) {
            ledState = !ledState;
            digitalWrite(LED_BUILTIN, ledState ? LOW : HIGH);
            digitalWrite(ROAM_LED_PIN, ledState ? HIGH : LOW);
            lastBlink = millis();
        }
    }

    // Print status every 2 seconds
    if (millis() - lastStatus > 2000) {
        display.printDiag();
        Serial.printf("imu_ready=%d\n", imuReady());
        lastStatus = millis();
    }

    // Poll buttons
    ActionType action = ACTION_NONE;
    buttons.poll(action);

    // Always poll scroll buttons to keep debounce state current
    ButtonEvent sfEvt = scrollFwd.poll();
    ButtonEvent sbEvt = scrollBack.poll();
    if (action == ACTION_NONE) {
        if (sfEvt == BTN_EVENT_LONG)
            action = ACTION_CLEAR_MSGS;
        else if (sfEvt == BTN_EVENT_SHORT)
            action = ACTION_SCROLL_FWD;
        else if (sbEvt == BTN_EVENT_SHORT || sbEvt == BTN_EVENT_LONG)
            action = ACTION_SCROLL_BACK;
    }

    if (action != ACTION_NONE) {
        bleText.notifyEvent(RELAY_EVENT_ACTION, (uint8_t)action, (uint8_t)activeProfile, millis());
        display.wake();  // Any button press wakes screen
        if (action == ACTION_CLEAR_MSGS) {
            display.clearMessages();
            display.showAction("Cleared");
            digitalWrite(PIN_MOTOR, HIGH);
            delay(80);
            digitalWrite(PIN_MOTOR, LOW);
            Serial.println("action: clear messages");
        } else if (action == ACTION_SCROLL_FWD || action == ACTION_SCROLL_BACK) {
            // Local action — no HID, no connection required
            if (action == ACTION_SCROLL_FWD) display.scrollFwd();
            else display.scrollBack();
            display.wake();
            digitalWrite(PIN_MOTOR, HIGH);
            delay(40);
            digitalWrite(PIN_MOTOR, LOW);
            Serial.printf("action: scroll %s\n",
                          action == ACTION_SCROLL_FWD ? "fwd" : "back");
        } else if (action == ACTION_LED_TOGGLE) {
            // Local action — toggle status LED
            ledEnabled = !ledEnabled;
            display.showAction(ledEnabled ? "LED On" : "LED Off");
            digitalWrite(PIN_MOTOR, HIGH);
            delay(40);
            digitalWrite(PIN_MOTOR, LOW);
            Serial.printf("action: LED %s\n", ledEnabled ? "on" : "off");
        } else if (action == ACTION_PROFILE_TOGGLE) {
            // Local action — no connection required
            executeAction(action);
            display.showAction(PROFILE_NAMES[activeProfile]);
            display.setProfileName(PROFILE_NAMES[activeProfile]);
            digitalWrite(PIN_MOTOR, HIGH);
            delay(60);
            digitalWrite(PIN_MOTOR, LOW);
            Serial.printf("action: profile -> %s\n", PROFILE_NAMES[activeProfile]);
        }
#if ROAM_PHONE_RELAY_MODE
        else if (action == ACTION_DICTATION_ANDROID) {
            // In phone-relay mode this button notifies Android over FF02; Android
            // starts/stops FF03 mic streaming over FF04.
            display.showAction("Mic Toggle");
            digitalWrite(PIN_MOTOR, HIGH);
            delay(40);
            digitalWrite(PIN_MOTOR, LOW);
            Serial.println("action: relay dictation toggle");
        }
        else if (action == ACTION_BLE_SWITCH) {
            executeAction(action);
            digitalWrite(PIN_MOTOR, HIGH);
            delay(80);
            digitalWrite(PIN_MOTOR, LOW);
            display.showAction(ACTION_NAMES[action]);
            Serial.println("action: BLE switch");
        } else {
            // Phone-relay mode sends Mac commands through Android -> Wi-Fi -> receiver.
            // Do not emit BLE HID to Android for these actions.
            digitalWrite(PIN_MOTOR, HIGH);
            delay(action == ACTION_TMUX_PANE ? 25 : 80);
            digitalWrite(PIN_MOTOR, LOW);
            display.showAction(ACTION_NAMES[action]);
            Serial.printf("action: relay command %s\n", ACTION_NAMES[action]);
        }
#else
        else if (connected) {
            executeAction(action);

            // Haptic feedback — quick pulse for pane switch, standard for rest
            digitalWrite(PIN_MOTOR, HIGH);
            delay(action == ACTION_TMUX_PANE ? 25 : 80);
            digitalWrite(PIN_MOTOR, LOW);

            display.showAction(ACTION_NAMES[action]);
            Serial.printf("action: %s\n", ACTION_NAMES[action]);
        } else {
            Serial.printf("action: %s (not connected)\n", ACTION_NAMES[action]);
        }
#endif
    }

    // Battery monitor (every 60s)
    if (battery.shouldRead()) {
        battery.read();
        display.setBatteryPercent(battery.percent());
        // USB power detection — battery icon handles visual feedback
    }

    // Check for BLE text pushes
    if (bleText.hasNewText()) {
        const char* raw = bleText.getText();
        uint8_t pane = MSG_PANE_GLOBAL;
        const char* text = raw;

        // Parse pane prefix: \x01 + pane_byte + text
        if (raw[0] == '\x01' && raw[1] != '\0') {
            pane = (uint8_t)raw[1];
            text = raw + 2;
        }

        // Pane-switch messages set the active filter, stored as global
        if (strncmp(text, "Pane ", 5) == 0) {
            display.setActivePane(pane);
            display.pushMessage(text);  // global
        } else {
            display.pushMessage(text, pane);
        }

        digitalWrite(PIN_MOTOR, HIGH);
        delay(60);
        digitalWrite(PIN_MOTOR, LOW);
        delay(80);
        digitalWrite(PIN_MOTOR, HIGH);
        delay(60);
        digitalWrite(PIN_MOTOR, LOW);
        Serial.printf("ble_text: pane=%d \"%s\"\n", pane, text);
    }

    if (bleText.hasControlCommand()) {
        uint8_t cmd = bleText.getControlCommand();
        if (cmd == RELAY_CONTROL_START_AUDIO) {
            if (audioStream.start()) {
                bleText.notifyEvent(RELAY_EVENT_PTT_START, 0, (uint8_t)activeProfile, millis());
                display.showAction("Mic On");
                display.wake();
            }
        } else if (cmd == RELAY_CONTROL_STOP_AUDIO) {
            audioStream.stop();
            bleText.notifyEvent(RELAY_EVENT_PTT_STOP, 0, (uint8_t)activeProfile, millis());
            display.showAction("Mic Off");
            display.wake();
        } else if (cmd == RELAY_CONTROL_STATUS_REQUEST) {
            bleText.notifyEvent(RELAY_EVENT_STATUS, 0, (uint8_t)activeProfile, millis());
        }
        Serial.printf("ble_relay: control=%u\n", cmd);
    }

    audioStream.poll(bleText);

    // IMU wake-on-motion — wrist rotation wakes screen
    if (imuWoke()) {
        display.wake();
    }

    // Screen sleep timer — recompute idle after all wake sources
    idleNow = millis() - display.lastActivityTime();
    if (idleNow >= SCREEN_OFF_MS) {
        display.powerOff();
    } else if (idleNow >= SCREEN_DIM_MS) {
        display.dim();
    }

    // Render display at 10 Hz
    if ((millis() - lastRender) >= DISPLAY_PERIOD_MS) {
        lastRender = millis();
        display.render();
    }

    delay(10);
}

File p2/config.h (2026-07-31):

// Roam P2 — Pin definitions, button mapping, and timing constants
// Seeed XIAO nRF52840 Sense (nRF52840 + BLE 5.0)

#pragma once

#include <Arduino.h>

// --- I2C (OLED) ---
#define PIN_SDA        D4
#define PIN_SCL        D5
#define I2C_FREQ       400000

// --- Buttons (active low, internal pull-up) ---
#define PIN_BTN_INDEX  D0
#define PIN_BTN_MIDDLE D1
#define PIN_BTN_RING   D2
#define PIN_BTN_PINKY  D3
#define NUM_BUTTONS    4

static const uint8_t BUTTON_PINS[NUM_BUTTONS] = {
    PIN_BTN_INDEX, PIN_BTN_MIDDLE, PIN_BTN_RING, PIN_BTN_PINKY
};

// --- Scroll buttons (thumb, active low, internal pull-up) ---
#define PIN_BTN_SCROLL_FWD  D8
#define PIN_BTN_SCROLL_BACK D9

// --- Display reset ---
// SH1106 module has no reset pin; SSD1309 used D10
#define PIN_DISPLAY_RST     U8X8_PIN_NONE

// --- Haptic motor (NPN via 1kΩ) ---
#define PIN_MOTOR      D6

// --- Status LED ---
#define ROAM_LED_PIN   D7

// --- Battery ---
// XIAO nRF52840 has built-in battery management via JST connector.
// Battery voltage readable via internal ADC channel.
// PIN_VBAT is defined by the Seeed board core — no need to redefine it.
#define VBAT_ENABLE_PIN    -1         // No enable pin needed on XIAO

// --- Timing ---
#define DEBOUNCE_MS       50
#define LONG_PRESS_MS     600
#define DOUBLE_TAP_MS     300
#define BUTTON_POLL_US    10000   // 100 Hz
#define DISPLAY_PERIOD_MS 100     // 10 Hz
#define BATTERY_PERIOD_MS 60000   // Every 60s
#define ACTION_FADE_MS    3000    // Action text display duration
#define SCREEN_DIM_MS     10000   // Dim after 10s inactivity
#define SCREEN_OFF_MS     15000   // Power off after 15s inactivity

// --- Display ---
// 1.3" 128x64 I2C OLED (SH1106)
#define SCREEN_WIDTH      128
#define SCREEN_HEIGHT     64
#define DISPLAY_TYPE      U8G2_SH1106_128X64_NONAME_F_HW_I2C
#define DISPLAY_I2C_ADDR  0x3C

// --- Action types ---
enum ActionType : uint8_t {
    ACTION_NONE = 0,
    ACTION_DICTATION,           // macOS: Consumer key 0x00CF
    ACTION_DICTATION_ANDROID,   // Android: Consumer key 0x00D8
    ACTION_TMUX_PANE,           // Ctrl+B, o
    ACTION_CYCLE_MODE,          // Shift+Tab
    ACTION_BLE_SWITCH,          // Disconnect + re-advertise
    ACTION_APPROVE_YES,         // y + Enter
    ACTION_APPROVE_ALWAYS,      // Tab + Enter
    ACTION_REJECT_ESCAPE,       // Escape (also Android Back)
    ACTION_KILL_PROCESS,        // Ctrl+C
    ACTION_ENTER,               // Enter
    ACTION_HOME_ANDROID,        // Meta+H (Android home)
    ACTION_RECENTS_ANDROID,     // Consumer 0x029F (Android app switcher)
    ACTION_LED_TOGGLE,          // Toggle status LED on/off
    ACTION_PROFILE_TOGGLE,      // Switch Mac ↔ Android
    ACTION_SCROLL_FWD,          // Next page / newer message
    ACTION_SCROLL_BACK,         // Prev page / older message
    ACTION_CLEAR_MSGS,          // Clear message queue (scroll fwd long press)
};

// Button index → short/long/double-tap action mapping
struct ButtonMapping {
    ActionType shortPress;
    ActionType longPress;
    ActionType doubleTap;
};

// --- Profiles ---
#define ROAM_PHONE_RELAY_MODE 1

enum Profile : uint8_t {
    PROFILE_MAC = 0,
    PROFILE_ANDROID,
    PROFILE_COUNT
};

static const ButtonMapping PROFILE_MAPS[PROFILE_COUNT][NUM_BUTTONS] = {
    // PROFILE_MAC
    {
        { ACTION_DICTATION,     ACTION_TMUX_PANE,      ACTION_NONE },           // Index
        { ACTION_ENTER,         ACTION_APPROVE_YES,    ACTION_APPROVE_ALWAYS }, // Middle
        { ACTION_REJECT_ESCAPE, ACTION_KILL_PROCESS,   ACTION_LED_TOGGLE },     // Ring
        { ACTION_CYCLE_MODE,    ACTION_BLE_SWITCH,     ACTION_PROFILE_TOGGLE }, // Pinky
    },
    // PROFILE_ANDROID
    {
        { ACTION_DICTATION_ANDROID, ACTION_TMUX_PANE,      ACTION_NONE },           // Index
        { ACTION_ENTER,             ACTION_APPROVE_YES,    ACTION_APPROVE_ALWAYS }, // Middle
        { ACTION_REJECT_ESCAPE,     ACTION_KILL_PROCESS,   ACTION_LED_TOGGLE },     // Ring
        { ACTION_CYCLE_MODE,        ACTION_BLE_SWITCH,     ACTION_PROFILE_TOGGLE }, // Pinky
    },
};

static const char* PROFILE_NAMES[PROFILE_COUNT] = { "Mac", "Android" };

// Active profile — set by connect_callback based on peer MAC
extern volatile Profile activeProfile;

// Convenience accessor for current button map
#define BUTTON_MAP  PROFILE_MAPS[activeProfile]
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

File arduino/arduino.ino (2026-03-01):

// Roam — Arduino-pico BLE HID Firmware
// Pimoroni Pico Plus 2 W (RP2350 + CYW43439)
// Single-core build — BLE + buttons + actions + display
// Board: rp2040:rp2040:pimoroni_pico_plus_2w:ipbtstack=ipv4btcble

#include <KeyboardBLE.h>
#include <PicoBluetoothBLEHID.h>
#include "config.h"
#include "buttons.h"
#include "actions.h"
#include "display.h"
#include "battery.h"
#include "ble_text.h"

static ButtonManager buttons;
static Display display;
static Battery battery;

void setup() {
    Serial.begin(115200);
    delay(1000);

    pinMode(ROAM_LED_PIN, OUTPUT);
    pinMode(PIN_MOTOR, OUTPUT);
    digitalWrite(PIN_MOTOR, LOW);

    Serial.println("Starting BLE keyboard...");
    KeyboardBLE.begin("Roam", "Roam");
    Serial.println("BLE started, advertising as 'Roam'");

    // Add custom GATT text service (must be after KeyboardBLE.begin)
    bleText.begin();

    Serial.println("Initializing display...");
    display.begin();
    Serial.println("Display init done");

    display.setBleConnected(false);
    battery.begin();
    buttons.begin();
}

void loop() {
    static uint32_t lastStatus = 0;
    static uint32_t lastRender = 0;
    static bool wasConnected = false;
    bool connected = PicoBluetoothBLEHID.connected();

    // LED: solid when connected, blink when advertising
    static uint32_t lastBlink = 0;
    static bool ledState = false;
    if (connected) {
        digitalWrite(ROAM_LED_PIN, HIGH);
    } else {
        if (millis() - lastBlink > 500) {
            ledState = !ledState;
            digitalWrite(ROAM_LED_PIN, ledState ? HIGH : LOW);
            lastBlink = millis();
        }
    }

    // BLE status change
    if (connected != wasConnected) {
        wasConnected = connected;
        display.setBleConnected(connected);
    }

    // Print BLE status every 2 seconds
    if (millis() - lastStatus > 2000) {
        Serial.printf("BLE: %s\n", connected ? "CONNECTED" : "advertising...");
        lastStatus = millis();
    }

    // Poll buttons
    ActionType action = ACTION_NONE;
    buttons.poll(action);

    if (action != ACTION_NONE) {
        display.wake();  // Any button press wakes screen
        if (action == ACTION_SCROLL_FWD || action == ACTION_SCROLL_BACK) {
            // Local action — no HID, no connection required
            if (action == ACTION_SCROLL_FWD) display.scrollFwd();
            else display.scrollBack();
            display.wake();
            digitalWrite(PIN_MOTOR, HIGH);
            delay(40);
            digitalWrite(PIN_MOTOR, LOW);
            Serial.printf("action: scroll %s\n",
                          action == ACTION_SCROLL_FWD ? "fwd" : "back");
        } else if (connected) {
            executeAction(action);

            // Short motor buzz
            digitalWrite(PIN_MOTOR, HIGH);
            delay(80);
            digitalWrite(PIN_MOTOR, LOW);

            display.showAction(ACTION_NAMES[action]);
            Serial.printf("action: %s\n", ACTION_NAMES[action]);
        } else {
            Serial.printf("action: %s (not connected)\n", ACTION_NAMES[action]);
        }
    }

    // Battery monitor (every 60s)
    if (battery.shouldRead()) {
        battery.read();
        display.setBatteryPercent(battery.percent());
        // USB power detection — battery icon handles visual feedback
    }

    // Check for BLE text pushes
    if (bleText.hasNewText()) {
        const char* text = bleText.getText();
        display.pushMessage(text);
        digitalWrite(PIN_MOTOR, HIGH);
        delay(60);
        digitalWrite(PIN_MOTOR, LOW);
        delay(80);
        digitalWrite(PIN_MOTOR, HIGH);
        delay(60);
        digitalWrite(PIN_MOTOR, LOW);
        Serial.printf("ble_text: \"%s\"\n", text);
    }

    // Screen sleep timer
    uint32_t idle = millis() - display.lastActivityTime();
    if (idle >= SCREEN_OFF_MS) {
        display.powerOff();
    } else if (idle >= SCREEN_DIM_MS) {
        display.dim();
    }

    // Render display at 10 Hz
    if ((millis() - lastRender) >= DISPLAY_PERIOD_MS) {
        lastRender = millis();
        display.render();
    }

    delay(10);
}

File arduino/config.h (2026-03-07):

// Roam — Pin definitions, button mapping, and timing constants
// Pimoroni Pico Plus 2 W (RP2350 + CYW43439)

#pragma once

#include <Arduino.h>

// --- I2C (OLED) ---
#define PIN_SDA        4
#define PIN_SCL        5
#define I2C_FREQ       400000

// --- Buttons (active low, internal pull-up) ---
#define PIN_BTN_INDEX  10
#define PIN_BTN_MIDDLE 11
#define PIN_BTN_RING   12
#define PIN_BTN_PINKY  13
#define NUM_BUTTONS    4

static const uint8_t BUTTON_PINS[NUM_BUTTONS] = {
    PIN_BTN_INDEX, PIN_BTN_MIDDLE, PIN_BTN_RING, PIN_BTN_PINKY
};

// --- Haptic motor (NPN via 1kΩ) ---
#define PIN_MOTOR      15

// --- Status LED (via 100Ω) ---
#define ROAM_LED_PIN   16

// --- Battery ADC ---
#define PIN_BATTERY    29   // ADC3 — VSYS/3
#define PIN_GP25       25   // Must be HIGH during ADC read (CYW43 SPI)

// --- Timing ---
#define DEBOUNCE_MS       50
#define LONG_PRESS_MS     600
#define DOUBLE_TAP_MS     300   // Max gap between taps for double-tap
#define BUTTON_POLL_US    10000   // 100 Hz
#define DISPLAY_PERIOD_MS 100     // 10 Hz
#define BATTERY_PERIOD_MS 60000   // Every 60s
#define ACTION_FADE_MS    3000    // Action text display duration
#define SCREEN_DIM_MS     10000   // Dim after 10s inactivity
#define SCREEN_OFF_MS     30000   // Power off after 30s inactivity

// --- Display ---
#define SCREEN_WIDTH   128
#define SCREEN_HEIGHT  64
#define DISPLAY_TYPE      U8G2_SH1106_128X64_NONAME_F_HW_I2C
#define DISPLAY_I2C_ADDR  0x3C
#define PIN_DISPLAY_RST   U8X8_PIN_NONE  // SH1106 — no reset pin wired

// --- Action types ---
enum ActionType : uint8_t {
    ACTION_NONE = 0,
    // Index button
    ACTION_DICTATION,       // Consumer key 0x00CF
    ACTION_TMUX_PANE,       // Ctrl+B, o
    // Middle button
    ACTION_CYCLE_MODE,      // Shift+Tab
    ACTION_BLE_SWITCH,      // Disconnect + re-advertise
    // Ring button
    ACTION_APPROVE_YES,     // y + Enter
    ACTION_APPROVE_ALWAYS,  // Tab + Enter
    // Pinky button
    ACTION_REJECT_ESCAPE,   // Escape
    ACTION_KILL_PROCESS,    // Ctrl+C
    // Double-tap
    ACTION_ENTER,           // Enter only (no y prefix)
    // Scroll (dedicated buttons on P2, mapped to double-tap for P1 testing)
    ACTION_SCROLL_FWD,      // Next line (short) or next page (long)
    ACTION_SCROLL_BACK,     // Prev line (short) or prev page (long)
};

// Button index → short/long action mapping
struct ButtonMapping {
    ActionType shortPress;
    ActionType longPress;
    ActionType doubleTap;
};

static const ButtonMapping BUTTON_MAP[NUM_BUTTONS] = {
    { ACTION_DICTATION,     ACTION_TMUX_PANE,      ACTION_NONE },           // Index
    { ACTION_ENTER,         ACTION_APPROVE_YES,    ACTION_APPROVE_ALWAYS }, // Middle
    { ACTION_REJECT_ESCAPE, ACTION_KILL_PROCESS,   ACTION_NONE },           // Ring
    { ACTION_CYCLE_MODE,    ACTION_BLE_SWITCH,     ACTION_NONE },           // Pinky
};

// Human-readable action names for display
static const char* ACTION_NAMES[] = {
    "",              // ACTION_NONE
    "Dictation",     // ACTION_DICTATION
    "Tmux Pane",     // ACTION_TMUX_PANE
    "Cycle Mode",    // ACTION_CYCLE_MODE
    "BLE Switch",    // ACTION_BLE_SWITCH
    "Approve",       // ACTION_APPROVE_YES
    "Always",        // ACTION_APPROVE_ALWAYS
    "Escape",        // ACTION_REJECT_ESCAPE
    "Kill",          // ACTION_KILL_PROCESS
    "Enter",         // ACTION_ENTER
    "",              // ACTION_SCROLL_FWD (handled locally)
    "",              // ACTION_SCROLL_BACK (handled locally)
};

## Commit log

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2026-02-26 Fix floating OLED standoffs — add support ribs to case floor
    Standoffs were disconnected from the shell due to 15° tilt rotation.
    Added hull ribs from each standoff base down to the floor plane.
    [roam_case.scad]
2026-02-26 Fix lid gap — flat fill now extends to full thickness
    The registration lip was disconnected from the lid body due to a
    1.25mm gap. Flat fill now reaches lid_thickness so it connects
    to the lip above.
    [roam_lid.scad]
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2026-02-26 Fix button wells — extend through dome surface
    Wells were buried inside the dome due to underestimated surface height.
    Now cut from body_height - well_depth through the top, guaranteeing
    visible recesses on the dome surface.
    [roam_case.scad]
2026-02-26 Curved button arc matching natural finger splay
    Replaced 2x2 grid with parabolic arc following left hand reaching
    to right forearm. Index furthest/outer, pinky closest/inner. Moved
    OLED further toward wrist to clear the button zone.
    [roam_case.scad]
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2026-02-26 Redesign dome for supinated forearm interaction model
    Asymmetric dome with ridge offset toward inner (body) edge. Gentle
    outer slope holds OLED screen (visible when pronated). Steeper inner
    slope holds 4 buttons in a line along the forearm axis. Left hand
    makes T-shape to reach over ridge and press buttons. Switch moved
    to elbow end wall.
    [roam_case.scad]
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2026-02-27 Replace strap mounting with velcro-on-neoprene system
    Removed all band slots and bridge loops from case and lid. Lid now
    has a flush velcro recess (70x38mm) on the bottom for adhesive hook
    velcro. Device attaches to a neoprene forearm band via velcro.
    Also: fixed screw posts (shorter on inner-side corners to stay inside
    asymmetric dome), removed TPU pad file, added .gitignore for STLs.
    [common.scad, roam_case.scad, roam_lid.scad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]
2026-02-27 Open bottom case, LiPo SHIM, remove slide switch
    Major housing rework:
    - Case bottom is now open (lid closes it with M2 screws)
    - Screw post inserts face downward, accessible from open bottom
    - Pico standoffs account for SHIM+Pico stack height (~11mm)
    - USB-C cutout repositioned for stack height
    - Removed slide switch — LiPo SHIM has built-in power button
    - Removed all switch params from common.scad
    - Added SHIM dimensions to common.scad
    - Vents moved to side walls (bottom is open)
    - Updated BOM: Pimoroni Pico Plus 2W + LiPo SHIM
    [common.scad, roam_case.scad]
2026-02-27 Fix OLED window height — 30mm not 15mm
    The 1.3" SH1106 display is nearly square (128x64 with tall pixels).
    Window was half the correct height.
    [common.scad]
2026-02-27 Fix OLED cutout — deeper cutting volume to penetrate dome wall
    The tilted cutout cube was too thin to fully penetrate the curved
    dome surface, producing a narrow slit instead of a full window.
    Increased cut depth to 20mm to guarantee clean penetration.
    [roam_case.scad]
2026-02-27 Housing redesign: base-as-chassis architecture
    Flip responsibilities so the base plate is the electronics chassis
    (Pico standoffs, switch pedestals, battery cradle) and the dome is
    a pure ergonomic shell (button wells, OLED window, screw bosses).
    New files:
    - roam_base.scad — flat plate with all mounting features on top, zero supports
    - roam_dome.scad — asymmetric hull with only subtractive cutouts + rim bosses
    Key changes to common.scad:
    - Added base_plate_thick, pico_y_offset, battery offsets, switch_pedestal_height
    - Moved screw_positions here (shared between base and dome)
    - Added button_positions and layout params (shared between base and dome)
    Old files (roam_case.scad, roam_lid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
    [common.scad, roam_base.scad, roam_dome.scad]
2026-02-27 Fix dome: OLED window, floating geometry, screw boss connections
    Three main fixes to roam_dome.scad:
    1. OLED position: moved to (y=10, z=15, tilt=25°) from (y=4, z=9, tilt=20°).
    Old values placed the cutout entirely inside the dome — it never reached
    the outer surface. New values match the proven positions from roam_case.scad.
    2. OLED mount: wrap all geometry in intersection(dome_outer()) to clip
    any protrusion above the dome surface. Boss pads use tall cylinders
    that span through the dome wall, ensuring solid structural connection.
    Upper pegs that would protrude above the slope get cleanly trimmed.
    3. Screw bosses: add 2mm connecting ribs from each boss to the nearest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
    [roam_dome.scad]
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2026-02-27 Firmware bring-up: graceful OLED fallback, battery sanity checks, flash fix
    Display init now scans I2C bus and skips gracefully when OLED isn't
    connected. Battery reader averages 3 samples and handles nonsensical
    VSYS readings on Pimoroni Pico Plus 2 W. Makefile flash target properly
    creates lib/ subdirectory on the Pico filesystem.
    Verified on hardware: all subsystems init cleanly, BLE advertises as
    "Roam", buttons poll correctly, LED blinks.
    [battery.py, display.py]
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2026-02-28 Add double-tap support, fix hardware issues, update docs
    Firmware changes:
    - Add double-tap button event (ring double-tap = Enter only)
    - Simplify to single-core build (dual-core disabled until OLED wired)
    - Fix GP25 conflict: remove CYW43 SPI pin toggling that killed BLE
    - Fix display init: release I2C bus when no OLED connected
    - Add debug test sketch (test_buttons/)
    Hardware doc corrections from build session:
    - Motor needs VBUS (5V) not 3V3 — coin motors won't spin through transistor at 3.3V
    - LED resistor is 220Ω not 100Ω, use plain LEDs not fast-flashing RGB
    - GP25 is off-limits (CYW43 wireless SPI)
    - BLE re-pairing required after every firmware flash
    - Update CLAUDE.md to reflect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
    [arduino.ino, battery.cpp, buttons.h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]
2026-02-28 Add OLED display support and I2C test sketch
    - Re-enable display in single-core firmware (display.begin + render at 10Hz)
    - Show BLE status and last action on screen
    - Add I2C bus scanner test sketch for debugging
    - Screen not yet working (modules may be damaged from 5V exposure)
    [arduino.ino]
2026-02-28 Fix OLED display: 5V VCC required, HW_I2C works with BLE
    Root cause: SH1106 OLED charge pump needs 5V on VCC — at 3.3V the I2C
    bus responds (device at 0x3C) but the panel doesn't light up. Hours of
    debugging U8g2 SW_I2C, raw I2C, and library conflicts were all chasing
    the wrong problem.
    Key findings:
    - U8g2 HW_I2C (Wire) works alongside btstack BLE when screen has 5V
    - U8g2 SW_I2C (bit-bang) is broken on RP2350 — never use it
    - Wire + BLE only hung at 3.3V because the screen wasn't responding,
    causing Wire to block indefinitely — works fine at 5V
    - BOOTSEL mode can leave OLED I2C bus stuck — power-cycle screen after flash
    - Rapid I2C data writes need delays between transactions on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
    [arduino.ino, display.cpp, display.h]
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2026-02-28 Add full-screen message mode and index double-tap toggle
    BLE text now takes over the entire display with word wrap.
    Double-tap index toggles between message and status screen.
    Short haptic buzz on toggle (no HID, works without connection).
    [arduino.ino, config.h, display.cpp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]
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2026-02-28 Fix P2 build: correct Bluefruit API, platform guards, add P2 pinout docs
    - actions.cpp: Use keyboardReport(modifier, keycodes[6]) for modifier
    combos, keyPress(char) for ASCII — BLEHidAdafruit API differs from P1
    - display.cpp: Platform guard for Wire.setSDA/setSCL (RP2040) vs
    Wire.setPins (nRF52)
    - led.cpp: Guard analogWriteFreq/Range behind ARDUINO_ARCH_RP2040
    - battery.cpp: AR_INTERNAL instead of AR_INTERNAL_3_6 (Seeed nRF52 core)
    - Add hardware/p2-pinout.md with XIAO nRF52840 pin allocation and
    SSD1309 2.42" OLED I2C configuration instructions
    - Add build/ and .DS_Store to .gitignore
    Both P1 and P2 build clean.
    [battery.cpp, display.cpp, led.cpp]
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2026-03-05 P2 flat housing, scroll buttons, updated hardware docs
    - Add flat wrist-mounted housing (slim + large) with print-in-place
    spring buttons, OLED ceiling posts, attachment ring, ROAM emboss
    - Add scroll button polling (D8/D9) to P2 firmware
    - Update wiring diagram for battery + switch power (no VUSB)
    - Add button command map with actions, timing, haptic patterns
    - Add OpenSCAD component library and build123d STEP export
    - Correct SH1106 voltage info (works on LiPo, not 5V-only)
    [common.scad, roam_base.scad, roam_button_cap.scad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]
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2026-03-07 Scroll UX overhaul, button remap, roam-msg chunking tool
    - Chronological message numbering (m1=oldest, mN=newest)
    - Consistent scroll direction: up=advance (higher numbers), down=back
    - Page vs message indicators: p1/3 for pages, m2/5 for messages
    - Ring button: Enter=short, Approve(y+Enter)=long, Always=double-tap
    - Clear unused double-tap scroll mappings from Index/Middle
    - Add roam-msg wrapper: chunks long messages at word boundaries
    [config.h, display.cpp]
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2026-03-07 Fix ring buffer wrap bug, bump to 100 messages, remap buttons
    Bug: uint8_t _msgHead underflow in _viewedMsgIndex() when head
    wraps to 0 after filling the ring. Caused wrong slot to be displayed
    for all messages after the 10th. Fixed by casting to int.
    Ring buffer bumped from 10 to 100 messages (12.8KB, 12% RAM).
    Button remap by usage frequency: Middle=Enter/Approve (most used),
    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
    [display.cpp, display.h]
2026-03-07 Add dual profiles (Mac/Android), fix battery, LED sleep, IMU sensitivity
    - Dual device profiles with auto-detect by learned MAC on BLE connect
    - Manual profile toggle via double-tap Pinky (both profiles)
    - Android actions: dictation (0x00D8), home (Meta+H), recents (0x029F)
    - BLE Switch removes bond for current peer (prevents auto-reconnect)
    - Fix battery reading: enable VBAT divider (P0.14 LOW), correct ratio (1510/510)
    - Profile name shown in OLED status bar center
    - LED off on sleep, LED toggle via Ring double-tap
    - IMU wake threshold 125mg -> 375mg (less sensitive)
    - Screen off 30s -> 15s
    [battery.cpp, config.h, display.cpp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]
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2026-08-12 roam-touch bracer: 4 mm compliant-pad relief on every rib face
    A forearm is not a cylinder -- it tapers, and its cross-section changes as
    it pronates, so a rigid shell fitted to one arm position binds in another.
    Rigid stays only under the phone, where the screen must be flat; the skin
    interface becomes foam/TPU. Ribs are now carved by a cylinder FOAM larger
    than the arm about an axis dropped to match, so every rib face stands 4 mm
    proud of skin while the crown still clears by GAP.
    Makes ARM_R nominal rather than critical -- the pad absorbs several mm, so
    nobody has to measure a forearm to print this. Rib drop 16.38 -> 15.05 mm.
    15/15 probes pass, watertight, single shell.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
    [bracer.step, bracer.stl]
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2026-08-12 roam-touch bracer: real bezel, sensor apertures, placed button openings
    Front face now closes down to the display instead of exposing the phone's
    own bezel -- the housing reads as the device rather than a tray with a
    phone in it. Adds earpiece, front camera and proximity/ambient apertures
    (covering proximity keeps the screen lit against your face), and replaces
    the single 55 mm side slot with two openings placed on the real button
    positions, power above volume.
    Feature coordinates come from File:Pixel_(2016).svg on Wikimedia, authored
    at 1 unit = 1 mm with an outline matching the spec body exactly. Internal
    features are traced, so every aperture carries 0.6 mm of margin and wants
    checking a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
    [bracer.step, bracer.stl]
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2026-08-12 roam-touch bracer: print-in-place button plungers and a removable end cap
    Buttons are captured plungers, not flexures -- nothing to fatigue and
    orientation-agnostic. They print loose in their bores (3 bodies in the
    STL) and stay captive: the flange cannot pass the outer bore going out,
    the phone's own edge stops them going in. Flange sits flush with the
    pocket wall because the Pixel's buttons already protrude into most of
    the 0.4 mm side clearance.
    End cap is a U-section that slips over the outside and snaps into two
    dimples -- nothing intrudes into the pocket, no tool to remove it. It
    carries a USB-C aperture because the port is on this same end; without
    it the cap would come off every cha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
    [bracer.step, bracer.stl, bracer_endcap.step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]
2026-08-12 roam-touch bracer: strap moves under the ribs, cones not spheres, flared USB
    Strap wings are gone. They made the device 91 mm wide for no structural
    reason and were also what the end cap fouled -- it could never have gone
    on. The webbing now runs in a channel cut into each rib's arm-facing
    face, bridged by two retaining bars, so the device is tray-width:
    91.1 -> 75.1 mm. Ribs thickened 14 -> 28 mm to host it, which also
    spreads load on the arm.
    Snap features are truncated cones. Cylinders present a sharp edge square
    to the direction of travel and will not go on; spheres cam correctly but
    ram a curved surface into a flat one and OCCT emits a non-manifold shell
    -- removing them took both part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
    [bracer.step, bracer.stl, bracer_endcap.step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]
2026-08-12 roam-touch end cap: USB-C shaped aperture, lofted flare, correct height
    Cuts the plug's actual stadium profile (8.34 x 2.56 + ~1 mm) rather than a
    generic rectangle, flared 5 mm per side on the outer face and lofted down
    to it -- so a fat overmould still reaches a port sitting behind a 2.4 mm
    plate, and it reads as a feature instead of a punched hole.
    Two real fixes along the way: the aperture was 2 mm too LOW (centred near
    the tray floor instead of mid phone thickness, where the port actually is),
    and the flare has to be a loft -- OCCT's extrude_taper throws
    Standard_TypeMismatch on a rounded profile at ~64 deg, and the loft plane
    needs x_dir pinned or the flare comes out rotated 90 deg.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
    [bracer.step, bracer_endcap.step, bracer_endcap.stl]
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2026-08-12 roam-touch end cap: trough goes near edge to edge, centred on the face
    The mouth was centred on the PORT, but the face is not symmetric about it --
    the face spans Z -0.3..15.7 (centre 7.7) while the port sits at 6.45. That
    left 3.75 mm at the top and 1.25 at the bottom and read as a mistake. The
    mouth is now face-centred with a 0.8 mm rim all round; lofting it to the
    port-centred throat skews the scoop slightly, which is the intent.
    [bracer.step, bracer_endcap.step, bracer_endcap.stl]
2026-08-12 roam-touch end cap: 6 mm plate so the trough has material to live in
    At 2.4 mm the full-face scoop met the outer face at a feather edge in the
    corners -- visible in the viewer, not in the probes. Fixed with material
    rather than a slicer setting: a 6 mm plate gives the trough real depth, a
    proper rim and a gentler taper that prints cleanly, and it reads chunkier,
    which is the direction we want. Cap is 16 mm long, 9 g.
    [bracer.step, bracer_endcap.step, bracer_endcap.stl]
2026-08-12 roam-touch end cap: bottom plate to match the top -- a full collar
    Four walls instead of a U. The tray now slides into a closed rectangular
    mouth, so loading and unloading reads like a magazine change rather than
    clipping a lid on. Side effect worth having: the snap tongues are rooted
    at both ends instead of hanging off one, and the face is now near enough
    centred on the port that the trough sits square in it. 12 g.
    [bracer.step, bracer_endcap.step, bracer_endcap.stl]
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2026-08-12 roam-touch: jack in the button-side quartile, bottom speakers, sloped bezel
    Three corrections from the owner measuring the actual phone:
    - ⚠️ The 3.5 mm jack is NOT centred on the top edge -- it sits in the
    button-side quartile. The Wikimedia SVG only draws the FACE, so the
    centred notch was an assumption and it was wrong. The harness caught the
    move, which is what it is for.
    - Bottom edge carries the speaker and mic either side of the USB port, so
    the cap plate gets apertures for both. A solid plate would have muffled
    the only output the device has.
    - Screen aperture is lofted rather than cut straight: 1.5 mm wider at the
    top face, closing down to the display, so the bezel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
    [bracer.step, bracer.stl, bracer_endcap.step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]
2026-08-12 roam-touch bracer: TILT parameter, screen angled toward the face
    Worn flat the display points at the ceiling. TILT (20 deg) rotates the ARM
    CUT rather than the tray, so the tray, pocket and every aperture stay in a
    clean axis-aligned frame and only the rib profile changes.
    ⚠️ HANDED -- positive drops the button side. Flip the sign for the other arm.
    ⚠️ It also demonstrates why the form has to change: 20 deg needs a 25.7 mm
    stand-off on the low side, so the tray now perches on a big asymmetric
    wedge. That volume is unavoidable once a flat screen is tilted on a round
    arm; the open question is whether it stays exposed structure or gets
    enclosed in the body. Enclosing it is next.
    Co-A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
    [bracer.step, bracer.stl, bracer_endcap.step]
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2026-08-12 roam-touch bracer: faceted outer body enclosing the tilt wedge
    The tray no longer perches on two open ribs. A low-poly hull runs the length
    of the arm, flush with the tray sides at the belt line and flaring out below
    it, with the tilted arm saddle cut through its underside. Every hull facet is
    a plane parallel to the arm axis, so the whole outer body is vertical in the
    print orientation -- the styling costs nothing in support.
    Shelled to a 2.0 mm skin over a cavity that is open at the nose, so the floor
    vents exhaust into it and out through louvres in the deep flank instead of
    into a blind box. Solid it would be 224 g; it lands at 82 g, 2 g under the
    open-rib version, and 4.2 mm shorter.
    T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
    [bracer.step, bracer.stl, bracer_endcap.step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]
2026-08-12 roam-touch bracer: the cap becomes the nose, and the dead volume carries cards
    THE CAP. It was a rectangular collar sized to the bare tray, butted against a
    faceted body with a belt line, chines and a raked nose. It read as a different
    object bolted on, and the hull stopped 13 mm short of it, leaving an open step.
    The hull now runs the full length and the last 10 mm of it steps IN by the
    cap's wall thickness -- but only BELOW THE BELT LINE, because above it the
    section is flush with a 2.4 mm frozen pocket wall and there is nothing there to
    rebate. So the collar fills that step and the cap's outer surface IS the hull's
    section: same width, same belt, same chines, no ledge at the joint. The b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
    [assembly.stl, bracer.step, bracer.stl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]
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2026-08-12 roam-touch bracer: raised visor, 3 mm bevels, ribs instead of louvres
    Against the Pip-Boy 3000 reference now in cad/ref/.
    VISOR. The screen sits in a well with a hood proud around it. The hood is NOT
    a uniform ring, and the asymmetry is forced rather than styled: printed on the
    hand end, +Y is down, so the elbow brow's screen-side face has to rake back at
    45 deg or shallower while the hand brow's can be a plain wall. Notch through
    the hand brow, because in the reference the hood line is broken and that one
    detail stops it reading as a picture frame.
    ★ WELL_HW is DERIVED, not chosen. The frozen bezel already cuts a 32 deg
    sight cone (BEZEL_CHAM over LIP_H); putting the well's wall on that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
    [assembly.stl, bracer.step, bracer.stl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]
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2026-08-12 roam-touch bracer: orientation fixed at the root, power pack, cap without a port
    ORIENTATION. The model called Y=0 the elbow. It is the WRIST -- the cap, USB-C
    and speakers point at the hand, because that is where his free hand reaches to
    uncap it and pull a card. Getting the end wrong flipped X, which flipped every
    conclusion built on it. Re-derived from scratch:
    +Y toward the elbow, +Z out of the screen, so +X = Y x Z = toward the
    MIDLINE on a right arm. The screen must face +X, and the screen always
    faces the SHALLOW flank, so TILT must be NEGATIVE. It was +20, which
    pointed the display outboard, away from him.
    Two signs changed and nothing else: TILT to negative, and th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
    [assembly.stl, bracer.step, bracer.stl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]
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2026-08-12 Low poly means every surface, not the sides
    The previous pass tessellated the flanks and the cuff and left everything a
    section loft cannot reach exactly as built: the deck round the screen, the
    guard's outer wall, the tray's own side walls, the two crest ramps and both
    end faces. Single planes, the largest 2883 mm2. Owner: "still looking at a
    flat top wall".
    The facet census reported green throughout, because it only ever looked below
    the belt and outside the payload box -- it was scoped to the surface it had
    already fixed. A check that passes on a part the owner can see is broken is
    worse than no check, so it now covers the WHOLE EXTERIOR SKIN of both solids,
    via ray-escape visibility min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
    [bracer.step, bracer.stl, bracer_endcap.step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]
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2026-08-13 Face features corrected against a printed part
    The comment on these constants asked for exactly this: "treat them as
    +/-1 mm and check against the real phone once a print exists." The print
    exists, and the trace was out by up to 4 mm.
    screen aperture in 2 mm left/right, 4 mm top/bottom
    front camera right 4, down 3
    proximity window right 1.5, down 3
    earpiece unchanged, confirmed good
    buttons unchanged -- "perfect, they feel great, first try"
    The corrections are local. My first pass moved the earpiece too and
    shifted things that did not need shifting; wrong.
    Also stops the harness lying about it. verify_bracer.py hand-mirrors the
    model's constants, so moving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
    [bracer.step, bracer.stl, bracer_endcap.step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]
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2026-08-13 ROAM step 1: the phone housing, on a flat base
    New model rather than a fork of bracer.py, and the reason is structural.
    bracer.py exists to make the housing conform to the arm -- tilted arm cut,
    hull skirt, belt, strap slots, tessellated flanks. A flush half-circle
    sleeve does that job now, so all of it leaves the housing and the base
    becomes a flat mounting face. What carries over is the only part that has
    to be exact: pocket, apertures, buttons, ports.
    75.1 x 147.0 x 13.4, 53 g -- the frozen tray dimensions, unchanged.
    Carries today's corrections, measured off a printed part: screen in 2 mm
    L/R and 4 mm T/B, camera right 4 down 3, prox right 1.5 down 3, earpiece
    and buttons untouched. Th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
    [roam_step1.step, roam_step1.stl]
2026-08-13 ROAM step 2: the pack tube
    His cylindrical pack is what unlocked this. A slab pack's short edge is ~67 mm
    whatever the brand, which was forcing a 70 mm visor wall; a cylinder is 25.4 mm
    in every direction and its long axis runs along the forearm -- the one direction
    already spent on the phone.
    29.4 mm bore (1 in + 2 mm a side), 111.7 long, OD 34.4, loading from the same
    end as the phone so both ports land in one cap cavity and the lead between them
    is a jumper rather than a cable running the length of the housing.
    107.2 x 147.0 x 34.4, 96 g, one watertight solid, base still flat.
    X is set by the pocket, not by looks: the bore may not eat the tray wall, so the
    minimum is pocket edge + a re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
    [roam_step2.step, roam_step2.stl]
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
